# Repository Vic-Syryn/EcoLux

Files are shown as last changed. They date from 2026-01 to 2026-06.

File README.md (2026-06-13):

# EcoLux
Ecolux, een slim product dat energieverlies beperkt 

🛠️ Built by ``Viktor Caluwaert``, ``Yenthe Bode`` & ``Vic Syryn``   
🔥 Supervised by ``prof. dr. Bas Baccarne``, ``Yannick Christiaens`` & ``Wouter Devriese``    
🌱 Grown at ``Ghent University`` 🏛️ ``Industrial Design Engineering`` ([project overview](https://github.com/basbaccarne/human-centered-design))       

13/11/2025  

## Samenvatting
EcoLux is een slim energiefeedbacksysteem dat bewuste gezinnen helpt om verborgen energieverlies in huis sneller op te merken en er eenvoudiger op te reageren. Uit het gebruikersonderzoek blijkt dat het zelfden voorkomt dat iedereen in het gezin betrokken is bij energiebesparing, dat sluipverbruik vaak onbewust blijft aanstaan en dat bestaande slimme oplossingen vaak te technisch, app-gericht of datagedreven aanvoelen. EcoLux wil daarom energieverlies zichtbaar maken op een laagdrempelige, passieve en begrijpelijke manier.

Het project evolueerde van een algemeen concept rond energiezuinig renoveren naar een concreet fysiek product voor energiebewuste gezinnen: een subtiele slimme bloempot die als hoofdstation in het interieur staat. Het systeem combineert een geïntegreerd touchscreen, een visuele plattegrondinterface, lichtfeedback en slimme koppelingen met toestellen in huis. Wanneer een toestel energie verspilt, toont EcoLux duidelijk in welke ruimte het energieverlies zich bevindt en kan de gebruiker snel ingrijpen of het toestel laten uitschakelen. De instellingen van de gebruiker bepalen wanneer de EcoLux een toestel als energieverspiller beschouwt.

Door iteratieve gebruikerstesten werd het ontwerp stap voor stap verfijnd. 

Met EcoLux willen we gezinnen helpen om energieverspilling te verminderen zonder extra complexiteit toe te voegen aan hun dagelijkse routines. Het product maakt onzichtbaar energieverlies zichtbaar, verlaagt de drempel tot actie en ondersteunt bewuster energiegedrag met behoud van comfort en controle. 
<p align="center">
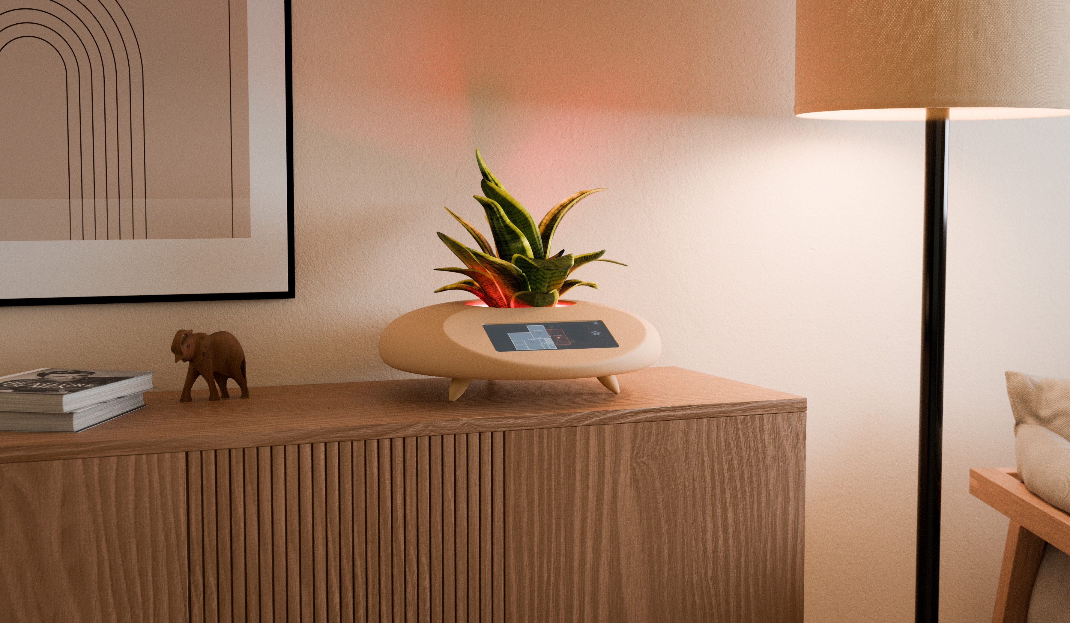
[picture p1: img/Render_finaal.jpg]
  
</p>
<p align="center">
render EcoLux</p>

## Introductie

De woningsector speelt een cruciale rol in de huidige energie- en klimaatproblematiek. In Europa is ongeveer 40% van het totale energieverbruik toe te schrijven aan gebouwen, waarvan een groot aandeel afkomstig is van woningen (European Commission, 2023) [^1]. Ondanks technologische vooruitgang en een toenemend aanbod aan slimme energiesystemen, blijft energiebesparing in het dagelijkse leven moeilijk te realiseren. Veel huishoudens beschikken wel over data, maar missen inzicht of motivatie om hun gedrag effectief aan te passen (Thomas & Ritter, 2022) [^2].

De energiecrisis ten gevolge van de oorlog in Oekraïne maakte deze problematiek extra zichtbaar: stijgende energieprijzen dwongen gezinnen om hun verbruik te verminderen, wat resulteerde in een duidelijke gedragsverandering (IEA, 2023) [^3]. Toch bleek deze besparing vaak tijdelijk en sterk afhankelijk van externe druk, wat wijst op een gebrek aan motivatie om te besparen.

Dit project vertrekt vanuit de vaststelling dat bestaande slimme oplossingen voornamelijk inzetten op schermen, apps en numerieke data, wat leidt tot cognitieve belasting en beperkte langetermijnimpact (Norman, 2013) [^4] (Lockton et al., 2010) [^5]. Er is nood aan alternatieve vormen van feedback die energieverbruik op een intuïtieve, laagdrempelige en emotioneel begrijpbare manier zichtbaar maken in het dagelijkse leven.

Het doel van dit project is het verkennen en definiëren van ontwerpprincipes voor een slim, fysiek product dat energieverspilling detecteert en communiceert via eenvoudige visuele en tastbare feedback, zonder voortdurend afhankelijk te zijn van een app. Boundary conditions binnen dit project zijn onder meer minimale technische achtergrond, minimale gebruikersinspanning en het product dient gebruikt te worden binnen een residentiële omgeving.

## Inhoudstafel

1. [Methodologie](./docs/methodologie.md)
2. [Discovery](./docs/discovery.md)
3. [Definition](./docs/definition.md)
4. [Develop 1](./docs/develop1.md)
5. [Develop 2](./docs/develop2.md)
6. [Develop 3](./docs/develop3.md)
7. [Develop 4](./docs/develop4.md)
8. [Conclusie](./docs/conclusie.md)
9. [Design Requirements](./docs/design_requirements.md)
10. [Bill of materials](./docs/bom.md)

## Kritische reflectie
De discoveryfase gaf een goed beeld van waarom mensen wel willen besparen, maar dit in de praktijk vaak niet lukt. Door bij mensen thuis te observeren en te praten over hun gewoontes, werd duidelijk waar energieverlies ontstaat en waarom dit vaak niet opvalt. Toch waren er maar drie huishoudens onderzocht, waardoor niet alle soorten gebruikers meegenomen zijn (bv. grotere gezinnen, huurders of mensen met andere levensstijlen). Ook kan het zijn dat deelnemers zich anders gedroegen omdat er iemand aanwezig was tijdens het onderzoek, waardoor ze bewuster met energie omgingen dan normaal.

Het benchmarkonderzoek maakte duidelijk dat de meeste bestaande oplossingen vooral werken met cijfers, grafieken en apps. Dit was nuttig om te zien wat al bestaat en wat ontbreekt. Maar het resultaat hangt ook af van welke producten gekozen werden, waardoor sommige alternatieven mogelijk niet in de vergelijking zijn terechtgekomen. Bovendien werd in deze fase vooral gekeken naar communicatie en feedback, en minder naar zaken zoals installatiegemak, onderhoud of langdurig gebruik.
De definition fase werd opgedeeld in 2 waves. Hoewel beide waves waardevolle inzichten opleverden over communicatie, functionaliteit en gebruikersverwachtingen, zijn er enkele beperkingen die de interpretatie van de resultaten beïnvloeden. 
Bij Wave 1 werd gewerkt met quick-and-dirty prototypes, wat geschikt is voor snelle exploratie, maar waardoor bepaalde interacties en reacties mogelijk anders zouden zijn in een realistisch, afgewerkt product. Vooral bij emotie- en vormcommunicatie kan de mate van afwerking de intuïtiviteit sterk beïnvloeden.

In Wave 2 werd vooral gefocust op drie interfaces, maar de vergelijking tussen spraak, tekst en grondplan blijft afhankelijk van hoe goed elke interface uitgewerkt was. Verder was de steekproef beperkt en mogelijk niet representatief voor alle doelgroepen (bv. professioneel vs gezin).
De develop fase werd opgedeeld in 3 fases.
De Develop 1-fase hielp om het concept verder te concretiseren via een aangepaste doelgroep en een conceptkeuze met behulp van een scorematrix. Hoewel dit structuur gaf aan het ontwerpproces, bleven sommige keuzes deels gebaseerd op aannames, zoals de interpretatie van de bloempot als ecologische metafoor. De analyse-tools maakten de interacties binnen het systeem duidelijker, maar toonden ook dat bepaalde aspecten, zoals de communicatie van energieverliezen, nog onvoldoende uitgewerkt waren. De gebruikerstesten brachten belangrijke problemen rond interactie, stabiliteit en ergonomie aan het licht, wat uiteindelijk leidde tot het loslaten van het mechanisch complexe uitschuifbare scherm ten gunste van een eenvoudiger ontwerp.

De Develop 2-fase maakte het mogelijk om het concept verder te verfijnen op vlak van ergonomie, vormgeving en interactie. Door gebruik te maken van ergonomische simulaties in Siemens Jack en fysieke prototypes werd duidelijk welke schermhoek, schermgrootte en vorm het meest comfortabel en gebruiksvriendelijk waren. Toch blijven er ook enkele beperkingen binnen deze fase. Zo werd gewerkt met relatief eenvoudige schuimmodellen en gerenderde visualisaties, waardoor aspecten zoals materiaalgevoel, gewicht en afwerkingskwaliteit nog niet realistisch konden worden ervaren. Hierdoor kunnen bepaalde reacties op esthetiek of gebruiksgemak verschillen van hoe gebruikers een finaal product zouden beoordelen. Daarnaast waren de gebruikerstesten gebaseerd op een beperkte steekproef van vijf respondenten, waardoor voorkeuren rond vorm en interface niet noodzakelijk representatief zijn voor alle gebruikers. Ook de validatie van de ergonomie gebeurde voornamelijk in statische situaties en hield minder rekening met langdurig gebruik of verschillende gebruikscontexten binnen de woning. Verder bleef de interface vooral gericht op begrijpelijkheid en visuele eenvoud, terwijl aspecten zoals toegankelijkheid voor personen met beperkingen minder uitgebreid onderzocht werden. De geschatte besparing van ongeveer €100 per jaar geeft een nuttige indicatie van de mogelijke financiële meerwaarde, maar blijft gebaseerd op aannames rond gebruik, energieprijzen, sluipverbruik en het aantal gekoppelde toestellen. Daarom mag deze waarde niet als gegarandeerde besparing worden voorgesteld. De besparing moet voorzichtig wordt geformuleerd als een realistische schatting die in de praktijk verder gevalideerd moet worden.

De Develop 3-fase bood waardevolle inzichten in de emotionele beleving, servicecontext en CMF-keuzes van EcoLux. Door gebruikers niet alleen te laten reageren op functionaliteit, maar ook op uitstraling, materialen en integratie binnen het interieur, werd duidelijk hoe belangrijk vertrouwen, rust en subtiliteit zijn binnen het concept. Toch kent ook deze fase enkele beperkingen. De evaluatie van kleuren, materialen en afwerkingen gebeurde hoofdzakelijk aan de hand van renders en touch-and-feel borden, waardoor de ervaring van een echt afgewerkt product nog ontbrak. Factoren zoals slijtage, onderhoud, lichtinval of langdurige perceptie konden hierdoor niet getest worden. Daarnaast focuste het service design vooral op hypothetische scenario’s en verwachte gebruikerservaringen, zonder langdurige praktijkvalidatie van het volledige ecosysteem. Ook hier bleef het aantal deelnemers beperkt, waardoor culturele voorkeuren, verschillen in wooncontext of technologische ervaring mogelijk onvoldoende vertegenwoordigd zijn. Tot slot werd vooral gekeken naar de gewenste emotionele uitstraling van het product, terwijl de impact van langdurige notificaties, automatisatie of gedragsverandering op lange termijn nog onvoldoende onderzocht werd.

Develop 4 was een belangrijke fase omdat EcoLux hier technisch werd gevalideerd. Het prototype toont aan dat de kernonderdelen kunnen samenwerken: het aanraakscherm, de software op de Raspberry Pi, de Matter-koppeling met slimme apparaten en de Arduino met LED-feedback. Een sterk punt van deze fase is dat de digitale en fysieke feedback samenkomen in één werkend systeem. Dit ondersteunt het centrale idee van EcoLux: verborgen energieverlies zichtbaar maken op een eenvoudige en laagdrempelige manier. Ook de keuze voor Matter is logisch, omdat dit EcoLux toekomstgerichter en compatibeler maakt met verschillende smart-homeapparaten. Toch blijft deze fase vooral een proof of concept. De werking werd technisch aangetoond, maar nog niet uitgebreid getest in een echte wooncontext of over een langere periode. Vooral betrouwbaarheid, foutafhandeling, langdurig gebruik en de integratie van de hardware in het product is beperkt onderzocht. Deze fase bevestigt dus de technische haalbaarheid van EcoLux, maar toont ook dat verdere verfijning nodig is voordat het systeem als volledig afgewerkt product kan worden beschouwd.

## Noot inzake het gebruik van AI
Voor het herschrijven van delen van dit verslag, het behalen van het juiste aantal woorden en het uitvoeren van taalcorrecties werd gebruikgemaakt van AI.
## Bijlagen
### Discovery
* Interviews (N=3)
  * [Protocol](https://github.com/Vic-Syryn/EcoLux/blob/875a4df8cc1cdf13c941e3fcb967883e65fc3608/reports%20and%20protocols/Contextual_Inquiry_Testing_Protocol.pdf)
  * [Rapport](https://github.com/Vic-Syryn/EcoLux/blob/875a4df8cc1cdf13c941e3fcb967883e65fc3608/reports%20and%20protocols/Contextual_Inquiry_Report.pdf)
* Benchmarkonderzoek (N=10)
  * [Protocol](https://github.com/Vic-Syryn/EcoLux/blob/875a4df8cc1cdf13c941e3fcb967883e65fc3608/reports%20and%20protocols/Benchmarkanalyse_Testing_Protocol.pdf)
  * [Rapport](https://github.com/Vic-Syryn/EcoLux/blob/875a4df8cc1cdf13c941e3fcb967883e65fc3608/reports%20and%20protocols/Benchmarkanalyse_Report.pdf)
    
### Definition
* User testing wave 1 (N=3)
  * [Protocol](https://github.com/Vic-Syryn/EcoLux/blob/94d3a5f92b4216017caaa046f698b3564b813192/reports%20and%20protocols/Ecolux_Protocol_Gebruikerstesten_Wave_1.pdf)
  * [Rapport](https://github.com/Vic-Syryn/EcoLux/blob/94d3a5f92b4216017caaa046f698b3564b813192/reports%20and%20protocols/Ecolux_Report_Gebruikerstesten_Wave_1.pdf)
* User testing wave 2 (N=3)
  * [Protocol](https://github.com/Vic-Syryn/EcoLux/blob/main/reports%20and%20protocols/Ecolux_Protocol_Gebruikerstesten_Wave_2%20(1).pdf)
  * [Rapport](https://github.com/Vic-Syryn/EcoLux/blob/main/reports%20and%20protocols/Ecolux_Report_Gebruikerstesten_Wave_2%20(2).pdf)

### Develop
* User testing fase 1 (N=5)
  * [Protocol](https://github.com/Vic-Syryn/EcoLux/blob/main/reports%20and%20protocols/EcoLux_Protocol_Gebruikerstesten_Develop_1_EcoLux.pdf)
  * [Rapport](https://github.com/Vic-Syryn/EcoLux/blob/main/reports%20and%20protocols/EcoLux_Report_Gebruikerstesten_Develop_1_EcoLux.pdf)
* User testing fase 2 (N=5)
  * [Protocol](https://github.com/Vic-Syryn/EcoLux/blob/main/reports%20and%20protocols/Ecolux_Gebruikerstesten_Develop2_Protocol.pdf)
  * [Rapport](https://github.com/Vic-Syryn/EcoLux/blob/main/reports%20and%20protocols/EcoLux_Gebruikerstesten_Develop2_Report.pdf)
* User testing fase 3 (N=4)
  * [Protocol](https://github.com/Vic-Syryn/EcoLux/blob/main/reports%20and%20protocols/Ecolux_Gebruikerstesten_Develop3_Protocol.pdf)
  * [Rapport](https://github.com/Vic-Syryn/EcoLux/blob/main/reports%20and%20protocols/Ecolux_Gebruikerstesten_Develop3_Report.pdf)

## Licentie

This repository contains both software and design materials created as part of an industrial design energineering project at Ghent University.

- **Software and code:** [MIT License](./LICENSE-MIT)  
- **Design, documentation, CAD, and media:** [CC BY 4.0 License](./LICENSE)
  
You are free to reuse and build upon this work, both commercially and non-commercially, as long as proper attribution is given to the original authors.

## Bronnen
> [^x]: Thomas, T., & Ritter, A. (2022). Wandering & sundowning in dementia. _Practical Neurology, 21_(3), 36–44.

[^1]: European Commission. (2023). Energy efficiency in buildings.
https://energy.ec.europa.eu/topics/energy-efficiency/energy-efficient-buildings_en

[^2]: International Energy Agency. (2023). Energy saving behaviour in response to the energy crisis.
https://www.iea.org/reports/energy-saving-behaviour-in-response-to-the-energy-crisis

[^3]: Lockton, D., Harrison, D., & Stanton, N. A. (2010). The design with intent method: A design tool for influencing user behaviour. Applied Ergonomics, 41(3), 382–392.
https://doi.org/10.1016/j.apergo.2009.09.001

[^4]: Norman, D. A. (2013). The design of everyday things (Revised and expanded ed.). Basic Books.

[^5]: Thomas, V., & Ritter, S. (2022). Behavioural barriers to household energy efficiency: A systematic review. Energy Research & Social Science, 84, 102387.
https://doi.org/10.1016/j.erss.2021.102387

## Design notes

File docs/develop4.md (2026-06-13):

## Develop 4
In deze fase ligt de focus op de software en hardware van de EcoLux.
De bedoeling van deze fase is om de functionaliteit van de EcoLux te valideren. 

## Inleiding
Het systeem bestaat uit vier onderdelen die samenwerken: het aanraakscherm, de achterliggende software, de verbinding met slimme apparaten, en het fysieke waarschuwingslampje.

## Systeemarchitectuur

De vier onderdelen communiceren continu met elkaar:

| Onderdeel | Wat het doet | Hoe het communiceert |
|---|---|---|
| Aanraakscherm | Toont de plattegrond en apparaten | Stuurt verzoeken naar de software |
| Achterliggende software die draait op de Raspberry pi| Verwerkt alle informatie en onthoudt de staat | Stuurt opdrachten naar apparaten en lampje |
| Apparaatverbinding via Raspberry pi | Praat met slimme apparaten (lampen, stekkers...) | Via het Matter-protocol over het thuisnetwerk |
| Arduino + LED + Rotary Encoder + Lichtsensor | Fysieke indicator bij energieproblemen | Verbonden via USB-kabel met de Raspberry Pi |

## Verbinding met slimme apparaten (Matter)

EcoLux gebruikt **Matter**, een open standaard die werkt met slimme apparaten van veel verschillende merken. Een apart programma op de Raspberry Pi beheert alle gekoppelde apparaten en zorgt dat opdrachten (zoals "zet lamp uit") worden doorgegeven.

### Een nieuw apparaat koppelen

Wanneer je een nieuw slim apparaat wil toevoegen, doorloopt het systeem vier stappen:

1. Het apparaat maakt zichzelf bekend op het netwerk
2. Er wordt een beveiligde verbinding opgezet via een code
3. Na verificatie krijgt het apparaat toestemming om deel uit te maken van jouw netwerk
4. Vanaf dan verloopt alle communicatie via een beveiligd certificaat

## Achterliggende software

De achterliggende software is het brein van EcoLux. Het ontvangt vragen van het aanraakscherm, haalt informatie op bij de apparaten, en stuurt opdrachten terug. Het draait onzichtbaar op de achtergrond op de Raspberry Pi.

### Hoe wordt bijgehouden hoe lang iets aanstaat?

Elke keer dat het scherm de apparatenlijst opvraagt, vergelijkt de software of een apparaat net is aangedraaid. Als dat zo is, slaat het de huidige tijd op. Zo weet het scherm later precies hoe lang het apparaat al aanstaat.

### Beschikbare acties

| Actie | Wat er gebeurt |
|---|---|
| Apparatenlijst opvragen | Alle apparaten worden opgehaald, inclusief plaatsing en instellingen |
| Apparaat aan/uit/wisselen | Een opdracht wordt verstuurd naar het slimme apparaat |
| Plaatsing opslaan | Kamer en positie worden bewaard |
| Tijdsdrempel instellen | Instelling voor hoe lang een apparaat aan mag staan wordt opgeslagen |
| Nieuw apparaat koppelen | Apparaat wordt toegevoegd via een koppelcode |

## Aanraakscherm

Het aanraakscherm toont een overzicht van je huis en is speciaal ontworpen voor bediening met de vinger.

### Wat zie je?

1. **Plattegrondoverzicht** — alle kamers van je huis, aanklikbaar
2. **Kamerdetail** — de apparaten in een specifieke kamer, met de mogelijkheid ze te bedienen

### Wanneer wordt een kamer rood?

Het systeem berekent voortdurend hoe lang elk apparaat al aanstaat. Als dat langer is dan de ingestelde tijdsdrempel, kleurt de kamer rood op de plattegrond. De apparatenlijst wordt elke 5 seconden bijgewerkt.

### Een apparaat in een kamer plaatsen

Als je aangeeft waar een apparaat staat in de kamer, werkt dat als volgt:

1. Je kiest een kamer via een mini-plattegrond in het instellingenpaneel
2. De app navigeert automatisch naar die kamer
3. Er verschijnt een plaatsmodus: je cursor wordt een kruisje en bestaande apparaten worden iets vervaagd
4. Je klikt op de gewenste plek in de kamer
5. Na bevestiging wordt de positie opgeslagen

## Fysiek waarschuwingslampje (Arduino)

Naast het scherm is er een los lampje (in de realiteit zou dit een led strip zijn) dat oplicht wanneer er een energieprobleem is. Dit lampje is aangesloten op een kleine microcontroller (Arduino Uno) die via een USB-kabel verbonden is met de Raspberry Pi.

Het lampje past zijn helderheid automatisch aan op basis van het omgevingslicht, door middel van de lichtsensor, zodat het zowel overdag als 's avonds goed zichtbaar is. Met een draaiknop kan je de helderheid ook handmatig bijstellen. Omdat deze sensoren een analoog signaal leveren, was er nood aan een arduino, omdat deze over een ADC chip beschikt.

### Onderdelen

| Onderdeel | Aansluiting | Functie |
|---|---|---|
| Lichtsensor (LDR) | Analoge ingang | Meet hoe licht of donker het is in de ruimte |
| Draaiknop (encoder) | Digitale ingang | Handmatige fijnregeling van de helderheid |
| LED-lampje | PWM-uitgang | Knippert of brandt bij een energieprobleem |
| Weerstanden | Tussen componenten en arduino | Stroom beperken om componenten niet te beschadigen|
| Breadboard | / | Plaats om alle componenten te verbinden |
| Raspberry pi 3b+ | /| Hierop draaien al de programma's, dit is dus de centrale hub |
| Arduino UNO | / | Verbindingspunt Raspberry pi en fysieke componenten (ADC) |

<p align="center">
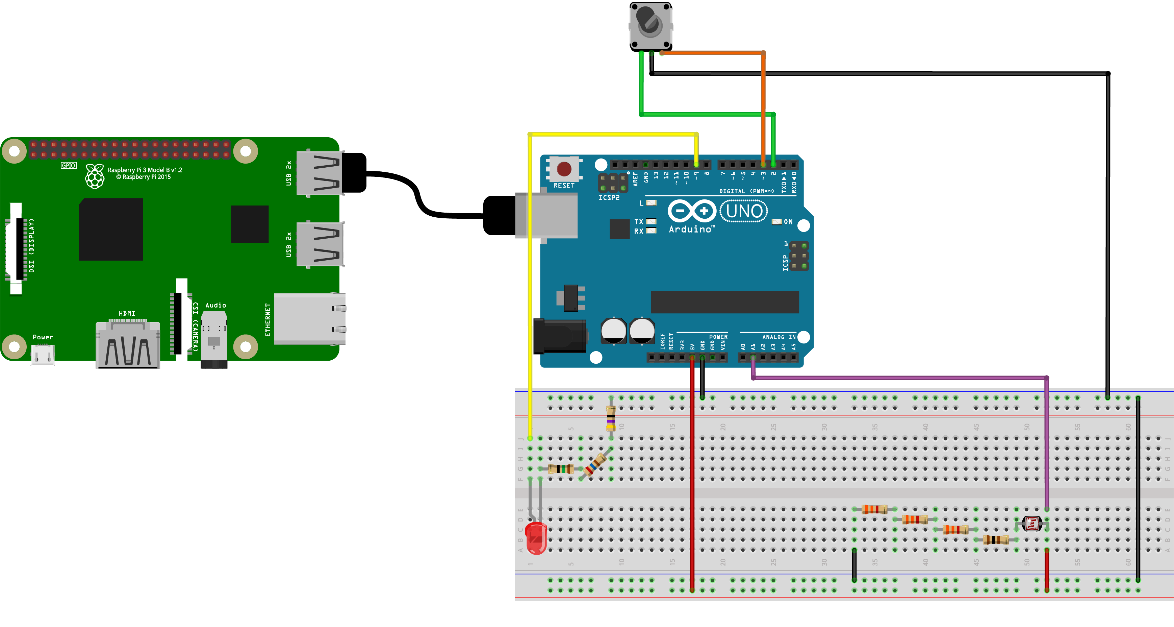
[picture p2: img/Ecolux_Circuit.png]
  
  Opstelling
<p align="center">

### Communicatie tussen Arduino en Raspberry Pi

De Arduino stuurt elke tiende van een seconde een klein berichtje naar de Pi met de huidige sensorwaarden en of het lampje aan of uit is. De Pi kan ook commando's terugsturen.

## Energiebewaking op de achtergrond

Naast de achterliggende software draait er nog een tweede programma op de Pi. Elke 10 seconden (ter illustratie) bekijkt dit programma alle apparaten die aanstaan. Als een apparaat de ingestelde tijdslimiet overschrijdt, stuurt het een waarschuwing naar de Arduino zodat het lampje gaat branden. Zodra het probleem opgelost is, wordt de waarschuwing automatisch uitgeschakeld.

## Wat gebeurt er stap voor stap bij een energieprobleem?

| Stap | Wat er gebeurt |
|---|---|
| 1 | Een apparaat gaat aan → de software onthoudt het tijdstip |
| 2 | Elke 10 seconden wordt gecontroleerd hoe lang apparaten al aanstaan |
| 3 | Een apparaat staat langer aan dan de ingestelde limiet |
| 4 | De software stuurt een waarschuwing naar het Arduino-lampje |
| 5 | Het LED-lampje gaat branden (helderheid afgestemd op de ruimte / rotary encoder) |
| 6 | Op het scherm kleurt de kamer rood |
| 7 | De gebruiker klikt op het apparaat en bevestigt dat het uit mag |
| 8 | Het apparaat wordt uitgeschakeld via het slimme netwerk |
| 9 | De software wist het tijdstip en stuurt een sein dat alles in orde is |
| 10 | Het LED-lampje gaat uit |

## Finale code en BOM
De finale code staat in de [Source](https://github.com/Vic-Syryn/EcoLux/tree/main/src).

De finale benodigdheden staan in de [BOM](./bom.md)

## Behuizing
Rond deze hardware moet er natuurlijk behuizing zijn om de EcoLux te vormen. De vorm is gebaseerd op de gebruikerstesten van develop 2. 
<p align="center">
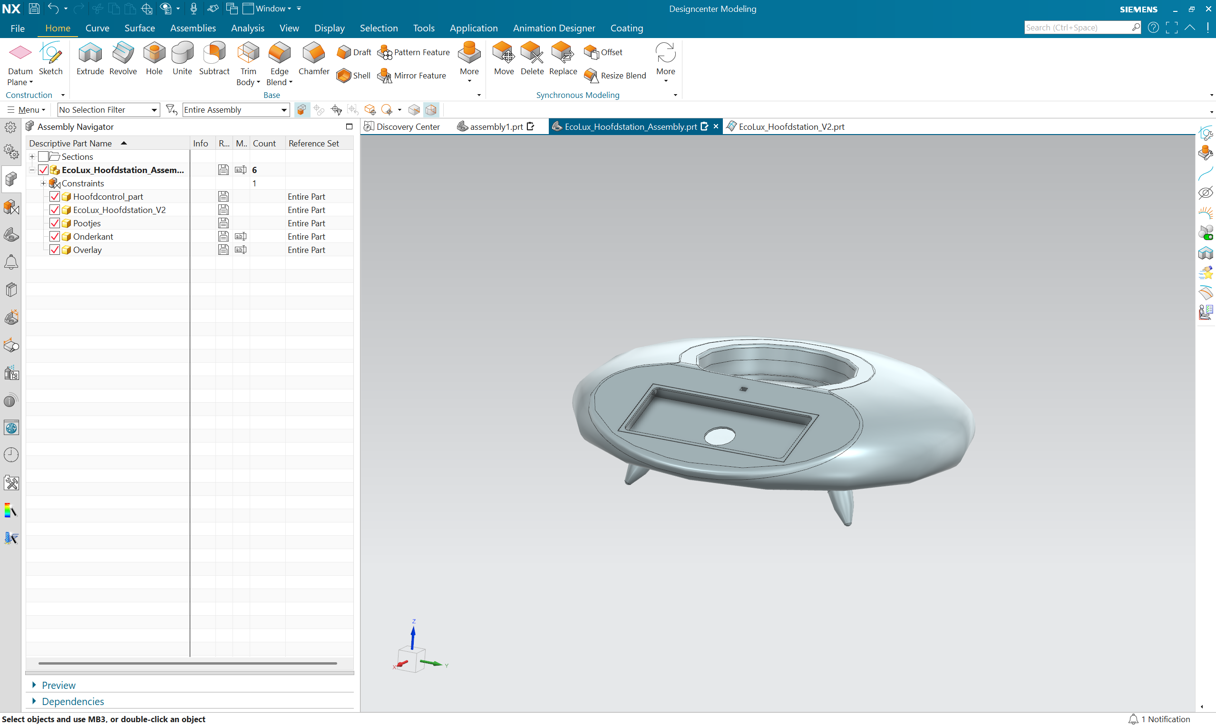
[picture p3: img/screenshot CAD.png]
  
  CAD bestand
<p align="center">

Dit model werd dan 3D geprint. In realiteit was het model te groot voor de 3D printer die we ter beschikking hadden en werd het model opgesplitst, zie de BOM.
<p align="center">
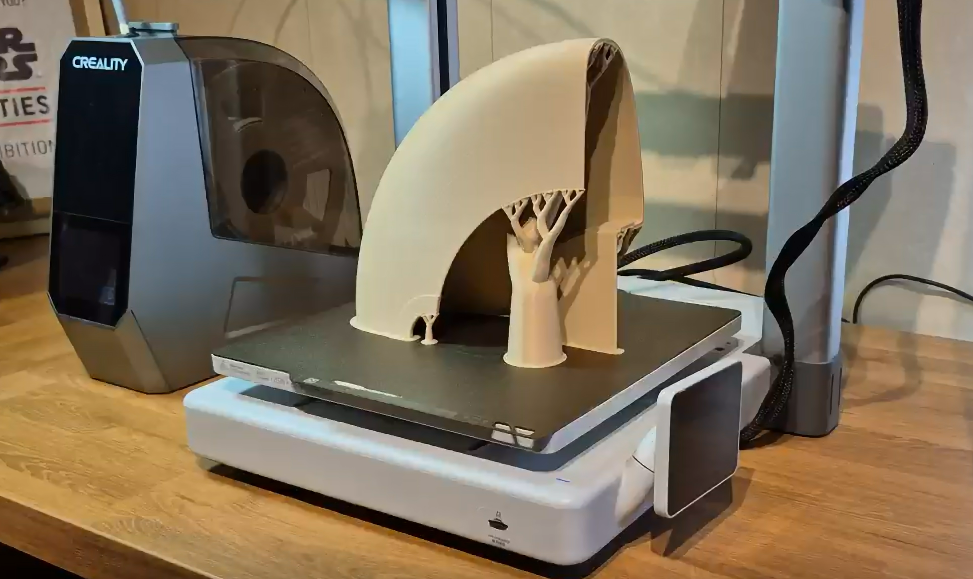
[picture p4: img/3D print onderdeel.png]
  
  3D print onderdeel
<p align="center">

<p align="center">
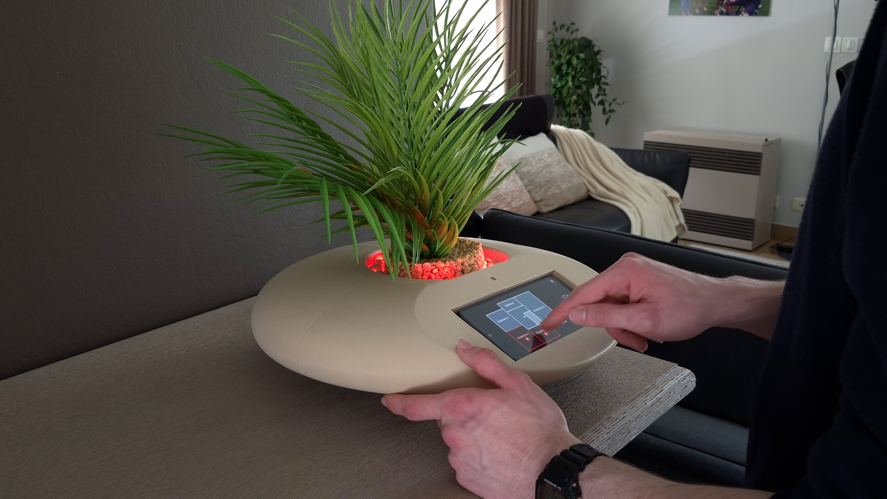
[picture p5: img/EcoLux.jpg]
  
  EcoLux
<p align="center">

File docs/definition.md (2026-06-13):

## Definition

### <ins>**Wave 1: Communicatie vorm exploratie**</ins>  

**Doestellingen**  

In de eerste wave werd onderzocht hoe het probleem initieel gecommuniceerd kan worden. De focus lag op functionaliteit en op de manier waarop energieverlies zichtbaar wordt gemaakt. Dit gebeurde via gebruikerstesten en interviews. Daarbij werden de volgende deelvragen beantwoord:  

   * Hoe communiceren we het best het energieverlies bij de gebruiker(awareness)?   
   * Hoe zou de gebruiker willen dat het product wordt geïnstalleerd?  
   * Wat is voor de gebruiker de belangrijkste feature waarom de gebruiker het zou kopen?  
   * Is een of meerdere substations noodzakelijk?  

**Materiaal & methoden**  

De doelstellingen werden onderzocht via gebruikerstests, gevolgd door een interview. Hiervoor werden de volgende materialen gebruikt:  

   * smartphone voor video opnamens  
   * notitieboekje voor notities  
   * interview protocol en informed consent  
   * 4 quick and dirty prototypes (in volgorde, van links naar rechts: emotie, vorm/shapeshifter, licht, substations)

<p align="center">
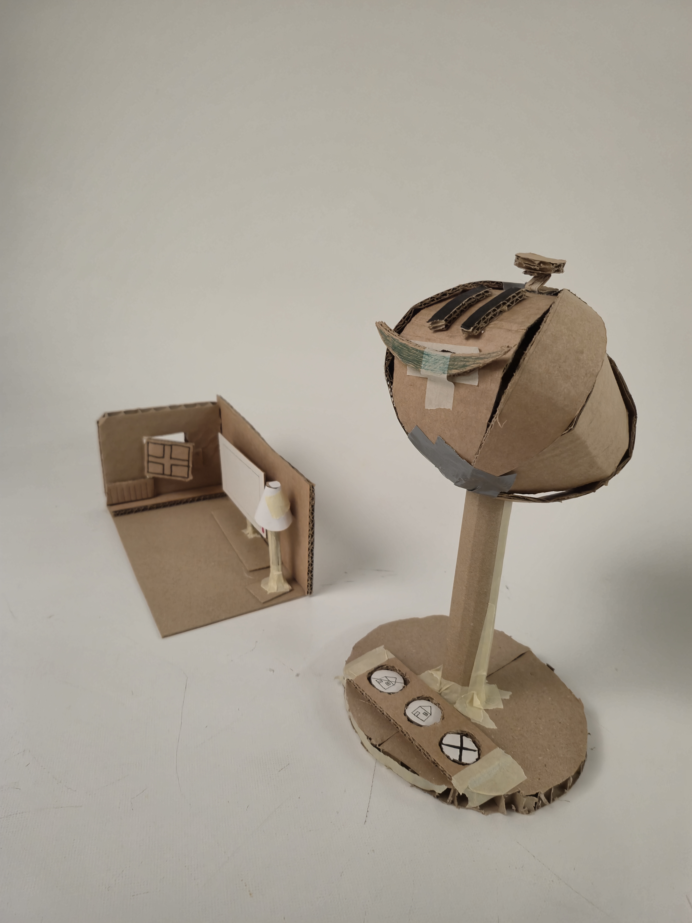
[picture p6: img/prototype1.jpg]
  
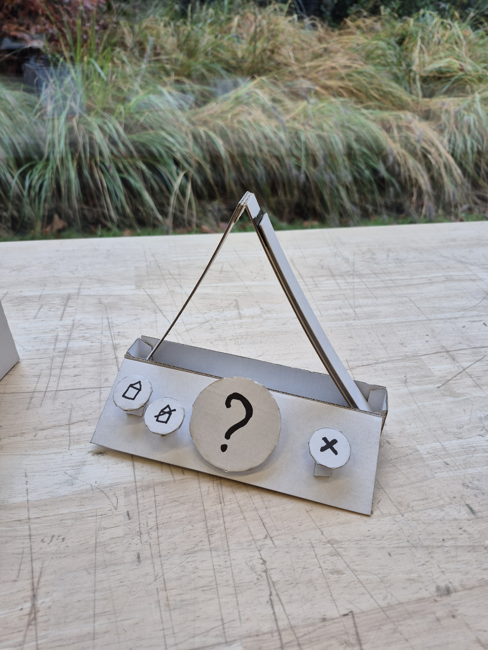
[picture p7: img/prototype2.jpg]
  
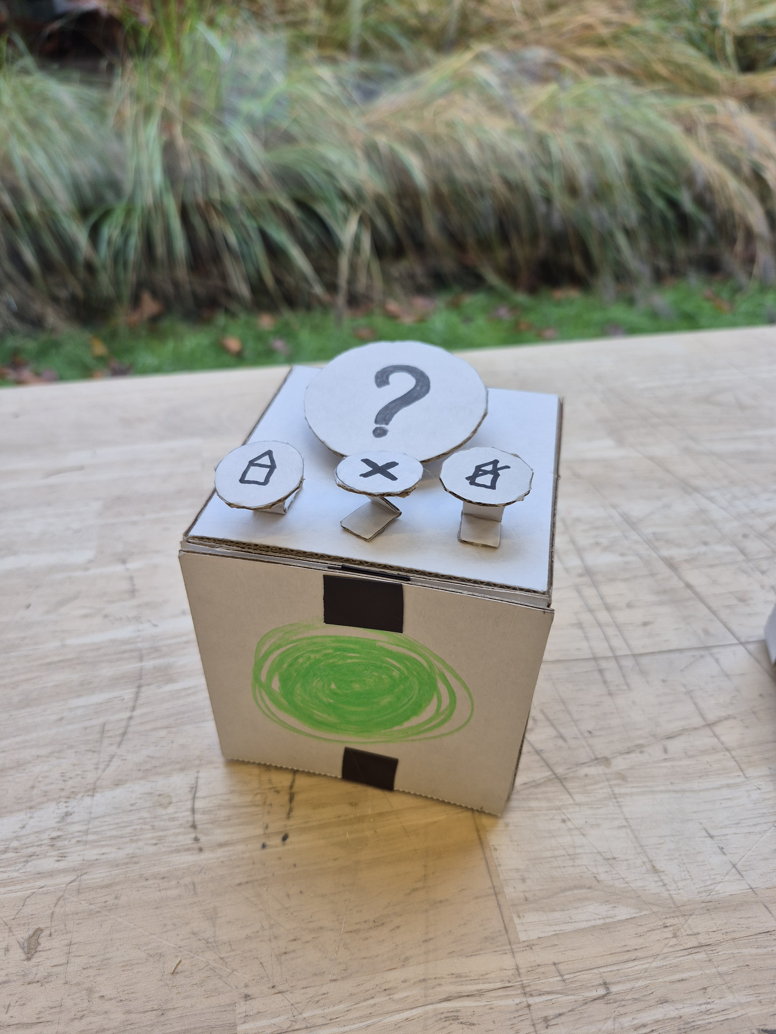
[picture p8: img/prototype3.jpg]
  
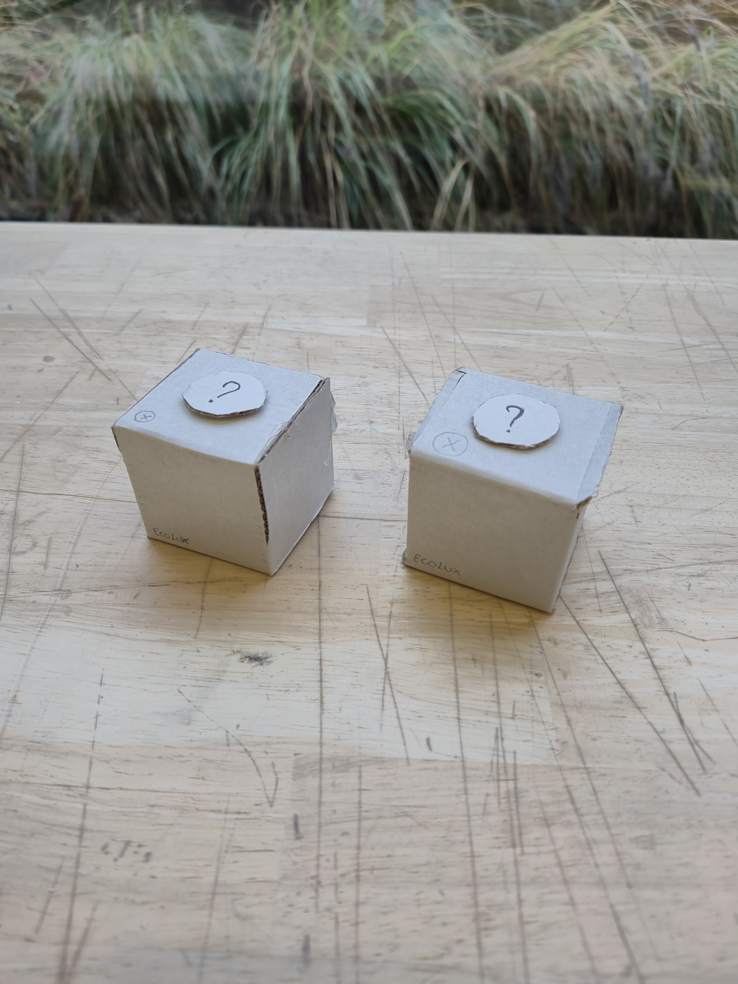
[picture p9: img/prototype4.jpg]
  
</p>
<p align="center">
fysieke prototypes</p>

De vier prototypes gaven gebruikers een fysieke voorstelling van verschillende communicatiemogelijkheden. De eerste drie prototypes meldden een probleem telkens op een andere manier: via emotie, vorm of licht. Het vierde prototype testte het concept van substations.

Tijdens de gebruikerstesten gingen gebruikers in interactie met de prototypes. Elk prototype werd getoond in twee modes: met en zonder energieverlies. Gebruikers konden de opstelling bekijken en passeren zoals in een normale situatie. Na alle prototypes volgde een interview over de volledige test. Er werd gekozen voor drie respondenten om efficiënt kwalitatieve inzichten te verzamelen.

<p align="center">
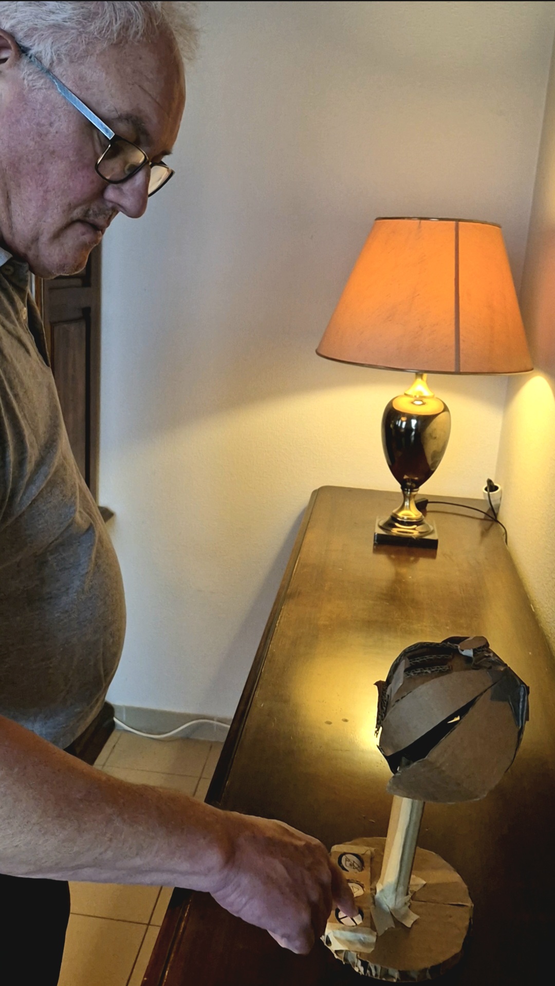
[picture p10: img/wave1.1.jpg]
  
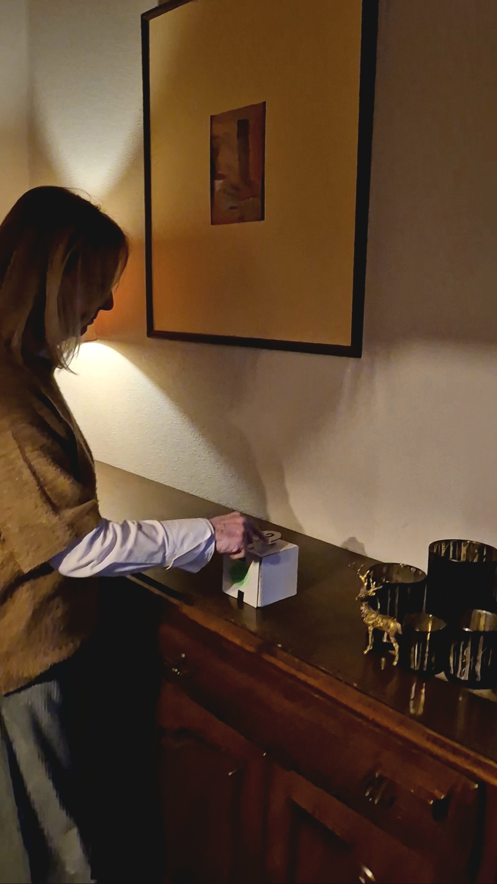
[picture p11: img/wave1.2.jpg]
  
</p>
<p align="center">
prototype gebruikerstest</p>

**Resultaten**  

Uit het onderzoek blijkt dat duidelijke signalen belangrijk zijn voor het gebruiksgemak. Lichtsignalen worden het meest duidelijk en intuïtief ervaren. Emoties worden begrepen, maar passen minder goed in professionele contexten. De shapeshifter wordt als minder intuïtief gezien, tenzij deze extra visueel ondersteund wordt.

Het smiley-prototype en de spraakfunctie zorgen voor een antropomorfe interpretatie. Gebruikers schrijven het systeem menselijke eigenschappen toe, zoals begrijpen, luisteren en reageren. Daardoor wilden sommige respondenten echt in gesprek gaan met de prototypes.

De gebruikscontext bepaalt de voorkeur in vormgeving. Voor gezinnen werkt een speels en visueel systeem, zoals een smiley, goed. In zakelijke omgevingen en volwassen thuissituaties gaat de voorkeur naar een strak en minimalistisch ontwerp, zoals een cube.

Een persoonlijk aanpasbaar design verhoogt de betrokkenheid. Respondenten geven aan dat personaliseerbaarheid het gevoel versterkt dat het product echt van henzelf is.

Functioneel worden negeerknoppen en duidelijke voorinstellingen vaak genoemd. Substations verhogen de bruikbaarheid bij meerdere kamers of ingangen. Handsfree bediening helpt vooral in huishoudens waar veel wordt gemultitaskt. Spraakbediening kan daarbij een meerwaarde hebben, bijvoorbeeld wanneer het systeem pas luistert zodra er effectief iets gebeurt.

Voor installatie geven alle respondenten aan dat plaatsing liefst door een technieker of installateur gebeurt. Eén respondent vindt het wel belangrijk dat zelfinstallatie mogelijk blijft.

### <ins>**Wave 2: Communicatie energieprobleem**</ins>  

**Doestellingen**  

In Wave 1 lag de focus op awareness, installatie en basisfunctionaliteit. In Wave 2 werd verder ingezoomd op communicatie, automatisatie en de negeerfunctie. Concreet moesten drie deelvragen beantwoord worden: 

* Hoe brengen we de informatie van het energieverlies het best over?
* Wat verwacht de gebruiker dat de Ecolux automatisch doet en wat er manueel moet gebeuren, moet dit instelbaar zijn? 
* Hoe zou de negeerfunctie het best gebruikt worden?  

**Materiaal & methoden**

Voor dit onderzoek werd gekozen voor gebruikerstesten volgens het TAP (thinking aloud protocol) en QAP (question asking protocol). Zo konden we gedrag in context observeren en tegelijk motivaties en voorkeuren bevragen. De methode maakte gerichte feedback op de prototypes mogelijk. Ze was praktijkgericht, snel uitvoerbaar en geschikt voor conceptevaluatie.

De test werd uitgevoerd bij de respondenten. Voor deze gebruikerstesten werden drie mogelijke gebruikers gekozen. Dit aantal liet toe om efficiënt kwalitatieve inzichten te verzamelen. De test verliep volgens een vaste structuur: introductie en informed consent, presentatie van het EcoLux-concept, testen van prototypes, observatie met interviewvragen en een afsluitende wrap-up. 

Materialen:

* 1 prototype (Protopie) met drie interfaces (spraak, tekst en grondplan)

* smartphone voor de interface

* smartphone voor opnames

* protocol + informed consent 

<p align="center">
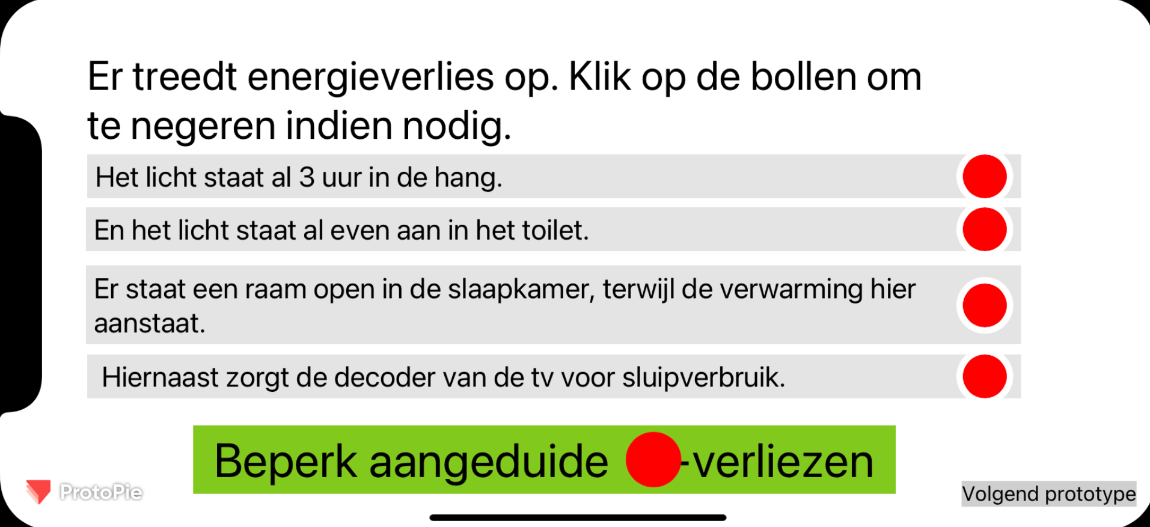
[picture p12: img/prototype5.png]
  
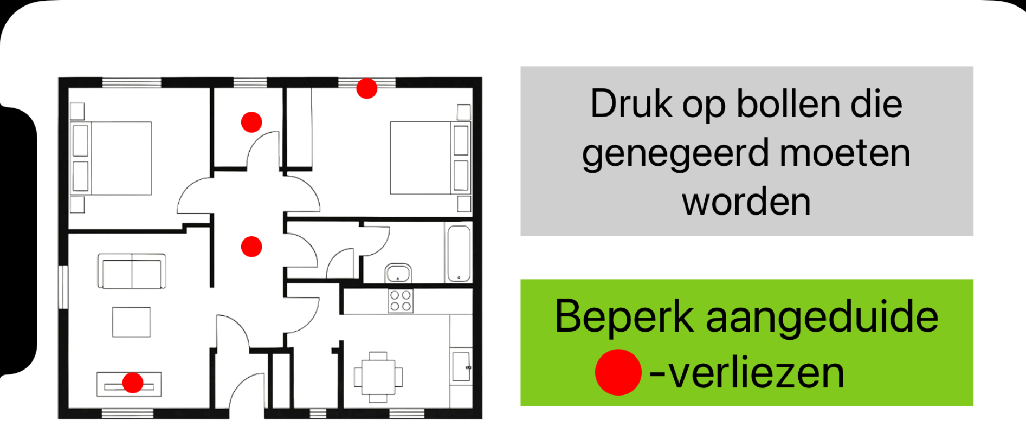
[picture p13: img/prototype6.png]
  
</p>
<p align="center">
app interface</p>

Om informatie met de gebruiker te delen, kan auditieve of visuele communicatie gebruikt worden. Voor visuele communicatie werden twee prototypes gemaakt, omdat deze richting meer mogelijkheden bood. De twee visuele prototypes waren gebaseerd op tekst en op foto.

<p align="center">
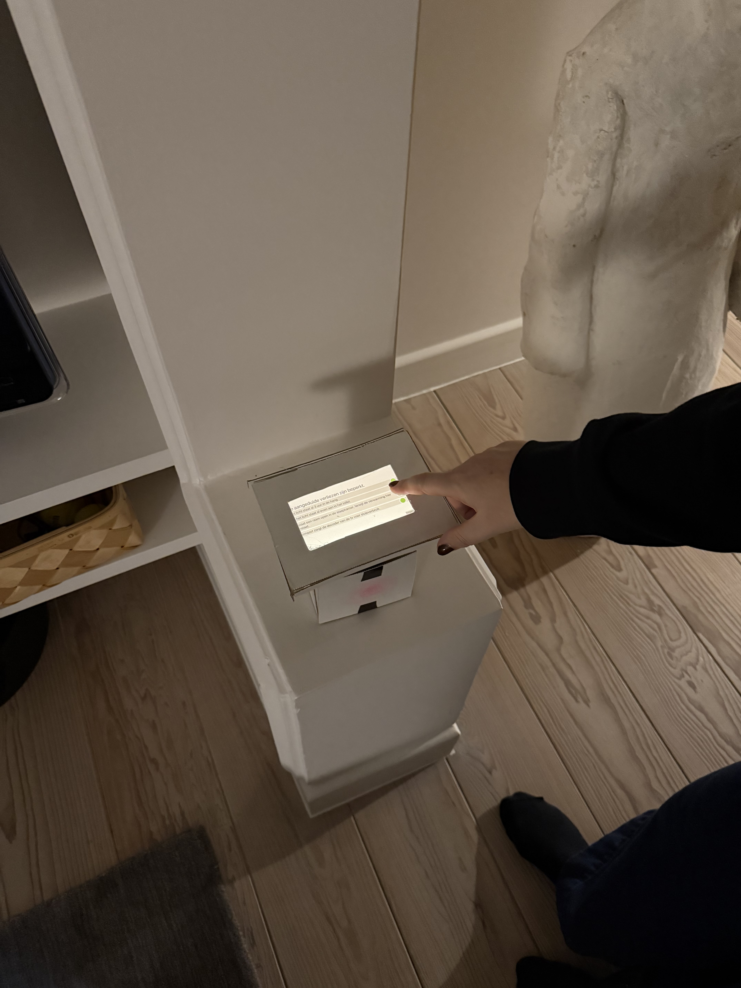
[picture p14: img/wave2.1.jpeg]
  
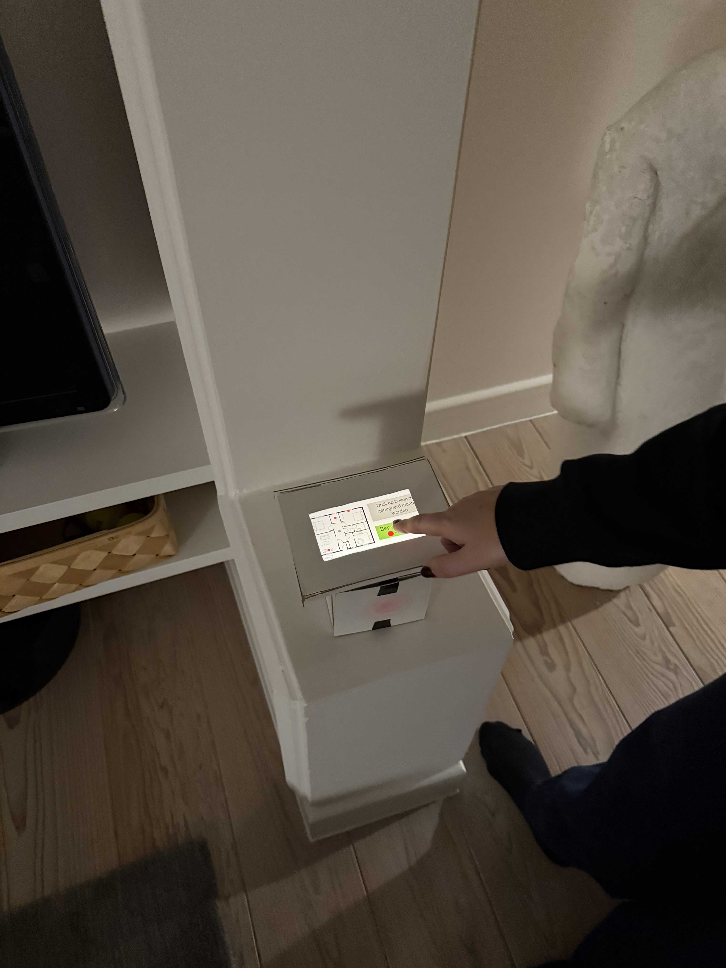
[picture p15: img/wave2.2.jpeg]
  
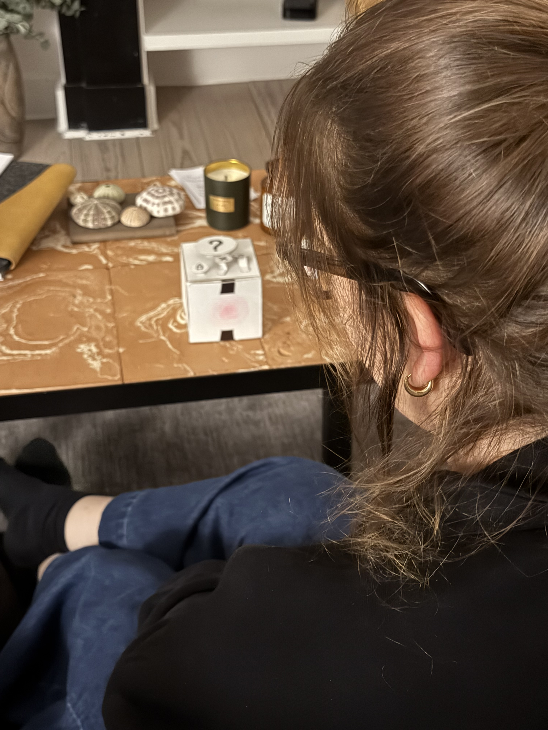
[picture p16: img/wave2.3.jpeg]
  

</p>
<p align="center">
prototypes gebruikerstest</p>

**Resultaten**

De resultaten tonen dat spraak duidelijk kan zijn, maar minder geschikt is bij veel informatie. Respondenten vonden het dan moeilijk om alles te onthouden en correct te herhalen. Sommigen vonden spraak ook te traag, zeker wanneer ze liever meteen actie ondernemen of verwachten dat EcoLux automatisch ingrijpt.

Tekst werd gezien als handig om snel te scannen en direct te handelen. Toch gaf tekst soms te weinig context. Met beperkte tekst was niet altijd duidelijk waar het probleem zich precies bevond. De tekstweergave kon ook druk ogen wanneer er weinig witruimte was.

De grondplanweergave scoorde het best. Respondenten zagen meteen waar het energieverlies zich bevond. Daardoor werd snelle actie mogelijk. Alle testers verkozen deze visuele methode boven tekst en spraak.

Voor automatisatie was de voorkeur duidelijk. Gebruikers wilden dat EcoLux zoveel mogelijk automatisch oplost. Voor hen hoeft dit niet uitgebreid instelbaar te zijn. De belangrijkste inzichten zijn dus dat visuele communicatie het sterkst werkt, snelheid essentieel is en maximale automatisatie aansluit bij gebruikersverwachtingen.

### Conclusies & implicaties

Wave 1 toont dat duidelijke signalen bepalend zijn voor gebruiksgemak. Lichtsignalen worden het meest intuïtief ervaren. Emotie en vorm zijn minder geschikt in professionele contexten. De voorkeur voor vormgeving hangt sterk af van de omgeving: speels voor gezinnen, strak en minimalistisch voor volwassen of zakelijke settings.

Personalisatie verhoogt de betrokkenheid. Functioneel zijn negeerknoppen, duidelijke presets, handsfree bediening en substations belangrijk. Dit geldt vooral in grotere woningen. Installatie gebeurt idealiter door een technieker, met een optie voor zelfinstallatie.

Wave 2 bevestigt dat visuele communicatie het best werkt. De grondplanweergave maakt energieverlies meteen begrijpelijk en actiegericht. Spraak is minder efficiënt bij veel informatie. Tekst moet voldoende context en witruimte bieden. Gebruikers verwachten bovendien maximale automatisatie.

Op basis van deze conclusies werden de volgende designimplicaties geformuleerd:

| Observatie uit onderzoek | Inzicht | Designimplicatie |
| --- | --- | --- |
| Lichtsignalen worden het meest duidelijk en intuïtief ervaren. | Heldere, directe visuele feedback verlaagt cognitieve belasting. | EcoLux gebruikt licht als primaire feedbackmechaniek. |
| Gebruikers vroegen zich af of het wel in hun interieur past.| Het product moet aanpasbaar zijn zodat het in elk interieur past|Ecolux is esthetisch personaliseerbaar om aan te sluiten bij verschillende gebruikers en interieurs.|
|Gebruikers zijn niet altijd in dezelfde kamer.| Er moet een manier zijn waardoor de gebruiker in een andere kamer ook het energieverlies kan detecteren.|EcoLux heeft een modulair ontwerp met één hoofdstation en uitbreidbare substations.|
|Gebruiker ging het best om met de tekst en grondplan.|De gebruiker heeft voorkeur voor visuele weergave.| EcoLux communiceert energieverliezen via een visuele weergave die de locatie in de woning duidelijk maakt.|
 |Gebruiker heeft weinig geduld.| Gebruiker wil direct actie uitvoeren.| EcoLux ondersteunt snelle uitvoering van actie zodra een energieverlies wordt gedetecteerd.|
 |De gebruiker heeft weinig geduld.|Gebruiker wil dat er snel actie wordt uitgevoerd|EcoLux automatiseert het oplossen van energieproblemen maximaal, zodat de gebruiker zo weinig mogelijk handelingen hoeft uit te voeren.|

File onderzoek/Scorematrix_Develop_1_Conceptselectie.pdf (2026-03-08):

# Scorematrix: Conceptselectie

Uit Tabel 1 blijkt dat de slimme bloempot de meest belovende optie is.

Tabel 1: Scorematrix

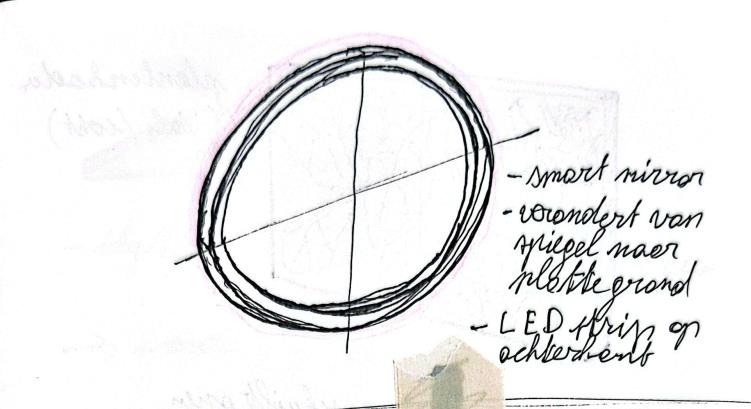
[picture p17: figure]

Figuur 1: Slimme Spiegel

Concepten | Efficiëntie (/10) | gebruiksgemak (/10) | Esthetiek (/10) | Haalbaarheid(/10) | Metaforisch (/5) | Totaal (/45)
Slimme spiegel | 7 | 5 | 8 | 7 | 1 | 28
Slimme bloempot | 8 | 8 | 8 | 8 | 4 | 36
LedBord | 8 | 7 | 5 | 3 | 2 | 25
Plantenprojector | 8 | 7 | 7 | 5 | 4 | 31
Skylight | 4 | 5 | 7 | 3 | 4 | 23
Slimme plantenkader | 8 | 8 | 7 | 8 | 4 | 35
Slimme fotokader | 9 | 8 | 8 | 6 | 1 | 32

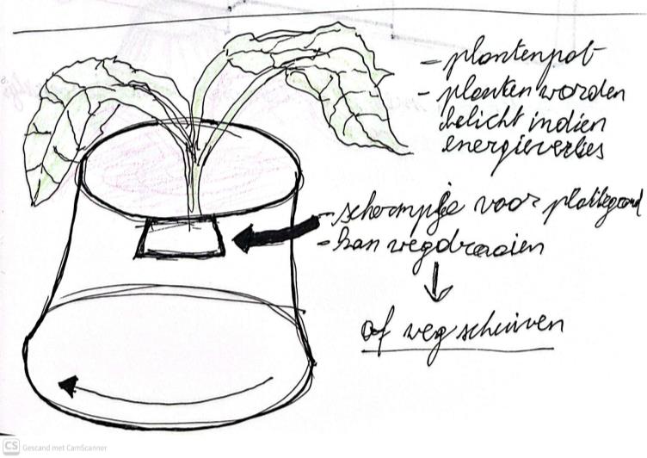
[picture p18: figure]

Figuur 2 : Slimme Bloempot

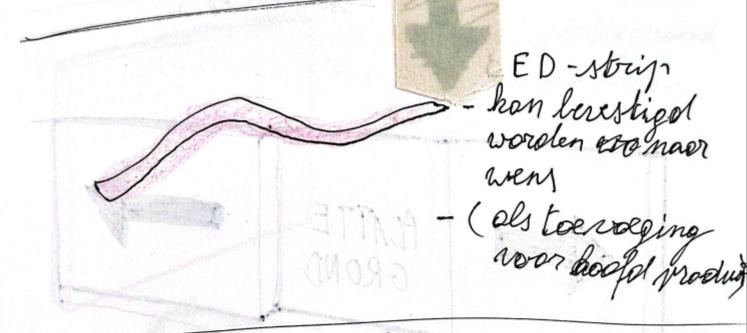
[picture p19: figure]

Figuur 3: Led Strip

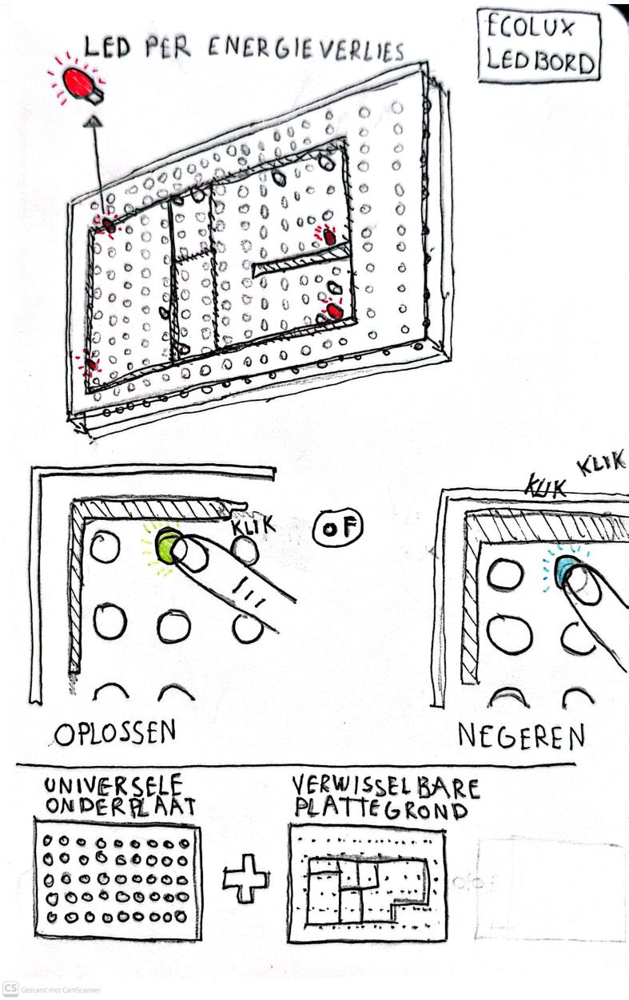
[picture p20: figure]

Figuur 4 : LED-Bord

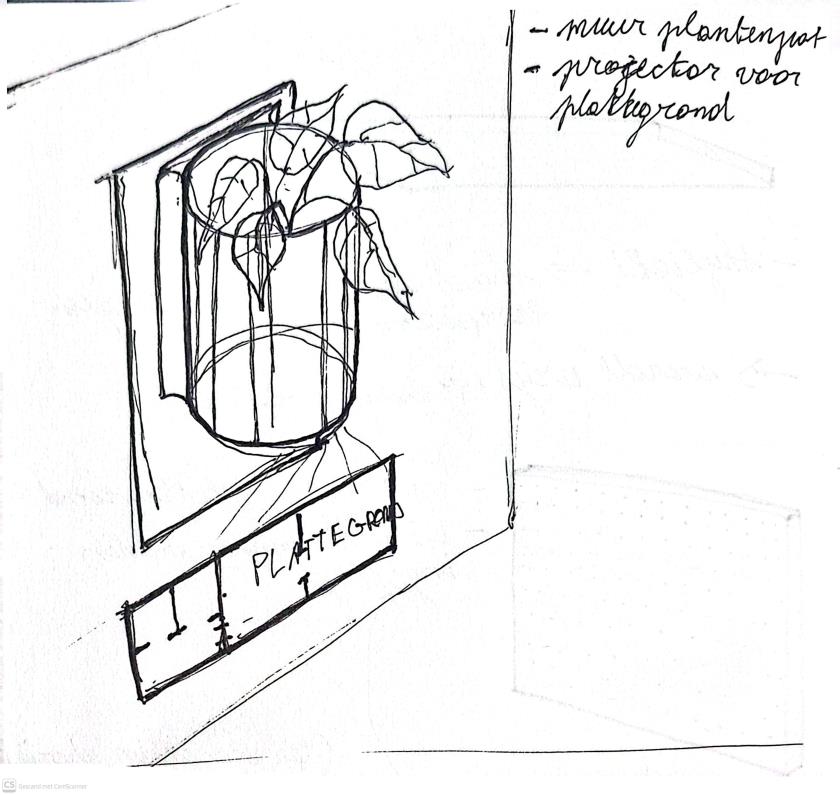
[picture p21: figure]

Figuur 5 : Slimme Plantenprojector

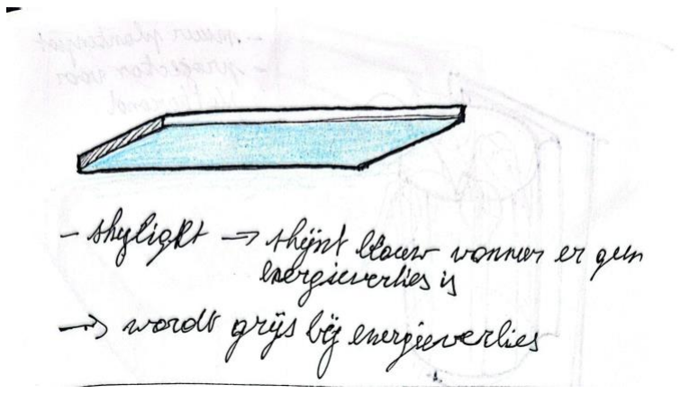
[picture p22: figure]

Figuur 6 : Skylight

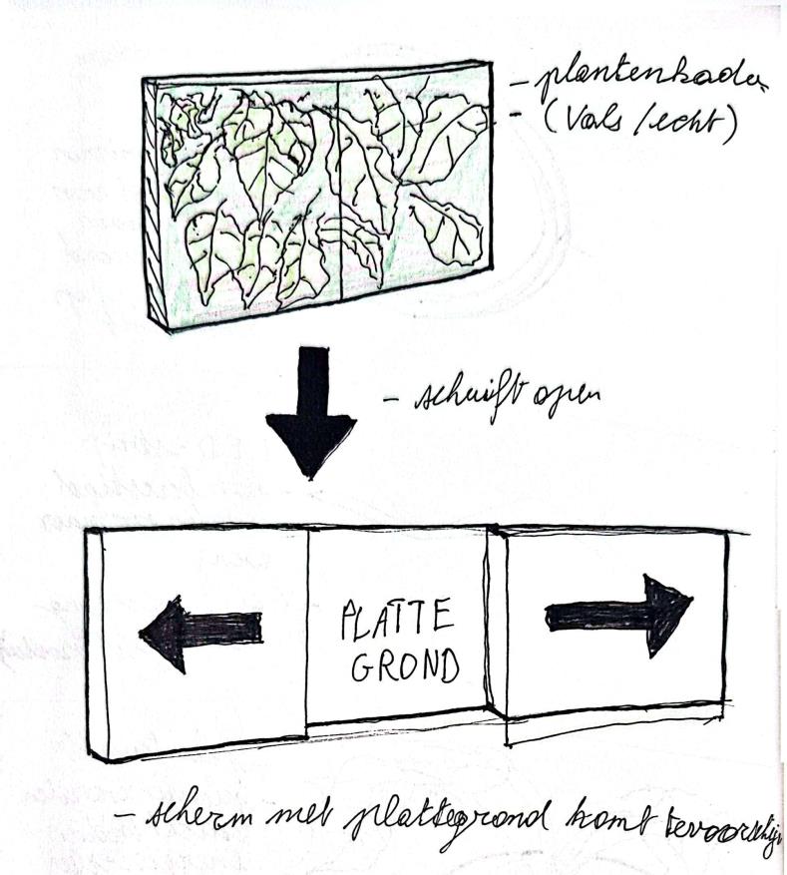
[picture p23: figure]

Figuur 7 : Slimme Plantenkader

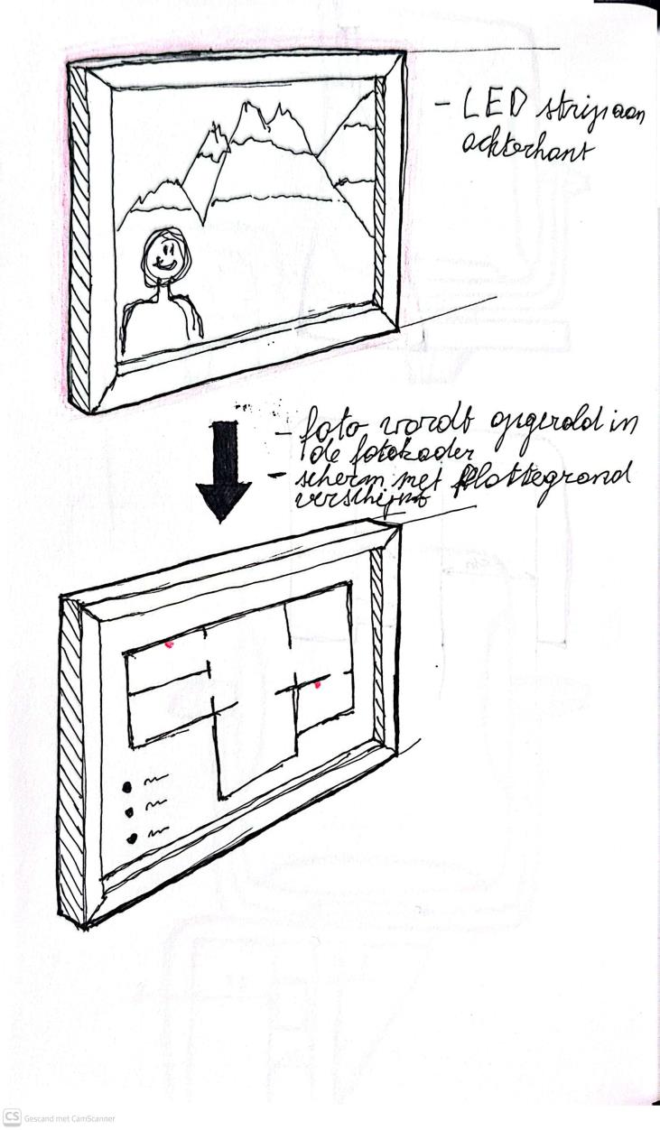
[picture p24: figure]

Figuur 8: Slimme fotokader

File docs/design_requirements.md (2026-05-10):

## Overzicht van Design Requirements

| ID  | Design Requirement | Source |
| :-- | :--- | :--- |
| 1.1 | EcoLux detecteert energieverspilling en laat dit weten aan de gebruiker. | Discovery |
| 1.2 | Ecolux verhoogt het dagelijks wooncomfort terwijl het energieverbruik wordt verminderd. | Discovery |
| 2.1 | EcoLux gebruikt licht als primaire feedbackmechaniek. | Definition (Wave 1) |
| 2.2 | EcoLux heeft een modulair ontwerp met één hoofdstation en uitbreidbare substations. | Definition (Wave 1) |
| 2.3 | Ecolux is esthetisch personaliseerbaar om aan te sluiten bij verschillende gebruikers en interieurs. | Definition (Wave 1) |
| 3.1 | EcoLux communiceert energieverliezen via een visuele weergave die de locatie in de woning duidelijk maakt. | Definition (Wave 2) |
| 3.2 | EcoLux ondersteunt snelle uitvoering van actie zodra een energieverlies wordt gedetecteerd. | Definition (Wave 2) |
| 3.3 | EcoLux automatiseert het oplossen van energieproblemen maximaal, zodat de gebruiker zo weinig mogelijk handelingen hoeft uit te voeren. | Definition (Wave 2) |
| 4.1 | De bedieningsknop bevindt zich in een positie die stabiele interactie met het product ondersteunt. | Develop 1 |
| 4.2 | De onderzijde van het product biedt voldoende grip om verschuiven tijdens gebruik te voorkomen. | Develop 1 |
| 4.3 | Het scherm blijft duidelijk leesbaar vanuit een natuurlijke kijkhoek wanneer het product laag geplaatst is. | Develop 1 |
| 4.4 | De hoek van het scherm kan eenvoudig en betrouwbaar worden aangepast. | Develop 1 |
| 4.5 | Het product bevat een beperkt aantal bewegende onderdelen. | Develop 1 |
| 4.6 | Het product behoudt zijn functionaliteit en structurele integriteit bij frequente dagelijkse interactie. | Develop 1 |
| 5.1 | Het product behoudt structurele stabiliteit tijdens interactie, zonder merkbare beweging bij aanraking. | Develop 2 |
| 5.2 | Het object blijft visueel ondergeschikt aan de omgeving, waarbij het geen dominant element vormt op een kast of tafel. | Develop 2 |
| 5.3 | Het scherm biedt voldoende visuele ruimte om alle interface-elementen duidelijk leesbaar weer te geven op ±1 meter afstand. | Develop 2 |
| 5.4 | Interface-elementen zijn accuraat selecteerbaar zonder frequente misdrukken (>95% correcte interactie). | Develop 2 |
| 5.5 | Het schermformaat ondersteunt een gebalanceerde verhouding tussen leesbaarheid en fysieke compactheid van het product. | Develop 2 |
| 5.6 | Icoontjes zijn consistent, herkenbaar en visueel onderscheidbaar van elkaar. | Develop 2 |
| 5.7 | De interface ondersteunt visuele differentiatie van ruimtes via kleurgebruik. | Develop 2 |
| 5.8 | De visuele stijl draagt bij aan een aangename en hedendaagse gebruikerservaring met consistente vormtaal. | Develop 2 |
| 5.9 | Gebruikers kunnen meerdere apparaten binnen één ruimte in één handeling selecteren. | Develop 2 |
| 5.10| Interacties verlopen nauwkeurig en zonder frustratie, met duidelijk afgebakende touchzones. | Develop 2 |
| 5.11| Het systeem toont relevante informatie per apparaat, waaronder status, energieverbruik en gebruiksduur. | Develop 2 |
| 5.12| Gedetailleerde informatie is toegankelijk via een aanvullende interactie. | Develop 2 |
| 5.13| De informatie ondersteunt bewustwording en gedragsverandering rond energiegebruik. | Develop 2 |
| 5.14| Nieuwe gebruikers begrijpen de basiswerking van het systeem binnen een korte introductieperiode (<5 minuten). | Develop 2 |
| 5.15| De gebruikerservaring verloopt zonder frequente fouten of onzekerheden tijdens gebruik. | Develop 2 |
| 5.16| Het product combineert esthetische integratie in de leefomgeving met functionele meerwaarde. | Develop 2 |
| 6.1 | EcoLux past visueel binnen verschillende interieurs zonder te dominant aanwezig te zijn. | Develop 3 |
| 6.2 | De kleurkeuze is gebaseerd op lichte, natuurlijke en zachte tinten, eventueel gecombineerd met een subtiel kleuraccent. | Develop 3 |
| 6.3 | Het materiaal of de materiaaluitstraling communiceert duurzaamheid en warmte. | Develop 3 |
| 6.4 | Het oppervlak is aangenaam en praktisch in dagelijks gebruik, bij voorkeur glad of mat en eenvoudig schoon te maken. | Develop 3 |
| 6.5 | De tactiele textuur voelt niet storend of ruw aan. | Develop 3 |
| 6.6 | De finale CMF-keuze ondersteunt de waarden van EcoLux: toegankelijkheid, duurzaamheid, eenvoud en financieel voordeel. | Develop 3 |

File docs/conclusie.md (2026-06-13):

## Conclusie: finaal concept

Het finale concept van EcoLux is een slim interieurproduct dat energieverlies in huis automatisch detecteert, zichtbaar maakt en omzet in een eenvoudige actie voor de gebruiker. EcoLux bestaat uit een hoofdstation in de vorm van een subtiele slimme bloempot met geïntegreerd aanraakscherm, aangevuld met visuele lichtfeedback en een koppeling met slimme apparaten in de woning. Via het scherm krijgt de gebruiker een plattegrond van de woning te zien, waarop duidelijk wordt aangeduid in welke ruimte energieverlies plaatsvindt. Wanneer een toestel langer ingeschakeld blijft dan gewenst, wordt dit gecommuniceerd via licht. De gebruiker kan vervolgens ingrijpen of het toestel laten uitschakelen via de interface op de EcoLux.

Dit concept sluit rechtstreeks aan bij de eerder opgestelde [design requirements](./design_requirements.md). EcoLux detecteert energieverspilling en communiceert dit actief naar de gebruiker, zonder dat die voortdurend zelf energiegegevens moet opvolgen. Het systeem gebruikt licht als feedback en combineert dit met een visuele plattegrondweergave, waardoor energieverlies niet abstract blijft maar gekoppeld wordt aan een herkenbare locatie in de woning. Daarnaast ondersteunt EcoLux snelle actie en automatisatie, zodat energiebesparing minder afhankelijk wordt van discipline, technische kennis of dagelijkse aandacht.

EcoLux werd ontworpen als antwoord op het centrale probleem dat uit het onderzoek naar voren kwam: huishoudens willen wel energie besparen, maar energieverlies blijft vaak onzichtbaar en wordt daardoor niet structureel aangepakt. Bestaande oplossingen zijn vaak sterk app- of datagericht en vragen actieve monitoring van de gebruiker en het hele gezin. Daardoor sluiten ze minder goed aan bij dagelijkse routines. EcoLux kiest bewust voor een passieve en visuele benadering. Zo wordt energieverlies zichtbaar op het moment dat actie relevant is. Op basis van een realistisch referentiescenario wordt ruw geschat dat EcoLux €100 per jaar kan besparen, afhankelijk van het aantal gekoppelde toestellen, de instellingen, energieprijzen en het gedrag van het huishouden, zie [kostenberekening](https://github.com/Vic-Syryn/EcoLux/blob/main/onderzoek/kostenberekening%20ecolux.pdf).

De keuze voor een fysiek interieurproduct is daarbij essentieel. Door EcoLux niet als losse app of technische energiemeter te ontwerpen, maar als een object dat vanzelfsprekend al aanwezig is in de leefomgeving, wordt de drempel tot gebruik lager. De slimme bloempot past binnen het interieur, voelt minder technisch aan en blijft subtiel aanwezig wanneer er geen probleem is. Tegelijk zorgt het geïntegreerde scherm ervoor dat de gebruiker controle behoudt wanneer dat nodig is. Deze combinatie van rust in normale toestand en duidelijke feedback bij energieverlies sluit aan bij de behoefte aan comfort, eenvoud en vertrouwen binnen smart-homegebruik.

Daarom geloven we dat EcoLux binnen de scope van dit project de meest geschikte oplossing is voor het eerder geschetste probleem. Het concept combineert gedragsinzichten, gebruiksgemak, esthetische integratie en technische haalbaarheid in één samenhangend product. EcoLux maakt energieverspilling zichtbaar voor het hele gezin zonder extra complexiteit toe te voegen, ondersteunt snelle en automatische actie zonder de gebruiker de controle te ontnemen, en past als rustig interieurproduct binnen de dagelijkse woonomgeving. Hierdoor vormt het een geloofwaardig alternatief voor bestaande energieoplossingen die vaak te technisch, te appgericht of te belastend zijn voor langdurig gebruik.
<p align="center">
  
  Ecolux
<p align="center">

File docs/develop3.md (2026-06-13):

## Develop 3
In deze Develop 3-fase ligt de focus op de verdere verfijning van gebruikerservaring, emotionele beleving en esthetische uitwerking. Het concept werd eerder functioneel gevalideerd. Daarom wordt nu onderzocht hoe het product aanvoelt, welke emoties het oproept en hoe het past binnen een bredere servicecontext.

In dit verslag wordt aandacht besteed aan UX, Service Design en CMF. Kleuren, materialen en afwerkingen worden geanalyseerd.

### <ins>**Service Design**</ins>

### EcoLux — Customer Journey

<table>
<tr>
<td width="11%" valign="top">

## 1. Awareness

### Goal
Grip krijgen op energieverbruik en energieverlies verminderen.

### Actions
- Hoort over EcoLux via advertenties, sociale media of mond-tot-mondreclame.
- Realiseert hoeveel energie verloren gaat in huis.

### Touchpoints
- Website
- Social media
- Advertenties
- Energie-artikels
- Demo’s

### Emoties
Frustratie  
Hoop

### Pain Points
- Geen inzicht in energieverlies.
- Smart-home systemen lijken technisch of duur.

### Opportuniteiten
- Duidelijke communicatie rond besparing.
- Focus op eenvoud en toegankelijkheid.

### Backstage / Stakeholders
- Marketingteam
- Energie-data
- Online platform
- Energiepartners

</td>

<td width="11%" valign="top">

## 2. Consideration

### Goal
Begrijpen of EcoLux relevant is voor de woning.

### Actions
- Vergelijkt EcoLux met andere oplossingen.
- Bekijkt demo’s en scenario’s.
- Probeert automatisatie te begrijpen.

### Touchpoints
- Website
- Reviews
- Demo video’s
- Prototype presentatie

### Emoties
Nieuwsgierigheid  
Onzekerheid

### Pain Points
- Moeilijk inschatten welke componenten nodig zijn.
- Angst voor complexe installatie.

### Opportuniteiten
- Scenario’s visueel tonen.
- Concrete situaties demonstreren.

### Backstage / Stakeholders
- Product positioning
- Pricing
- Klantendienst
- Retailpartners

</td>

<td width="11%" valign="top">

## 3. Onboarding

### Goal
EcoLux correct installeren en verbinden.

### Actions
- Plaatst sensoren en actuatoren.
- Verbindt hoofdstation met app.
- Test eerste functies.

### Touchpoints
- Hoofdstation
- Substations
- App
- Packaging
- Handleiding

### Emoties
Onzekerheid  
Opluchting  
Wow-moment

### Pain Points
- Onduidelijke plaatsing.
- Connectiviteitsproblemen.

### Opportuniteiten
- Guided setup.
- Duidelijke feedback via LEDs.

### Backstage / Stakeholders
- Connectivity systems
- Cloud services
- Installatie support

</td>

<td width="11%" valign="top">

## 4. Use

### Goal
Inzicht krijgen in energieverlies.

### Actions
- Ontvangt meldingen.
- Ziet energieverlies in realtime.
- Reageert op feedback.

### Touchpoints
- LEDs
- Display
- Sensor feedback

### Emoties
Verrassing  
Inzicht

### Pain Points
- Te veel meldingen.
- Onduidelijke oorzaak van verlies.

### Opportuniteiten
- Contextuele meldingen.
- Prioriteren van notificaties.

### Backstage / Stakeholders
- Sensor data processing
- Realtime monitoring
- Energie-algoritmes

</td>
</tr>
</table>

<table>
<tr>
<td width="11%" valign="top">

## 5. Decision

### Goal
Beslissen hoe te reageren.

### Actions
- Negeert melding.
- Gebruiker kiest ervoor om het probleem op te laten lossen.
- Laat EcoLux automatisch handelen.

### Touchpoints
- Display
- Interface
- Actuatoren

### Emoties
Controle  
Opluchting

### Pain Points
- Te veel keuzes.

### Opportuniteiten
- Snelle acties.
- Eenvoudige interacties.

### Backstage / Stakeholders
- AI aanbevelingen
- Beslissingslogica
- Sensor-actuator communicatie

</td>

<td width="11%" valign="top">

## 6. Automation

### Goal
Automatisch energiebeheer.

### Actions
- EcoLux schakelt verlichting of toestellen uit.

### Touchpoints
- Actuatoren
- Statusfeedback

### Emoties
Vertrouwen  
Mogelijke irritatie

### Pain Points
- Angst voor verlies van controle.
- Onverwachte acties.

### Opportuniteiten
- Transparantie bieden.
- Override mogelijkheid.

### Backstage / Stakeholders
- AI learning
- Automatiseringsregels
- Software updates

</td>

<td width="11%" valign="top">

## 7. Integration

### Goal
EcoLux integreren in dagelijkse routines.

### Actions
- Gebruikt slaapmodus.
- Activeert “huis verlaten”-modus.

### Touchpoints
- Fysieke schakelaar
- Interface

### Emoties
Rust  
Veiligheid

### Pain Points
- Vergeten functies te gebruiken.

### Opportuniteiten
- Gedragsgebaseerde automatisatie.

### Backstage / Stakeholders
- Scenario management
- Smart-home integraties
- Gedragsanalyse

</td>

<td width="11%" valign="top">

## 8. Feedback

### Goal
Resultaten begrijpen en opvolgen.

### Actions
- Bekijkt rapporten.
- Analyseert besparing.
- Evalueert gebruiksgemak.

### Touchpoints
- Dashboard
- Rapporten
- Statistieken

### Emoties
Trots  
Motivatie

### Pain Points
- Data te technisch.

### Opportuniteiten
- Simpele visualisaties.
- Heldere rapportering.

### Backstage / Stakeholders
- Data-analyse
- Rapportgeneratie
- Cloud opslag

</td>

<td width="11%" valign="top">

## 9. Loyalty

### Goal
Langdurig gebruik en uitbreiding.

### Actions
- Beveelt EcoLux aan.
- Breidt systeem uit.
- Verwacht updates en support.

### Touchpoints
- Community
- Support
- Add-ons
- Updates

### Emoties
Loyaliteit  
Vertrouwen

### Pain Points
- Minder engagement op lange termijn.

### Opportuniteiten
- Uitbreidbaar ecosysteem.
- Communitygevoel versterken.

### Backstage / Stakeholders
- Customer support
- Software updates
- Hardware partners

</td>
</tr>
</table>

### <ins>**CMF analyse**</ins>

In de CMF analyse worden CMF opties gekozen en onderbouwd om later bij gebruikerstesten de definitieve CMF te valideren. De werkwijze is gebaseerd op de workshop CMF van de les. 

**doelgroep in kernwoorden**
<p align="center">
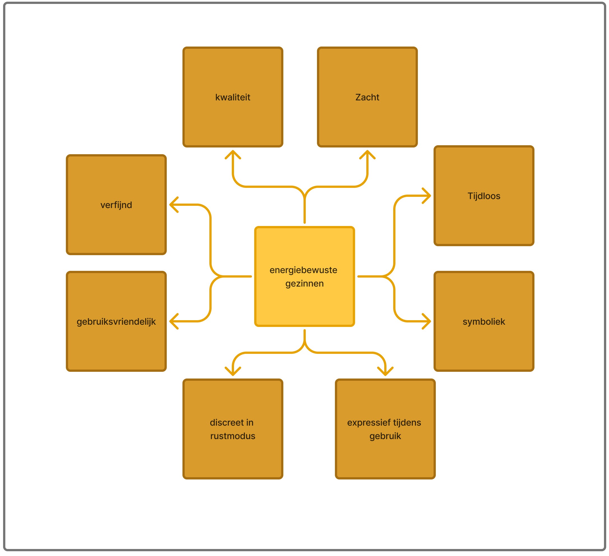
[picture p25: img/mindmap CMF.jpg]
  
<p align="center">
mindmap CMF</p>

**product in omgeving**
<p align="center">
  
<p align="center">
meubels omgeving</p>

### **CMF analyse omgeving**

 Overlappende CMF analyse producten: warm minimal natural 

Over alle drie de producten is een duidelijke samenhang zichtbaar in kleur, materiaal, afwerking en vormgeving. 

**Kleur**:
De kleuren zijn neutraal, licht en warm. Wit, beige en zand domineren, telkens met een warme ondertoon. Er zijn geen uitgesproken kleuren of sterke contrasten. Dit zorgt voor een rustige, toegankelijke en tijdloze uitstraling. 

**Materialen**:
Er is een combinatie van natuurlijke en industriële materialen. Hout en rotan worden gecombineerd met MDF en polyester stoffen. De natuurlijke materialen zijn zichtbaar en tactiel aanwezig, maar blijven betaalbaar. Dit voelt als betaalbare natuur, eerder dan puur premium of volledig synthetisch. 

**Afwerking**:
De afwerking is mat, zacht en tactiel. Reflecterende oppervlakken en hoogglans worden vermeden. Daardoor ontstaat een lage visuele prikkel en een hoger gevoel van comfort.  

### **Overeenkomst CMF en doelgroep**

De drie CMF’s sluiten sterk aan bij energiebewuste gezinnen. Zachte kleuren en natuurlijke materialen ondersteunen comfort, rust en zachtheid. De eenvoudige vormgeving en neutrale tinten geven een gevoel van duurzaamheid en lange levensduur. De producten zijn ook visueel discreet, wat past bij “discreet in rustmodus”. 

### **Standaard in de markt**

Binnen deze markt is een duidelijke standaardtaal zichtbaar: lichte houttinten met wit of beige, matte afwerkingen en warme neutrale kleuren. Materialen ogen natuurlijk, maar zijn vaak industrieel geproduceerd. De vormgeving is eenvoudig en functioneel. Dit zorgt voor brede toepasbaarheid, maar ook voor uniformiteit. 

### **Opportinuteit voor differentiatie**

Er ligt een kans om het neutrale palet subtiel uit te breiden. Gedempte accentkleuren zoals saliegroen, terracotta of vergrijsd blauw blijven rustig, maar geven het product meer identiteit. 
<p align="center">
  
<p align="center">
kleurenpalet</p>

Ook materiaalgebruik kan authentieker. In plaats van industriële materialen met een natuurlijke uitstraling kan sterker worden ingezet op echte materialen. Massief hout, grover geweven stoffen, keramiek of natuursteen zorgen voor meer visuele kwaliteit en tactiele beleving. 

Bij afwerking kan differentiatie ontstaan door subtiele contrasten en details, zoals mat met licht satijn, textuurvariaties of afgewerkte randen. Deze ingrepen blijven discreet, maar maken het product interessanter.

**morfologische matrix**
<p align="center">
  
<p align="center">
CMF morfologische matrix</p>

**CMF varianten**

Op basis van de morfologische matrix werden de volgende varianten gemaakt die we later konden voorstellen aan de gebruikers.
<p align="center">
  
<p align="center">
CMF varianten</p>

### <ins>**Build & test**</ins>
**Doelstellingen**

Het doel van deze test was om verschillende prototypevarianten te vergelijken en finale ontwerpkeuzes te onderbouwen. Er werd onderzocht welke variant het best aansluit bij de doelgroep op vlak van uitstraling, kleur, materiaal, afwerking en emotionele impact.

**Materialen**

* Touch and feel bord 
* Smartphone voor opnames/foto’s 
* Informed consent
* Renders 
<p align="center">
  
</p>
<p align="center">
touch and feel bord</p>

**Methoden**

De testen werden afgenomen bij vier respondenten met verschillende leeftijden en niveaus van technologische ervaring. De interviews vonden plaats in de thuisomgeving, zodat het product realistisch beoordeeld kon worden.

Tijdens de test kregen deelnemers renders en een touch-and-feel bord te zien. Hiermee werden voorkeuren rond kleur, textuur, materiaal en afwerking onderzocht. Respondenten vergeleken matte en glanzende afwerkingen, gladde en getextureerde oppervlakken, en hout tegenover kunststof. Ook werd gevraagd waar ze het product zouden plaatsen en welke emoties EcoLux moest oproepen.

De data werd verzameld via een semigestructureerd interview met ruimte voor gerichte vragen en spontane feedback. Nadien werden terugkerende patronen in voorkeuren, attitudes en motivaties geanalyseerd. Deze inzichten vormden de basis voor verdere CMF-keuzes en design requirements.

**Resultaten**
<p align="center">
  
</p>
<p align="center">
interactie gebruikerstest</p>

Uit de interviews kwamen inzichten naar voren over uitstraling, materiaal, kleur en gebruikscontext. Respondenten willen dat het product subtiel aanwezig is in het interieur. Het mag aantrekkelijk zijn, maar niet te sterk opvallen of technisch aanvoelen. Een rustige vormgeving die past binnen verschillende woonstijlen is daarom belangrijk.

Gebruikers hechten veel belang aan kwaliteit, degelijkheid en betrouwbaarheid. Het product moet vertrouwen opwekken en mag niet goedkoop ogen. Natuurlijke materialen of materialen met een natuurlijke uitstraling werden positief beoordeeld. Hout of een houtachtige afwerking past goed bij het duurzame karakter van EcoLux.

Op vlak van kleur verkiezen respondenten zachte, lichte en natuurlijke tinten. Deze zijn toegankelijker en minder storend in een woning. Het product moet rustig ogen, maar wel eigenheid hebben.

Qua textuur waarderen gebruikers vooral subtiele visuele textuur. Een natuurlijke nerf of fijne afwerking maakt het product warmer en kwalitatiever. Sterk voelbare of ruwe textuur werd minder positief ervaren. Een gladde of matte afwerking sluit beter aan bij dagelijks gebruik.

Algemeen beoordelen respondenten het product niet alleen op functionaliteit, maar ook op emotionele en esthetische beleving. De vormgeving moet vertrouwen en rust uitstralen.

### <ins>Conclusies en implicaties</ins>
De Develop 3-fase toont dat EcoLux verder moet evolueren van functioneel concept naar een product dat ook sterk scoort op gebruikservaring, uitstraling en emotionele beleving.

Uit de customer journey blijkt dat gebruikers nood hebben aan eenvoud, duidelijke feedback en vertrouwen. Smart-homeproducten kunnen snel technisch of complex aanvoelen. EcoLux moet zich daarom onderscheiden als toegankelijke oplossing. Tijdens installatie, dagelijks gebruik en automatisatie moet de gebruiker begrijpen wat het systeem doet en controle behouden.

De CMF-analyse en gebruikerstesten wijzen in dezelfde richting. Respondenten verkiezen een product dat subtiel aanwezig is en betrouwbaar oogt. Zachte, lichte en natuurlijke tinten, matte afwerkingen en hout of een houtachtige uitstraling sluiten het best aan bij rust, duurzaamheid en huiselijkheid.

De belangrijkste implicatie is dat EcoLux moet worden uitgewerkt als warm, discreet en gebruiksvriendelijk interieurproduct. De vormgeving moet eenvoudig blijven, maar mag subtiele details of accentkleuren bevatten. Feedback, meldingen en automatisatie moeten helder en controleerbaar blijven, zodat het product vertrouwen opwekt en deel wordt van dagelijkse routines.
Op basis hiervan werden de design requirements aangevuld.

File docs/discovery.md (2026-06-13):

## Discovery

De discoveryfase had als doel inzicht te verwerven in waarom huishoudens, ondanks een duidelijke bereidheid om te besparen, in de praktijk moeite hebben om hun energieverbruik effectief te verminderen. De focus lag hierbij niet op technische optimalisatie, maar op gedrag, routines en perceptie: waar ontstaat energieverspilling en waarom blijft deze vaak onopgemerkt? De inzichten uit deze fase vormden de basis voor het definiëren van onderbouwde designbeslissingen en productvereisten.

### Doelstellingen

De hoofddoelstelling was het doorgronden van de kloof tussen de intentie om te besparen en het daadwerkelijke dagelijkse gedrag.

Welke deelvragen moesten hiervoor beantwoord worden?
De volgende deelvragen stonden centraal:

* Hoe ervaren gebruikers hun dagelijks energieverbruik? 

* Welke momenten in de dagelijkse routine leiden tot energieverspilling? 

* Welke motivaties en barrières spelen een rol bij besparen? 

* Hoe worden bestaande slimme oplossingen ervaren? 

* Welke vorm van feedback ondersteunt gedragsverandering zonder extra cognitieve belasting? 

### Materiaal & methoden

Om zowel de probleemruimte als de oplossingsruimte te verkennen, werden twee complementaire onderzoeksmethoden toegepast: contextual inquiries en een benchmarkonderzoek.

**Contextual inquiries (gebruikersonderzoek)**
Er werden drie contextual inquiries uitgevoerd bij uiteenlopende huishoudens: een technologie-enthousiasteling, een gemiddelde gebruiker en een oudere alleenstaande. Deze methode werd gekozen omdat ze toelaat om gebruiksgedrag en context in de natuurlijke thuissituatie te observeren. Naast semigestructureerde interviews werden dagelijkse routines, toestellen en omgevingsfactoren in kaart gebracht. De dataverzameling bestond uit observatienotities, audio-opnames en foto’s. De verzamelde data werd thematisch geanalyseerd op terugkerende patronen in gedrag, motivatie, barrières en attitudes ten opzichte van slimme technologie. (Het volledige protocol en rapport zijn beschikbaar via de repository).

<p align="center">
  
</p>
<p align="center">
gebruikersonderzoek</p>

**Benchmarkonderzoek (markt & technologie)**
Aanvullend werd een benchmarkonderzoek uitgevoerd naar bestaande slimme oplossingen voor energiebeheer. Het doel was om te analyseren hoe deze oplossingen feedback geven, welke interactievormen worden gebruikt en in welke mate ze gedrag ondersteunen. De analyse gebeurde aan de hand van een vergelijkende tabel en een thematische synthese.

### Resultaten

**Resultaten uit contextual inquiries**
Uit de interviews en observaties kwamen de volgende consistente patronen naar voren:

* Energieverbruik wordt zelden actief en continu opgevolgd; gebruikers vertrouwen vooral op intuïtie of sporadische checks.

* De motivatie om te besparen is voornamelijk financieel, terwijl ecologische voordelen als secundair worden ervaren.

* Sluipverbruik en ventilatie vormen belangrijke, maar moeilijk controleerbare bronnen van energieverlies.

* Slimme technologie is beschikbaar, maar wordt vaak als complex en tijdsintensief ervaren.

* Gebruiksgemak en comfort blijken doorslaggevend voor langdurig gebruik.

Deze bevindingen wijzen op een duidelijke kloof tussen beschikbare technologie en het dagelijkse gedrag van gebruikers.

### Afbakening van de doelgroep

Op basis van de interviews, contextual inquiries en het benchmarkonderzoek werd de doelgroep aangescherpt naar huishoudens die een woning renoveren. Deze gebruikers bevinden zich in een fase waarin bestaande routines worden herbekeken en beslissingen rond energie, comfort en technologie actief worden genomen. Zowel uit de interviews als uit externe bronnen blijkt dat energiebesparing tijdens renovaties voornamelijk wordt gemotiveerd door financiële redenen [^6], aangevuld met regelgeving en duurzaamheidsdoelstellingen [^7].

Daarnaast is een renovatie een geschikt instapmoment voor nieuwe producten, aangezien installatiedrempels lager liggen en gebruikers meer openstaan voor verandering. Gedragsinterventies blijken effectiever wanneer ze worden geïntroduceerd op zulke overgangsmomenten [^8]. Hierdoor werd deze doelgroep als meest relevant beschouwd voor het verdere ontwerpproces.

**Resultaten uit benchmarkonderzoek**
De vergelijking toont aan dat de markt sterk data-gedreven is, met een focus op cijfers, grafieken en apps. Intuïtieve of emotionele feedbackvormen zijn zeldzaam. De analyse maakt duidelijk dat ambient, niet-digitale feedback nauwelijks wordt toegepast, terwijl net deze vorm van feedback potentieel heeft om gedrag laagdrempelig te beïnvloeden.

| Nr. | Oplossing / merk | Type | Kernfunctie | Sterkte | Beperking |
| --- | --- | --- | --- | --- | --- |
| 1 | **Google Nest Hub**[^1] | Slim display | Centrale bediening via scherm & stem | Veel integraties, gebruiksvriendelijk | Scherm- en appgericht, weinig gedragssturing |
| 2 | **tado° Smart Thermostat**[^2] | Slimme thermostaat | Efficiënt verwarmen | Meetbare energiebesparing | Enkel verwarming, beperkte feedback |
| 3 | **NIKO Home Control**[^3] | Domoticasysteem | Volledige woningautomatisering | Zeer krachtig en betrouwbaar | Duur, hoge installatiedrempel |
| 4 | **IKEA Dirigera**[^4] | Budgetdomotica | Basisautomatisering | Toegankelijk, lage kost | Beperkte intelligentie, app-afhankelijk |
| 5 | **Eve Energy**[^5] | Slimme stekker | Meten & schakelen van verbruik | Inzicht per toestel | Geen centraal overzicht |
| 6 | **Netatmo Air Monitor**[^6] | Klimaatsensor | Inzicht in luchtkwaliteit | Heldere feedback | Niet gericht op energiebesparing |
| 7 | **Sense Energy Monitor**[^7] | Energiemonitor | Gedetailleerde verbruiksanalyse | Zeer datagedreven | Complex, technisch |
| 8 | **AquaSave Shower Timer**[^8] | Waterbesparing | Nudging via tijd | Simpel en goedkoop | Geen integratie of context |
| 9 | **ecobee Thermostat**[^9] | Slimme thermostaat | Comfort + energiebesparing | Slimme AI-aansturing | Enkel temperatuur |
| 10  | **Energy Blossom (concept)**[^10] | Ambient feedback | Emotionele nudging | Intuïtief, visueel | Conceptueel, niet commercieel |

### Conclusies & implicaties

Op basis van de synthese van beide onderzoeksmethoden werden de volgende kerninzichten en bijbehorende designimplicaties geformuleerd:

| Observatie uit onderzoek | Inzicht | Designimplicatie |
| --- | --- | --- |
| Gebruikers volgen hun energieverbruik zelden actief op | Energieverbruik is onzichtbaar en abstract | Feedback moet continu en passief aanwezig zijn |
| Apps en dashboards worden als complex ervaren | Cognitieve belasting is te hoog | Geen scherm of app als primaire interface |
| Sluipverbruik en ventilatie blijven vaak onopgemerkt | Verspilling gebeurt onbewust | Automatische detectie is noodzakelijk |
| Comfort primeert bij alle gebruikers | Besparen mag geen extra moeite kosten | Oplossing moet comfort behouden of verhogen |

Deze inzichten leidden tot de conclusie dat een effectief energiebesparend product energieverspilling automatisch dient te detecteren en dit op een eenvoudige, visuele en niet-invasieve manier moet communiceren. Daarbij moet het dagelijkse wooncomfort behouden of zelfs verhoogd worden. Op basis van deze inzichten werd een eerste mockup gemaakt.

<p align="center">
  
</p>
<p align="center">
1ste iteratie prototype</p>

## Bronnen

[^1]:Google. (2025). Google Nest Hub (2nd Gen). Geraadpleegd op 9 oktober 2025, van https://store.google.com

[^2]: Tado°. (2025). Smart Thermostat – Intelligent heating control. Geraadpleegd op 9 oktober 2025, van https://www.tado.com

[^3]: NIKO. (2025). NIKO Home Control – Domotica voor woningen. Geraadpleegd op 9 oktober 2025, van https://www.niko.eu

[^4]: IKEA. (2025). Dirigera hub + Home Smart system. Geraadpleegd op 9 oktober 2025, van https://www.ikea.com

[^5]: Eve Systems. (2025). Eve Energy – Smart Plug & Power Meter. Geraadpleegd op 9 oktober 2025, van https://www.evehome.com

[^6]: Netatmo. (2025). Smart Indoor Air Quality Monitor. Geraadpleegd op 9 oktober 2025, van https://www.netatmo.com

[^7]: Sense Labs Inc. (2025). Sense Home Energy Monitor. Geraadpleegd op 9 oktober 2025, van https://sense.com

[^8]: AquaSave. (2025). AquaSave smart shower timer. Geraadpleegd op 9 oktober 2025, van https://www.aquasave.com

[^9]: Ecobee Inc. (2025). Ecobee Smart Thermostat Premium. Geraadpleegd op 9 oktober 2025, van https://www.ecobee.com

[^10]: DesignBoom. (2022, 14 mei). Energy Blossom: an ambient feedback concept for sustainable behavior. Geraadpleegd van https://www.designboom.com

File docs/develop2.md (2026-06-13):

## Develop 2

Door de conclusies uit Develop 1 was er voldoende informatie om het design van het hoofdstation verder te bepalen en te valideren. Uit Develop 1 bleek onder andere dat het scherm niet instelbaar moest zijn. Voor develop 2 werd er aan het design gewerkt, de 11 beste schetsen werden opgenomen in een [Scorematrix (Develop 2)](https://github.com/Vic-Syryn/EcoLux/blob/main/onderzoek/Scorematrix_Develop_2.pdf). Hieruit werden de 4 meest belovende vormen geselecteerd op vlak van esthetiek, schermintegratie, haalbaarheid en potentieel gebruiksgemak. Op deze vormen werden de usability goals verder bepaald.

### <ins>**Usability goals**</ins>

Ergonomie: de gemiddelde man/vrouw moet het product kunnen gebruiken met minimale ergonomische belasting. (Siemens Jack)

Cognitieve & sensoriële ergonomie: Gebruikers (18–65 jaar) kunnen kerntaken in de app (bv. navigeren, informatie lezen en acties uitvoeren) binnen 30 seconden voltooien, met maximaal 1 fout per taak en een subjectieve leesbaarheidsscore van ≥ 4/5.

### <ins>Theoretische antropometrie</ins>

Om de ideale kijkhoek voor het scherm te bepalen vóór de fysieke prototypefase, werd een ergonomische simulatie uitgevoerd in Siemens Jack [(analyse)](https://github.com/Vic-Syryn/EcoLux/blob/main/onderzoek/Ergonomie%20scherm%20Siemens%20Jack.pdf). Hierbij werd een digitaal mensmodel gebruikt op basis van antropometrische data. De 'design for the mean'-methode werd toegepast met het 50e percentiel.

Als referentiehoogte werd eerst de eettafelhoogte onderzocht. De gemiddelde eettafelhoogte is 74 cm. Uit de simulatie bleek dat deze hoogte onvoldoende is voor comfortabel gebruik, ongeacht de kijkhoek. Daarom werd overgestapt naar dressoirhoogte, ongeveer 90 cm. Dit biedt een ergonomisch betere uitgangspositie.

<p align="center">
  
  
</p>
<p align="center">
simulatie gebruik gem man en vrouw </p>

<p align="center">
  
</p>
<p align="center">
Simulatie belasting</p>

<p align="center">
  
</p>
<p align="center">
POV gebruiker</p>

Uit de analyse bleek een schermhoek van 23° optimaal. Bij deze hoek is de belasting op nek en rug minimaal, terwijl het scherm goed leesbaar blijft.

### <ins>**Cognitieve & sensoriële ergonomie**</ins>

Om met EcoLux te interageren, moest er een digitale interface gemaakt worden. Op basis van de interface uit de tweede wave van de definitionfase werd een verbeterde interface gemaakt met Figma make. Om te voldoen aan de tweede usability goal werd de interface ontworpen met de Gestaltwetten in het achterhoofd. De interface werd zo simpel mogelijk gehouden om cognitieve belasting te minimaliseren. Extra optimalisaties waren liftknoppen als metafoor om de juiste verdieping te kiezen en icoontjes als signifiers voor energieverliezende apparaten.

<p align="center">
  
</p>
<p align="center">
app interface</p>

### <ins>**Build & test**</ins>

**Doelstellingen**

De gebruikerstesten onderzochten welke vorm als het meest esthetisch en praktisch werd ervaren. Daarnaast werden meerdere schermgroottes getest die modulair op de vormen pasten. Op het scherm stond een demoversie van de interface. Ook werd nagegaan of de hoek uit 'Ergonomie scherm – Siemens Jack' in de realiteit aangenaam was.

**Prototypes**

Met de 4 hoofdvormen, de ideale schermhoek en een interactieve interface werden prototypes gemaakt. Omdat schetsen geen duidelijk beeld geven van omvang en interactie, werden de 4 schetsen in Blender nagemaakt via subdivision-modeling. Op basis van deze 3D-modellen werden telkens 3 aanzichten gegenereerd en op ware grootte afgedrukt. Deze werden op polystyreen schuimblokken aangebracht, waaruit de vormen gesneden werden. Zo konden respondenten de omvang inschatten en de vormen vastnemen.

Ook de schermgrootte was belangrijk. Daarom werden 4 schermgroottes afgedrukt met een screenshot van de interface. Deze konden modulair per vorm gewisseld worden, waardoor er 16 mogelijke combinaties waren.

<p align="center">
  
</p>
<p align="center">
fysieke prototypes</p>

Een bijkomend voordeel van de 3D-modellen was dat ze op 7 manieren gerenderd konden worden. Zo kregen respondenten een beeld van hoe het product er later kon uitzien.

<p align="center">
  
</p>
<p align="center">
render prototypes
</p>

**Materialen**

Voor de gebruikerstesten werden verschillende materialen gebruikt:

* Hoofdstationprototypes 

* Render

* Schermgrootte prototypes

* Smartphone voor interface demo 

* Valse plant 

* Smartphone voor opnames/foto's 

* Informed consent 

**Methoden**

De gebruikerstesten werden uitgevoerd bij de respondenten thuis om het product in een realistische context te evalueren. In totaal namen vijf deelnemers deel met verschillende profielen en niveaus van technologische ervaring.

Tijdens de testen gingen deelnemers in interactie met de prototypes. Vorm, schermgrootte en interface werden beoordeeld. De prototypes werden in de leefomgeving geplaatst, zodat het gebruik natuurlijk kon worden geobserveerd.

Via het Think Aloud Protocol (TAP) en Question Asking Protocol (QAP) werden handelingen, voorkeuren en problemen in kaart gebracht. Deze inzichten vormden de basis voor verdere ontwerpbeslissingen.

<p align="center">
  
</p>
<p align="center">
interactie gebruikerstest</p>

**Resultaten**

Uit de testen kwamen inzichten naar voren over vormgeving, schermgrootte en interface. Vormgeving bleek belangrijk voor hoe het product in het interieur wordt ervaren. Gebruikers gaven de voorkeur aan een compacte en elegante vorm. Vooral vorm 2 werd als aantrekkelijk, zacht en passend ervaren. Grotere vormen voelden lomp of dominant aan.

De schermgrootte had veel invloed op gebruiksgemak. Te kleine schermen maakten icoontjes moeilijk zichtbaar en zorgden voor fouten. Te grote schermen werden overdreven en storend gevonden. Gebruikers verkozen daarom een gebalanceerde schermgrootte die leesbaar is, zonder het compacte karakter te verliezen.

De interface werd algemeen als duidelijk en overzichtelijk ervaren. De plattegrond en apparatenlijst werden nuttig gevonden. Toch waren icoontjes niet altijd meteen duidelijk. Extra labels of een legende kunnen helpen. Ook mag de interface visueel aantrekkelijker worden, bijvoorbeeld met kleurcodering per ruimte en een zachtere vormgeving.

Efficiëntie en gebruiksgemak staan centraal. Gebruikers verwachten snelle en logische handelingen, zoals alle apparaten in een ruimte tegelijk selecteren. Ze verkiezen een systeem waarbij ze kiezen wat uitgeschakeld moet worden, in plaats van wat genegeerd moet worden. Extra informatie, zoals energieverbruik en periodieke overzichten, kan betrokkenheid verhogen.

### <ins>Kostenberekeing</ins>
Er werd een kostenberekening gedaan om de effectiviteit van de energiebesparing te bepalen.
Op basis van een realistisch referentiescenario wordt ruw geschat dat EcoLux €100 per jaar kan besparen, afhankelijk van het aantal gekoppelde toestellen, de instellingen, energieprijzen en het gedrag van het huishouden, zie [kostenberekening](https://github.com/Vic-Syryn/EcoLux/blob/main/onderzoek/kostenberekening%20ecolux.pdf).

### <ins>Conclusies en implicaties</ins>

De gebruikerstesten beantwoorden de centrale onderzoeksvragen. Voor het hoofdstation kwam vorm 2 het sterkst naar voren. Gebruikers willen een compacte en elegante vorm die in het interieur past. Het product mag aanwezig zijn, maar mag de ruimte niet domineren.

Voor schermgrootte en ergonomie verkiezen gebruikers een middelgroot scherm. Dit moet goed leesbaar zijn zonder te groot te worden. Kleine schermen zorgen voor fouten en frustratie, terwijl grote schermen overdreven aanvoelen. De schermhoek van 23° uit de Siemens Jack-simulatie werd tijdens de gebruikerstesten als aangenaam ervaren.

Voor de interface bleek dat de basis duidelijk is, maar verdere verfijning nodig blijft. Icoontjes moeten duidelijker zijn en extra uitleg kan helpen via labels of een legende. Ook kan de interface aantrekkelijker worden met kleurgebruik en een zachtere vormgeving. Gebruikers verwachten snelle interacties.
De kostenberekening moet niet beschouwd worden als een gegarandeerde besparing omdat dit afhangt van het aantal gekoppelde apparaten, gekozen instellingen, energieprijzen, gedrag van gezinsleden en de mate waarin de Ecolux wordt opgevolgd. Toch toont de berekening aan dat de EcoLux een financieële meerwaarde kan bieden.

Op basis van deze inzichten wordt EcoLux verder ontwikkeld als een product dat eenvoudig in gebruik is, goed past in het interieur en logisch werkt.

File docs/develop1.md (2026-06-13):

## Develop 1

Voor Develop 1 werden na de tussentijdse evaluatie enkele pivots gemaakt. Eerst werd de doelgroep aangepast. De focus verschoof van mensen die renoveren naar bewuste gezinnen die hun energieverbruik en energiekosten willen verlagen. Deze gezinnen zoeken een laagdrempelige manier om alle gezinsleden actief te betrekken. Uit verder onderzoek bleek dat deze doelgroep representatiever is en een grotere nood heeft.

Ook op vlak van ontwerp werd een duidelijke richting gekozen op basis van deze [scorematrix](https://github.com/Vic-Syryn/EcoLux/blob/main/onderzoek/Scorematrix_Develop_1_Conceptselectie.pdf). Hieruit bleek dat de slimme bloempot het meeste potentieel had. Dit ontwerp scoorde goed op esthetiek en gebruiksgemak. De pot vormt ook een passende metafoor voor EcoLux: hij ondersteunt een ecologischer levenswijze (Eco) en communiceert via licht (Lux).

### <ins>**Analyse en prioritering**</ins>

Bij de start van Develop 1 waren er nog enkele onzekerheden. Deze werden vertaald naar drie onderzoeksvragen:
1. Hoe moet het hoofdstation en substations eruitzien?
2. Hoe wordt het scherm geïnterageerd in het product?
3. Welke concepten hebben de meeste potentie om tot een sterk product te kunnen vertaald worden?

Het doel van deze fase was om op deze vragen een antwoord te krijgen. Alle drie waren even belangrijk voor de verdere ontwikkeling van EcoLux.

### <ins>**Deconstructie**</ins>

**Customer journey**

In de Customer Journey werd vooral ingezoomd op twee fasen: installatie en gebruik. Het doel was om de interacties van de gebruiker in kaart te brengen en waar mogelijk te optimaliseren.

<ins>Awareness</ins>

De gebruiker ervaart een hoge energiefactuur en wil besparen. Daarvoor moeten energieconsumptie en energieverliezen beperkt worden. Gebruikers willen dit met zo weinig mogelijk moeite doen, maar willen wel voldoende controle behouden. Er is dus nood aan een product dat energieverliezen minimaliseert en dit duidelijk communiceert.

<ins>Install</ins>
<p align="center">
  
</p>
<p align="center">
customer journey install</p>
<ins>Use</ins>
<p align="center">
  
</p>
<p align="center">
customer journey use</p>
<ins>Result</ins>

De energieconsumptie van de gebruiker daalt. Hierdoor bespaart hij of zij geld, wordt de ecologische voetafdruk kleiner en ontstaat er meer comfort rond energieverbruik thuis. Ook wordt het verlaten van het huis of gaan slapen makkelijker, omdat alle energieverbruikers uit gezet kunnen worden met 1 knop.

**Storyboards**

Op basis van de Use-fase in de Customer Journey werd een storyboard gemaakt. Hierin worden de verschillende interacties met het product visueel weergegeven.

<p align="center">
  
</p>
<p align="center">
  storyboard
</p>

**Productarchitectuur**

Op basis van het storyboard en Customer Journey werden de belangrijkste componenten en functies opgesteld.

<p align="center">
  
</p>
<p align="center">
productarchitectuur</p>

**Userflow en informatiearchitectuur**

De userflow visualiseert het volledige interactieproces tussen gebruiker en systeem. Ze toont hoe de gebruiker van het opmerken van energieverlies naar het aanpassen en oplossen ervan gaat. Zo wordt duidelijk waar interactie plaatsvindt.

<p align="center">
  
</p>
<p align="center">
userflow
</p>

De HTA toont de taken die nodig zijn om energieverliezen te beperken. De hoofddoelstelling wordt opgesplitst in drie taken: de gebruiker informeren, keuzes maken op het hoofdstation en het systeem terugbrengen naar de basisinstellingen. Elke taak wordt verder opgedeeld in subtaken.

<p align="center">
  
</p>
<p align="center">
HTA</p>

Uit de userflow en HTA bleek dat de communicatie van het type energieverlies nog verder bepaald moest worden.

**MVP-definitie**

Deze MVP’s tonen de minimale kernfunctionaliteiten van het systeem.

<p align="center">
  
</p>
<p align="center">
MVP</p>

### <ins>**Divergentie & ontwerpkeuzes**</ins>

**Morfologische matrix**

Op basis van de deconstructie werd een morfologische matrix gemaakt. Deze geeft een visueel overzicht van mogelijke deeloplossingen.

<p align="center">
  
</p>
<p align="center">
morfologische matrix</p>

### <ins>**Build & test**</ins>

**Doelstellingen** 

De gebruikerstesten hadden als doel om inzicht te krijgen in de meest efficiënte en aangename interactie met het scherm van EcoLux. Tijdens de userflow bleek er onzekerheid over hoe het scherm best tevoorschijn komt en opnieuw verdwijnt in de pot. Door prototypes te testen bij gebruikers thuis, werd onderzocht welke interacties het meest intuïtief, comfortabel en gebruiksvriendelijk zijn.

**Materiaal & methoden**

Voor de gebruikerstesten werden verschillende materialen gebruikt:

* Prototype van het EcoLux-hoofdstation

* Smartphone voor foto’s en video-opnames

* Informed consent-document voor toestemming van de deelnemers
<p align="center">
  
  
</p>
<p align="center">
fysiek prototype</p>

De testen werden uitgevoerd bij de respondenten thuis om het product in een realistische context te observeren. In totaal namen vijf deelnemers deel, met verschillende profielen en niveaus van technologische ervaring. Ze kregen taken zoals het scherm uit het prototype halen, dit herhalen op verschillende hoogtes, de kijkhoek aanpassen en het scherm terugplaatsen. Observaties werden genoteerd en aangevuld met vragen volgens TAP en QAP.

**Resultaten**

Uit de gebruikerstesten kwamen verschillende inzichten naar voren over de interactie met het scherm.

<p align="center">
  
</p>
<p align="center">
prototype bij gebruikerstest</p>

Een volledig handmatig uittrekbaar scherm bleek niet intuïtief. Deelnemers wisten niet altijd hoe ze het scherm moesten activeren. Een volledig automatisch systeem was ook niet ideaal, omdat het scherm op ongewenste momenten kon verschijnen. Gebruikers gaven daarom de voorkeur aan een duidelijke en gecontroleerde interactie, bijvoorbeeld via een knop.

Daarnaast beïnvloedde de plaatsing van de knop de stabiliteit. Wanneer de knop vooraan stond, schoof de pot naar achteren wanneer gebruikers erop drukten. Dit toont dat de stabiliteit en richting van de interactiekracht belangrijk zijn.

Ook de ergonomie van het scherm bleek belangrijk. Wanneer het product lager stond, bevond het scherm zich onder een ongunstige kijkhoek. Gebruikers gaven daarom aan dat de kijkhoek best aanpasbaar is.

Tot slot verwachtten gebruikers dat het scherm op dezelfde manier verdwijnt als het verschijnt. De meeste deelnemers drukten opnieuw op dezelfde knop. Dit wijst op een voorkeur voor consistente interacties.

### <ins>**Conclusies & implicaties**</ins>

De gebruikerstesten helpen de drie onderzoeksvragen te beantwoorden. Voor de interactie met het scherm werd duidelijk dat gebruikers een gecontroleerde en eenvoudige activatie verwachten. Zowel een volledig handmatig als volledig automatisch systeem was minder wenselijk. Consistentie is belangrijk: dezelfde handeling moet het scherm kunnen tonen en verbergen.

Voor het hoofdstation bleek stabiliteit essentieel. Het object mag niet verschuiven wanneer de gebruiker erop drukt. Ook de plaatsing van interactie-elementen moet zorgvuldig gekozen worden. Daarnaast moet het scherm ergonomisch leesbaar blijven op verschillende hoogtes.

De testfase gaf ook inzicht in het concept met het meeste potentieel. Het oorspronkelijke idee met een uitschuifbaar en kantelbaar scherm zorgde voor problemen rond gebruiksvriendelijkheid, stabiliteit en mechanische complexiteit. Het mechanisme maakte het ontwerp minder robuust en beperkte de ontwerpvrijheid van de bloempot.

Daarom werd beslist om het verborgen schermconcept te verlaten. Het scherm wordt geïntegreerd als zichtbaar en vast onderdeel van het productdesign. Zo verschuift EcoLux naar een eenvoudiger, robuuster en ergonomischer product, met gebruiksgemak, stabiliteit en betrouwbaarheid als basis.

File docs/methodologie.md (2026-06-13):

## Methodologie  
<p align="center">
  
</p>
<p align="center">
  triple diamond ontwerpmodel
</p>

Voor het ontwerpproces werd gebruikgemaakt van het triple diamond ontwerpmodel. Dit model bestaat uit vier fasen: discover, define, develop en deliver. In het eerste semester werden de discover- en definefase doorlopen. In het tweede semester lag de focus op de developfase waarin het concept iteratief werd uitgewerkt, getest en verfijnd.

<ins>**Discover fase**</ins>  
De discoveryfase richtte zich op het begrijpen waarom huishoudens, ondanks hun bereidheid om energie te besparen, dit gedrag moeilijk structureel volhouden. De focus lag op dagelijkse routines, perceptie en gebruikservaring, eerder dan op technische optimalisatie. Het doel was om de kloof tussen intentie en gedrag bloot te leggen en deze inzichten te vertalen naar onderbouwde ontwerpbeslissingen.

Via contextual inquiries bij drie verschillende huishoudtypes (N=3) werd energiegebruik in de natuurlijke wooncontext geobserveerd en besproken. Dit werd aangevuld met een benchmarkonderzoek naar bestaande slimme energieoplossingen. Hieruit bleek dat gebruikers hun energieverbruik zelden actief monitoren en vooral financieel gemotiveerd zijn om te besparen. Energieverspilling gebeurt vaak onbewust, onder meer door sluipverbruik, onnodig ingeschakelde toestellen en ventilatieverlies. Bestaande slimme oplossingen worden bovendien vaak als complex, technisch of belastend ervaren.

Het benchmarkonderzoek toonde aan dat de markt sterk data- en appgericht is, met weinig aandacht voor intuïtieve of ambient feedback. Daarom werd geconcludeerd dat een effectieve oplossing energieverlies automatisch moet detecteren en dit passief, visueel en begrijpelijk moet communiceren, zonder extra cognitieve belasting of verlies aan comfort.

<ins>**Define fase**</ins>  
De definefase werd opgesplitst in twee waves.

**Wave 1** onderzocht hoe het energieprobleem het best gecommuniceerd kan worden en welke installatie- en functionaliteitsopties aansluiten bij gebruikersverwachtingen. Hiervoor werden vier prototypes getest rond emotie, vorm, licht en substations via gebruikerstesten en interviews (N=3). Lichtsignalen bleken het duidelijkst en meest intuïtief. Emotionele communicatie, zoals smileys en spraak, werd begrepen maar was sterk contextafhankelijk: speels voor gezinnen, maar minder geschikt voor volwassen of zakelijke omgevingen. Personaliseerbaarheid, negeerknoppen, handsfree bediening en substations verhoogden het gebruiksgemak.

**Wave 2** richtte zich op de communicatie van energieverlies, automatisatie en de negeerfunctie. Via het Think Aloud Protocol en Question Asking Protocol werden drie interfaces getest (N=3): spraak, tekst en een grondplan. Spraak was duidelijk, maar traag bij veel informatie. Tekst was snel scanbaar, maar miste soms context. De grondplanweergave gaf onmiddellijk inzicht in de locatie van het energieverlies en maakte snelle actie mogelijk. Visuele communicatie, snelheid en automatisatie werden daarom belangrijke ontwerpprincipes.

<ins>**Develop fase**</ins>

Voor de developfase werd een pivot uitgevoerd. Uit interviews bleek dat binnen een gezin meestal één persoon actief bezig is met energiebewust gedrag. Daarom werd de doelgroep aangepast naar energiebewuste gezinnen die energieverspilling in hun huishouden willen vermijden en alle gezinsleden op een laagdrempelige manier willen betrekken.

De developfase werd opgesplitst in vier waves.

**Wave 1** richtte zich op het verder ontwikkelen van het concept en het testen van de basisinteractie. Via een scorematrix werd gekozen voor het concept van de slimme bloempot, omdat dit sterk scoorde op esthetiek, gebruiksgemak en aansluiting bij de ecologische positionering van EcoLux.

De interactie werd verder onderzocht via een customer journey, storyboards, productarchitectuur, userflows en een HTA. Hieruit bleek dat vooral de communicatie van energieverlies verder bepaald moest worden. Op basis daarvan werden de MVP-functionaliteiten gedefinieerd. Tijdens gebruikerstesten met een prototype van het hoofdstation (N=5) bleek dat een handmatig of automatisch uitschuifbaar scherm niet intuïtief genoeg was. Gebruikers gaven de voorkeur aan een stabiel object, duidelijke interactie en comfortabele kijkhoek. Daarom werd gekozen voor een vast geïntegreerd scherm.

**Wave 2** bouwde verder op deze eerste iteratie en focuste op vormgeving, schermgrootte en interface. Hiervoor werden meerdere fysieke prototypes ontwikkeld, waaronder verschillende vormvarianten en schermgroottes die modulair gecombineerd konden worden. De evaluatie gebeurde via gebruikerstesten in de thuiscontext van de deelnemers (N=5), zodat het gebruik in een realistische situatie kon worden geobserveerd.

Tijdens de testen gingen gebruikers in interactie met zowel de fysieke vorm als een digitale demoversie van de interface. Via TAP en QAP werden observaties gecombineerd met directe feedback. Er werd onderzocht hoe gebruikers de vormen ervaarden in hun interieur, hoe ze omgingen met verschillende schermgroottes en hoe intuïtief de interface werd begrepen. De kwalitatieve data werd geanalyseerd op terugkerende patronen en voorkeuren.

**Wave 3** richtte zich op gebruikerservaring, emotionele beleving en integratie in de woonomgeving. Eerst werd een customer journey opgesteld waarin het volledige gebruikstraject van EcoLux werd onderzocht, van bewustwording en installatie tot dagelijks gebruik en langdurige betrokkenheid. Hieruit bleek dat eenvoud, vertrouwen, transparantie en controle belangrijk blijven binnen smart-home automatisatie.

Daarnaast werd een CMF-analyse uitgevoerd. Op basis van referentieproducten, doelgroepanalyse en een morfologische matrix werden verschillende materiaal-, kleur- en afwerkingscombinaties ontwikkeld. Deze varianten werden getest via semigestructureerde interviews met vijf respondenten in hun thuisomgeving. Gebruikers kregen renders en een touch-and-feelbord te zien. De resultaten toonden een voorkeur voor zachte, natuurlijke kleuren, matte afwerkingen en warme materialen zoals hout of houtachtige texturen. Daarom werd gekozen voor een rustige, minimalistische vormtaal die subtiel aansluit bij het interieur.

**Wave 4** focuste op de technische uitwerking en validatie van EcoLux. In deze fase werd onderzocht of de kernfunctionaliteiten technisch haalbaar zijn. Het systeem werd opgebouwd rond vier onderdelen: het aanraakscherm, de software op een Raspberry Pi, de verbinding met slimme apparaten via Matter en een fysiek waarschuwingssysteem met Arduino en LED.

De Raspberry Pi fungeert als centrale hub en verwerkt informatie van de interface, slimme toestellen en het waarschuwingslampje. De software houdt bij welke apparaten gekoppeld zijn, waar ze zich bevinden en hoelang ze al ingeschakeld zijn. Wanneer een toestel langer aanstaat dan de ingestelde tijdsdrempel, kleurt de betrokken kamer rood op het scherm. Tegelijk stuurt de Raspberry Pi een signaal naar de Arduino, waardoor de LED oplicht als fysieke waarschuwing. De lichtsensor past de helderheid aan het omgevingslicht aan, terwijl de rotary encoder handmatige bijsturing mogelijk maakt.

Deze fase toonde aan dat de belangrijkste onderdelen van EcoLux technisch kunnen samenwerken. Het prototype kan apparaten opvolgen, waarschuwingen tonen en fysieke lichtfeedback activeren. Develop 4 vormde zo de stap van concept naar functioneel prototype.

De finale code van het prototype is terug te vinden in de [Source](https://github.com/Vic-Syryn/EcoLux/tree/main/src). De finale lijst met onderdelen is opgenomen in de [BOM](./bom.md).

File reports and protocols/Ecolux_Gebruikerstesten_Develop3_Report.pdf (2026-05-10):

# EcoLux Develop 3 - Report

### Projectinformatie

Projectnaam: EcoLux
Dit project onderzoekt hoe slimme, toegankelijke producten mensen kunnen helpen om thuis energie te besparen. De focus ligt op oplossingen die zowel financieel voordeel opleveren voor de gebruiker als milieuwinst genereren. Hierbij ligt de focus om het voor de gebruiker zo makkelijk mogelijk te maken.

Interviewer: Viktor Caluwaert (viktor.caluwaert@ugent.be), student Industrieel Ontwerpen aan de Universiteit Gent

### Doelstelling en kadering

Deze finale gebruikerstest kadert binnen de derde develop-fase, waarin de focus verschuift van functionele validatie naar UX, Service Design en CMF Excellence. Het concept en de usability zijn reeds voldoende gevalideerd; daarom ligt de nadruk nu op de emotionele beleving, esthetische verfijning en bredere gebruikscontext van het product.

Het doel van deze test is om verschillende prototypevarianten met elkaar te vergelijken en zo de finale ontwerpkeuzes te onderbouwen. Daarbij wordt onderzocht welke variant het best aansluit bij de noden en verwachtingen van de doelgroep op vlak van gebruikservaring, uitstraling, kleur, materiaal, afwerking en emotionele impact. De resultaten vormen de basis voor de laatste aanpassingen richting een overtuigend en professioneel eindontwerp.

### Onderzoeksvragen

- Welke kleurentint spreekt de gebruiker het meest aan?
- Welke textuur voelt het best voor de gebruiker?
- Welke voorkeur is er voor het (soort) materiaal?

### Methode

Voor dit onderzoek werd een kwalitatieve gebruikerstest uitgevoerd met vijf respondenten uit verschillende leeftijdsgroepen en met uiteenlopende technologische kennis. Tijdens interviews werden verschillende EcoLux-prototypevarianten beoordeeld op kleur, materiaal, textuur, afwerking en emotionele beleving. De deelnemers bekeken renders en gebruikten een touch-and-feelbord om materialen en afwerkingen tactiel en visueel te vergelijken. De gesprekken werden opgenomen na informed consent en afgesloten met een korte samenvatting van de belangrijkste inzichten. De resultaten werden nadien geanalyseerd via een root-causeanalyse om terugkerende patronen te vertalen naar ontwerpimplicaties en design requirements.

### Materialen

- Touch and feel bord
- Smartphone voor opnames/foto’s
- Informed consent
- Renders


### Respondenten

Steekproefomschrijving (N = 4)

pseudonym | Respndent type | interview date | Gebruikerstesten location
Marieke | Student (gezinslid) | 9/05/2026 | Haar huis
Jan | Huiseigenaar | 8/05/2026 | Zijn huis
Katrien | Grafisch ontwerper | 10/05/2026 | Haar ontwerpbureau
Basiel | Student (gezinslid) | 10/05/2026 | Zijn huis

### Raw data


### Data-analyse


Uit de interviews blijkt dat de respondenten de EcoLux vooral zien als een product dat zich op een rustige en natuurlijke manier moet integreren in het interieur. Het product mag aanwezig zijn, maar mag niet te sterk opvallen of als een technisch object aanvoelen. Respondenten geven aan dat de EcoLux visueel aantrekkelijk moet zijn zonder te overheersen. Een te opvallende of uitgesproken vormgeving zou ervoor kunnen zorgen dat het product minder snel een vaste plaats krijgt in de woning. Tegelijk mag het ontwerp ook niet te basic of generiek ogen, omdat dit afbreuk zou doen aan de kwaliteit en betrouwbaarheid die het product moet uitstralen.

Een belangrijk terugkerend inzicht is dat de EcoLux degelijkheid, betrouwbaarheid en duurzaamheid moet communiceren. Omdat het product gekoppeld is aan energiebesparing en bewust wonen, verwachten gebruikers een vormgeving die aansluit bij deze waarden. Materiaalkeuze speelt hierbij een grote rol. Hout kwam duidelijk naar voren als voorkeursmateriaal of als gewenste visuele uitstraling. De respondenten linken hout aan warmte, natuurlijkheid en duurzaamheid. Hierdoor sluit het materiaal goed aan bij de identiteit van EcoLux en bij het idee van een toegankelijk, milieubewust product voor thuisgebruik.

Op vlak van kleur hadden de respondenten vooral een voorkeur voor lichtere, zachtere en natuurlijke tinten, zoals de eerste render. Deze kleuren worden als minder storend ervaren in een interieur en passen beter bij verschillende woonstijlen. Te donkere of te felle kleurcombinaties kunnen het product zwaarder of opvallender maken, terwijl een te neutrale kleur het product juist te eenvoudig of goedkoop kan doen lijken. De ideale kleurcombinatie bevindt zich dus tussen subtiel en karaktervol: rustig genoeg om in een woning te passen, maar met voldoende detail of contrast om het product een kwalitatieve uitstraling te geven. Op Figuur 1 valt de meest gekozen render te zien.


Figuur 1: meest gekozen render

Bij de beoordeling van textuur kwam een verschil naar voren tussen visuele textuur en tactiele textuur. De meeste respondenten wilden liever geen uitgesproken voelbare textuur, omdat dit mogelijk minder aangenaam aanvoelt of sneller vuil kan verzamelen. Wel werd een natuurlijke nerfstructuur visueel positief beoordeeld, vooral wanneer die subtiel aanwezig is in het materiaal of de afwerking. Dit wijst erop dat gebruikers de natuurlijke uitstraling van hout waarderen, maar dat het oppervlak in gebruik best glad, aangenaam en eenvoudig te onderhouden blijft.

### Key Insights & Ontwerpimplicaties

Key insight | Ontwerpimplicatie
Respondenten willen dat de EcoLux niet te hard opvalt in het interieur. | Kies voor een rustige vormgeving en zachte, natuurlijke kleuren die passen binnen verschillende woonstijlen.
Het product mag niet te basic of goedkoop ogen. | Voorzie voldoende detail in materiaal, afwerking of kleurcontrast zodat het product kwalitatief aanvoelt.
Hout of een houtachtige uitstraling wordt sterk geassocieerd met duurzaamheid en warmte. | Gebruik hout, fineer of een materiaalafwerking met natuurlijke houtlook als belangrijk visueel element.
Gebruikers verkiezen lichte tinten, maar niet zonder karakter. | Werk met lichte basistinten in combinatie met subtiele accenten of natuurlijke nerven.
Voelbare textuur wordt minder gewenst, maar visuele nerven worden positief beoordeeld. | Kies voor een glad of mat oppervlak met een subtiele zichtbare houtstructuur.
De EcoLux moet betrouwbaar en degelijk aanvoelen. | Vermijd glanzende, plasticachtige of te speelse afwerkingen; focus op een rustige en professionele uitstraling.

### Design Requirements

Op basis van deze data werden er nieuwe design requirements gemaakt:

6.1 De EcoLux moet visueel passen binnen verschillende interieurs zonder te dominant aanwezig te zijn.
6.2 De kleurkeuze moet gebaseerd zijn op lichte, natuurlijke en zachte tinten, eventueel gecombineerd met een subtiel kleuraccent.
6.3 Het materiaal of de materiaaluitstraling moet duurzaamheid en warmte communiceren. 6.4 Het oppervlak moet aangenaam en praktisch zijn in dagelijks gebruik, bij voorkeur glad of mat en eenvoudig schoon te maken.
6.5 De tactiele textuur mag niet storend of ruw aanvoelen.
6.6 De finale CMF-keuze moet de waarden van EcoLux ondersteunen: toegankelijkheid, duurzaamheid, eenvoud en financieel voordeel.

### Overtuigingskracht van interpretatie

De interpretatie van de resultaten is overtuigend omdat meerdere respondenten gelijkaardige voorkeuren aangaven rond kleur, materiaal en textuur. Vooral de voorkeur voor een natuurlijke, rustige en betrouwbare uitstraling kwam duidelijk naar voren. Door zowel renders als een touch-and-feelbord te gebruiken, konden de respondenten de prototypes niet alleen visueel beoordelen, maar ook tactiel ervaren. Dit maakt de resultaten sterker dan wanneer enkel beelden zouden zijn getoond.
Wel blijft de steekproef beperkt, waardoor de resultaten niet volledig representatief zijn voor de volledige doelgroep. De conclusies moeten daarom gezien worden als richtinggevend. Toch vormen de terugkerende voorkeuren voor hout, lichte natuurlijke kleuren en een subtiele afwerking een duidelijke basis voor de finale ontwerpkeuzes. Deze keuzes sluiten bovendien goed aan bij de waarden van EcoLux: duurzaamheid, toegankelijkheid en betrouwbaarheid.

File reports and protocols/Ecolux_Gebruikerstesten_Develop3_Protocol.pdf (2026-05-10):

# EcoLux Develop 3 - Protocol

### Projectinformatie

Projectnaam: EcoLux
Dit project onderzoekt hoe slimme, toegankelijke producten mensen kunnen helpen om thuis energie te besparen. De focus ligt op oplossingen die zowel financieel voordeel opleveren voor de gebruiker als milieuwinst genereren. Het doel is om het voor de gebruiker zo gemakkelijk mogelijk te maken.

Interviewer: Viktor Caluwaert (viktor.caluwaert@ugent.be) , student Industrieel Ontwerpen aan de Universiteit Gent.

### Doelstelling en kadering

Deze finale gebruikerstest kadert binnen de derde develop-fase, waarin de focus verschuift van functionele validatie naar UX, Service Design en CMF Excellence. Het concept en de usability zijn reeds voldoende gevalideerd; daarom ligt de nadruk nu op de emotionele beleving, esthetische verfijning en bredere gebruikscontext van het product.

Het doel van deze test is om verschillende prototypevarianten met elkaar te vergelijken en zo de finale ontwerpkeuzes te onderbouwen. Daarbij wordt onderzocht welke variant het best aansluit bij de noden en verwachtingen van de doelgroep op vlak van gebruikservaring, uitstraling, kleur, materiaal, afwerking en emotionele impact. De resultaten vormen de basis voor de laatste aanpassingen richting een overtuigend en professioneel eindontwerp.

### Prototypes

Het touch and feel bord werd gemaakt om verschillende materialen te gelijkertijd kunnen voelen en bekijken op een overzichtelijke manier.

### Respondenten

Een selectie van jongere en oudere mensen met een verschillende kennis van technologie in hun thuisomgeving. Deze werden gekozen omdat ze een representatie geven van onze brede doelgroep.

De interviews duren 30 min en worden afgenomen van 7-9 mei 2026.

Steekproefomschrijving (N = 5)

pseudonym | Respndent type | interview date | Gebruikerstesten location
Marieke | Student (gezinslid) | 9/05/2026 | Haar huis
Jan | Huiseigenaar | 8/05/2026 | Zijn huis
Katrien | Grafisch ontwerper | 10/05/2026 | Haar ontwerpbureau
Basiel | Student (gezinslid) | 10/05/2026 | Zijn huis

### Materialen

- Touch and feel bord
- Smartphone voor opnames/foto’s
- Informed consent
- Renders

### Onderzoeksvragen

- Welke kleurentint spreekt de gebruiker het meest aan?
- Welke textuur voelt het best voor de gebruiker?
- Welke voorkeur is er voor het (soort) materiaal?

### Overzicht van de discussiegids en tijdsinschatting

### Discussiegids

### Introductie (5’)

Bedankt voor je deelname aan dit onderzoek.

Ik zal starten met het project en ons voor te stellen.

Wij zijn Vic Syryn, Viktor Caluwaert en Yenthe Bode en wij studeren aan de Universiteit Gent campus Kortrijk met afstudeerrichting industrieel ingenieur industrieel ontwerpen.

Deze gebruikerstest maakt deel uit van ons project Ecolux. De Ecolux is een thuisassistent die helpt de gebruiker energie te besparen. Door overal in je huis slimme technologie te plaatsen, is de EcoLux altijd op de hoogte van waar je energie verbruikt en dus ook waar je er verliest. Bijvoorbeeld: iemand vergeet het licht uit te doen in de badkamer waardoor er energie verloren gaat, de EcoLux laat dit weten aan de gebruiker en lost dit indien gewenst zelf op. Een ander voorbeeld: stel dat je de verwarming aan laat en je raam staat nog open in je slaapkamer, laat de EcoLux dit opnieuw weten en kan je dan zelf kiezen om je raam toe te doen. Finaal heb je nog de huis-verlaat-schakelaar/ schakelaar bij het slapen gaan. Wanneer je het huis wil verlaten, zal de EcoLux eerst nagaan of er energie verloren gaat terwijl je weg bent. Hij laat dit dan weten en regelt zelf lichten en sluit sluipverbruikers af... waar nodig.

Deze gebruikerstesten focussen op welke kleur, materiaal en finish jij als gebruiker het beste ervaart.

We willen zeker nog onderstrepen dat alles wat straks in het gesprek aan bod komt in absolute confidentialiteit behandeld wordt. We zijn als studenten aan de Ugent namelijk gebonden aan de Europese privacyrichtlijnen. Voor de synthese met de inzichten en aanbevelingen worden individuele meningen sowieso ook geanonimiseerd. Je naam zal met andere woorden niet gekoppeld worden aan specifieke uitspraken. Een meer gedetailleerde beschrijving van onze intenties, verwerking van gegevens, en algemeen beleid kan je nalezen in de ‘Informed Consent’. Voor we van start kunnen met de gebruikertesten, heb ik jouw expliciet akkoord nodig met dit document.

Ten slotte, vroegen we ons af of we straks dit gesprek mogen opnemen/filmen, om ons gesprek en je handelingen achteraf te kunnen bekijken en analyseren. Uiteraard wordt deze opname niet gedeeld met derden, en verwijderd na afloop van het project. Als u hiermee akkoord gaat, stel ik voordat we het interview beginnen.

[invullen informed consent & start recording]

### Framing questions

Voorstelling Interviewee (5’)

Alvorens we in de materie duiken, wil ik graag eerst even kennismaken.

- Kan je kort iets over jezelf vertellen en met wie je samenwoont?
- Hoe ziet je huishouden eruit (alleen, met partner, gezin, huisgenoten…)?
- Kan je wat vertellen over je woning?
- Woon je in een huis of appartement?

### Testen prototype en interview

Waar zou je dit product in je woning plaatsen en waarom?
Moet dit product opvallen of net opgaan in je interieur?
Welke emoties zou een product zoals EcoLux volgens jou idealiter moeten oproepen?

Welke variant sluit daar het best bij aan? Waarom?

### Renders

Welke render spreekt je het meest aan en waarom? Welke render spreekt je het minst aan en waarom?
Als je alleen naar kleur kijkt, welke krijgt dan de voorkeur? Als je alleen naar textuur kijkt, welke krijgt de voorkeur?

### Touch and feel bord

Bij het touch and feel bord worden verschillende aspecten met elkaar vergeleken:
- Mat vs glanzend, en waarom?
- Glad hout vs nerven hout, en waarom?
- Glad kunststof vs textuur kunststof, en waarom?
- Glad hut vs textuur hout, en waarom
Heb je een over het algemeen voorkeur voor hout of kunststof op basis van tactiliteit, en waarom?

### Wrap-up

Wenst u zelf nog zaken toe te voegen?

De belangrijkste zaken die ik heb geleerd uit deze gebruikerstesten zijn, … Heb ik het juist begrepen als …?
Wat zijn de belangrijkste elementen waarvan u denkt dat ik die het meest zou moeten onthouden?

Hartelijk bedankt voor uw deelname, dit was erg waardevol voor het verdere onderzoek. Wilt u op de hoogte blijven van verdere resultaten of andere gebruikerstesten?

### Data-analyse

De resultaten van dit onderzoek worden opgenomen in een afzonderlijk rapport: EcoLux_Report_Gebruikerstesten_Develop_3. Op basis van deze resultaten werd een root-cause analysis uitgevoerd om terugkerende patronen in gedrag, attitudes en motivaties van de gebruikers te identificeren. De belangrijkste inzichten uit deze analyse werden vervolgens vertaald naar ontwerpimplicaties en design requirements.

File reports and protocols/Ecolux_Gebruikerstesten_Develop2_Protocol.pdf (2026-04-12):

# EcoLux Develop 2 - Protocol

### Projectinformatie

Projectnaam: EcoLux
Dit project onderzoekt hoe slimme, toegankelijke producten mensen kunnen helpen om thuis energie te besparen. De focus ligt op oplossingen die zowel financieel voordeel opleveren voor de gebruiker als milieuwinst genereren. Het doel is om het voor de gebruiker zo gemakkelijk mogelijk te maken.

Interviewer: Yenthe Bode (Yenthe.Bode@ugent.be), student Industrieel Ontwerpen aan de Universiteit Gent.

### Doelstelling en kadering

Met dit onderzoek worden er 3 zaken onderzocht omtrent vorm en het scherm van het hoofdstation. Er wordt allereerst gepeild naar welke vorm er wordt ervaren als het meest esthetisch en praktisch. Naast de vormen worden er meerdere schermgroottes getest die modulair op de verschillende vormen passen. Op het scherm zal een demoversie van de interface te zien zijn. Ook wordt er gekeken of de hoek die bepaald werd in het document ‘Ergonomie scherm – Siemens Jack’ in de realiteit als aangenaam wordt ervaren.

### Prototypes

De volgende prototypes worden gemaakt:

- 4 vormprototypes uit schuim op basis van de resultaten van de scorematrix. Daarnaast worden er renders meegegeven om te tonen hoe het product er zou kunnen uit zien.
- 3 schermen met verschillende groottes, die magnetisch kunnen verwisseld worden. Waarop een beeld wordt gekleefd van ons app/interface
- Een demo van onze interface op een smartphone

### Respondenten

Een selectie van jongere en oudere mensen met een verschillende kennis van technologie in hun thuisomgeving. Deze werden gekozen omdat ze een representatie geven van onze brede doelgroep.

De interviews duren 1 uur en worden afgenomen van 9 tot 12 april 2026.

Steekproefomschrijving (N = 5)

pseudonym | respondent type | interview date | interview location
Evelyne | Interieurarchitect | 09/04/26 | Appartement resdpondent
Sabine | Zelfstandige die energie wil besparen | 10/04/26 | Huis respondent
Alain | Renovatie expert | 11/04/26 | Huis respondent
Nathan | Verpleger en jonge vader | 12/04/26 | Huis respondent
Sofie | Verzekeringsagent en jonge moeder | 12/04/26 | Huis respondent

### Materialen

- Hoofdstationprototypes
- Schermgrootte prototypes
- Smartphone voor interface demo
- Valse plant
- Smartphone voor opnames/foto’s
- Informed consent

### Onderzoeksvragen

1. Welke vorm is het meest esthetisch en praktisch?
2. Wat is de minimale schermgrootte zodat alles goed leesbaar is?
3. Welke hoek van het scherm is het meest ergonomisch?
4. Hoe wordt de eerste versie van de interface onthaald?

### Overzicht van de discussiegids en tijdsinschatting

### Discussiegids

### Introductie (5’)

Bedankt voor je deelname aan dit onderzoek.

Ik zal starten met het project en ons voor te stellen.

Wij zijn Vic Syryn, Viktor Caluwaert en Yenthe Bode en wij studeren aan de Universiteit Gent campus Kortrijk met afstudeerrichting industrieel ingenieur industrieel ontwerpen.

Deze gebruikerstest maakt deel uit van ons project Ecolux. De Ecolux is een thuisassistent die helpt de gebruiker energie te besparen. Door overal in je huis slimme technologie te plaatsen, is de EcoLux altijd op de hoogte van waar je energie verbruikt en dus ook waar je er verliest. Bijvoorbeeld: iemand vergeet het licht uit te doen in de badkamer waardoor er energie verloren gaat, de EcoLux laat dit weten aan de gebruiker en lost dit indien gewenst zelf op. Een ander voorbeeld: stel dat je de verwarming aan laat en je raam staat nog open in je slaapkamer, laat de EcoLux dit opnieuw weten en kan je dan zelf kiezen om je raam toe te doen. Finaal heb je nog de huis-verlaat-schakelaar/ schakelaar bij het slapen gaan. Wanneer je het huis wil verlaten, zal de EcoLux eerst nagaan of er energie verloren gaat terwijl je weg bent. Hij laat dit dan weten en regelt zelf lichten en sluit sluipverbruikers af... waar nodig.

Deze gebruikerstesten focussen op welke vorm, schermgrootte en hoek jij als gebruiker het beste ervaart. Ook wordt er gekeken hoe jij omgaat met de interafce in zijn huidige staat.

We willen zeker nog onderstrepen dat alles wat straks in het gesprek aan bod komt in absolute confidentialiteit behandeld wordt. We zijn als studenten aan de Ugent namelijk gebonden aan de Europese privacyrichtlijnen. Voor de synthese met de inzichten en aanbevelingen worden individuele meningen sowieso ook geanonimiseerd. Je naam zal met andere woorden niet gekoppeld worden aan specifieke uitspraken. Een meer gedetailleerde beschrijving van onze intenties, verwerking van gegevens, en algemeen beleid kan je nalezen in de ‘Informed Consent’. Voor we van start kunnen met de gebruikertesten, heb ik jouw expliciet akkoord nodig met dit document.

Ten slotte, vroegen we ons af of we straks dit gesprek mogen opnemen/filmen, om ons gesprek en je handelingen achteraf te kunnen bekijken en analyseren. Uiteraard wordt deze opname niet gedeeld met derden, en verwijderd na afloop van het project. Als u hiermee akkoord gaat, stel ik voordat we het interview beginnen.

[invullen informed consent & start recording]

### Framing questions

Voorstelling Interviewee (5’)

Alvorens we in de materie duiken, wil ik graag eerst even kennismaken.

- Kan je kort iets over jezelf vertellen en met wie je samenwoont?

- Hoe ziet je huishouden eruit (alleen, met partner, gezin, huisgenoten…)?
- Kan je wat vertellen over je woning?
- Woon je in een huis of appartement?

### Testen prototype en interview

### Vorm

- Welke vorm spreekt u het meest aan en waarom?
- Welke vorm lijkt u het meest praktisch in gebruik?
- Zijn er vormen die u minder aantrekkelijk vindt? Waarom?

### Schermgrootte

- Welke schermgrootte vindt u het meest aangenaam om af te lezen?
- Bij welke grootte vindt u de informatie het duidelijkst?
- Is er een scherm dat u te groot of te klein vindt? Waarom?
- Zou u liever een compact of groter scherm hebben in uw woning?

### Schermhoek

- Hoe ervaart u de kijkhoek van het scherm?
- Moet u zich aanpassen (buigen/verplaatsen) om het scherm goed te zien?
- Voelt deze hoek natuurlijk aan in gebruik?
- In welke positie (staand/zittend) zou u dit toestel meestal gebruiken?

### Interface

- Wat is uw eerste indruk van de interface?
- Begrijpt u onmiddellijk wat u op het scherm ziet?
- Welke informatie vindt u het meest nuttig?
- Mist u bepaalde informatie of functies?

### Wrap-up

Wenst u zelf nog zaken toe te voegen?

De belangrijkste zaken die ik heb geleerd uit deze gebruikerstesten zijn, … Heb ik het juist begrepen als …?
Wat zijn de belangrijkste elementen waarvan u denkt dat ik die het meest zou moeten onthouden?

Hartelijk bedankt voor uw deelname, dit was erg waardevol voor het verdere onderzoek. Wilt u op de hoogte blijven van verdere resultaten of andere gebruikerstesten?

### Data-analyse

De resultaten van dit onderzoek worden opgenomen in een afzonderlijk rapport: EcoLux_Report_Gebruikerstesten_Develop_2. Op basis van deze resultaten werd een root-cause analysis uitgevoerd om terugkerende patronen in gedrag, attitudes en motivaties van de gebruikers te identificeren. De belangrijkste inzichten uit deze analyse werden vervolgens vertaald naar ontwerpimplicaties en design requirements.

# INFORMATIE- EN

# TOESTEMMINGSFORMULIER

Doelpubliek: Bewuste gezinnen die hun energieverbruik en energiekosten willen verlagen en op zoek zijn naar een laagdrempelige manier om alle gezinsleden actief te betrekken.

Anonieme dataverzameling: Er wordt een anonieme opname gemaakt en geen persoonsgegevens verzameld.

Taal: Nederlands

## LUIK 1 – INFORMATIEBRIEF VOOR DEELNEMERS AAN DE

## GEBRUIKERTESTEN

Titel van het project: EcoLux

Deze gebruikerstest wordt uitgevoerd door een student die een opleiding volgt aan de Universiteit Gent, Industrieel ingenieur industrieel ontwerpen. Dit gebeurt binnen het vak Project Gebruiksgericht Ontwerpen (E620900A). De verantwoordelijke lesgever is:

Bas Baccarne
Socio-technologist and professor of design methodology
Design.Nexus
Universiteit Gent
E-mail: Bastiaan.Baccarne@UGent.be
A. Informatie over de gebruikerstest

Beste,

U wordt uitgenodigd om deel te nemen aan een gebruikerstest dat kadert binnen de opleiding Industrieel Ingenieur Industrieel Ontwerpen, vak Project Gebruiksgericht Ontwerpen aan de Universiteit Gent campus Kortrijk. Neem voldoende tijd om deze informatiebrief aandachtig te lezen voor u beslist deel te nemen aan deze gebruikertest. Aarzel niet om vragen te stellen aan de student-onderzoeker indien er onduidelijkheden zijn of indien u bijkomende informatie wenst. Zorg ervoor dat je alles begrijpt. Eens u beslist heeft om deel te nemen aan deze gebruikertesten zal men u vragen om het toestemmingsformulier achteraan deze bundel te ondertekenen.

Wat is het doel van de gebruikerstesten?

Met dit onderzoek worden er 3 zaken onderzocht omtrent vorm en het scherm van het hoofdstation. Er wordt allereerst gepeild naar welke vorm er wordt ervaard als het meest esthetisch en praktisch. Naast de vormen worden er meerdere schermgroottes getest die modulair op de verschillende vormen passen. Op het scherm zal een demoversie van het interface te zien zijn. Ook wordt er gekeken of de hoek die bepaald werd in het document ‘Ergonomie scherm – Siemens Jack’ in de realiteit als aangenaam wordt ervaren.

Informatie over Privacy en Persoonsgegevens

In deze studie worden geen persoonsgegevens verzameld. Alle gegevens die worden verzameld zijn van bij aanvang anoniem. Dit betekent dat wij noch andere personen je identiteit kunnen afleiden uit de verzamelde gegevens of deze gegevens kunnen koppelen aan uw identiteit. De data die gebruikt worden zijn geluidsopnames en video’s.

B. Informatie over deelname aan de gebruikerstest

Wat houdt deelnemen aan deze gebruikerstest in?

De deelname aan deze gebruikerstest is volledig vrijwillig en er kan op geen enkele manier sprake zijn van dwang. U kunt weigeren om deel te nemen aan deze gebruikerstest en u kunt zich op elk ogenblik terugtrekken uit de gebruikerstest zonder dat u hiervoor een reden moet opgeven.

Indien u dit wenst, kan u een samenvatting van de onderzoeksbevindingen krijgen nadat het ontwerpproces is afgerond en de resultaten bekend zijn. Om een samenvatting te krijgen kan u dit aanvragen bij de onderzoeker waarmee u contact hebt.


## LUIK 2 – TOESTEMMINGSFORMULIER

A. Toestemming m.b.t. deelname aan de gebruikerstest
Gelieve het juiste vakje aan te kruisen | ja | nee
Ik neem vrijwillig deel aan deze gebruikerstest en geef toestemming aan de student-onderzoeker om mijn gegevens anoniem te verwerken, ze te bewaren, te analyseren en er over te rapporteren. | o | o
Ik weet dat ik me op elk ogenblik uit de gebruikerstest mag terugtrekken zonder een reden voor deze beslissing op te geven. | o | o
Ik heb het informatieformulier gelezen en heb voldoende uitleg gekregen over de aard, het doel en de duur van de gebruikerstest. Ik kreeg de gelegenheid om vragen te stellen en ik heb op al mijn vragen een bevredigend antwoord gekregen. | o | o
Naam deelnemer | Naam onderzoeker
Datum: | Datum:
Handtekening | Handtekening

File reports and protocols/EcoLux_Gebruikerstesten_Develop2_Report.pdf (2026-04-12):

# EcoLux Develop 2 - Report

### Projectinformatie

Projectnaam: EcoLux
Dit project onderzoekt hoe slimme, toegankelijke producten mensen kunnen helpen om thuis energie te besparen. De focus ligt op oplossingen die zowel financieel voordeel opleveren voor de gebruiker als milieuwinst genereren. Hierbij ligt de focus om het voor de gebruiker zo makkelijk mogelijk te maken.

Interviewer: Yenthe Bode (Yenthe.Bode@ugent.be), student Industrieel Ontwerpen aan de Universiteit Gent

### Doelstelling en kadering

Met dit onderzoek worden er 3 zaken onderzocht omtrent de vorm en het scherm van het hoofdstation. Er wordt allereerst gepeild naar welke vorm er wordt ervaren als het meest esthetisch en praktisch. Naast de vormen worden er meerdere schermgroottes getest die modulair op de verschillende vormen passen. Op het scherm zal een demoversie van de interface te zien zijn. Ook wordt er gekeken of de hoek die bepaald werd in het document ‘Ergonomie scherm – Siemens Jack’ in de realiteit als aangenaam wordt ervaren.

### Onderzoeksvragen

1. Welke vorm is het meest esthetisch en praktisch?
2. Wat is de minimale schermgrootte zodat alles goed leesbaar is?
3. Welke hoek van het scherm is het meest ergonomisch?
4. Hoe wordt de eerste versie van de interface onthaald?

### Methode

Gekozen methode: gebruikerstesten bij de mensen thuis. Voor elk prototype wordt het volgende getest a.d.h.v het TAP en QAP:

### Motivatie volgens checklist

- We wilden gedrag in context zien → daarom gebruikerstest
- We wilden ook motivaties en voorkeuren achterhalen → vandaar a.d.h.v het TAP en QAP
- De methode laat ons feedback op prototypes verzamelen om tot een goede interactie te komen met de interface: scherm
- Deze methode is praktijkgericht, snel uitvoerbaar en geschikt voor conceptevaluatie

### Korte versie van het protocol

(Volledig protocol in Ecolux_Protocol_Gebruikerstesten_Develop_2.docx)

- Introductie & informed consent
- Presentatie concept EcoLux
- Testen worden uitgevoerd
- De verschillende vormen worden een voor een opgesteld in de gebruikscontext.
- De gebruiker gaat in interactie met de verschillende prototypes.
- De gebruiker gaat in interactie met de interface.

Materialen:

- Hoofdstationprototypes: Figuur 1
- Render: Figuur 2
- Schermgrootte prototypes: Figuur 3
- Smartphone voor interface demo
- Valse plant
- Smartphone voor opnames/foto’s
- Informed consent


Figuur 1: Vormprototypes


Figuur 3: Schermgrootte prototypes

Figuur 2: renders

### Respondenten

Steekproefomschrijving (N = 5)

pseudonym | Respndent type | interview date | Gebruikerstesten location
| | | respondent
| energie wil besparen | 10/04/26 | Huis respondent
Evelyne | Interieurarchitect | 09/04/26 | Appartement
Sabine | Zelfstandige die
Alain | Renovatie expert | 11/04/26 | Huis respondent
Nathan | Verpleger en jonge
vader | 12/04/26 | Huis respondent
jonge moeder | 12/04/26 | Huis respondent
Sofie | Verzekeringsagent en

### Raw data

Er werd tijdens de gebruikerstesten notities genomen van wat de gebruikers allemaal te zeggen hadden. Verder kan men op Figuur 3 de contexten zien van de respondenten 2 en
3. Op basis van deze data werden er analyses uitgevoerd en conclusies getrokken.



Figuur 4: Gebruikscontext
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

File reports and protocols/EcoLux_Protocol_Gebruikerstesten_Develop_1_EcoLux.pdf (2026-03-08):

# EcoLux Develop 1 - Protocol

### Projectinformatie

Projectnaam: EcoLux
Dit project onderzoekt hoe slimme, toegankelijke producten mensen kunnen helpen om thuis energie te besparen. De focus ligt op oplossingen die zowel financieel voordeel opleveren voor de gebruiker als milieuwinst genereren. Het doel is om het voor de gebruiker zo gemakkelijk mogelijk te maken.

Interviewer: Syryn Vic (vic.syryn@ugent.be), student Industrieel Ontwerpen aan de Universiteit Gent.

### Doelstelling en kadering

Bij het opstellen van de user flow werd er opgemerkt dat er een onzekerheid is in verband met de interactie om het scherm tevoorschijn te laten komen.

Met dit onderzoek willen we beter begrijpen wat de meest efficiente en aangename interactie is om het scherm te onthullen. Hierdoor is het dus belangrijk om feedback te krijgen van verschillende respondenten om hieruit de nodige inzichten te verkrijgen en conclusies te trekken. Deze gebruikerstesten worden gemaakt om van concept naar een onderbouwde functionele architectuur te gaan.
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

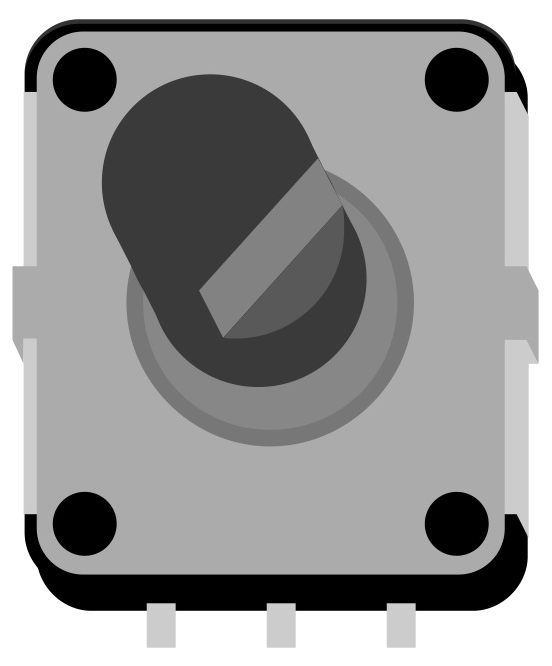
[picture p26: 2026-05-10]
img/Ecolux_Circuit-10.png

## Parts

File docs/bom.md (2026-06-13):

# Bill of materials
Begin define fase:
* karton
* magneettape
* ductape
* lijm
* papiertape

Eind define fase:
* ledstrip
* touch screen scherm
* hout
* PLA
* Rasberry Pi
* Arduino Uno
* LDR lichtsensor
* smartplug
* smartswitch

# Assembly

## <ins/> Deel 1: Elektronica
## Stap  1: Circuit bouwen
<ins/>Benodigdheden:

- Raspberry Pi (3B+) met Raspberry PI OS
- Arduino Uno
- LDR (lichtsensor)
- WS2812 LED strip (27 LED's, 5V)
- 10kΩ weerstand (voor LDR voltage divider)
- 470Ω weerstand (op data-lijn LED strip)
- USB-A naar USB-B kabel (Pi naar Arduino)
- 5V voeding (minimaal 2A voor Pi + Arduino, strip apart of via Pi bij 27 LED's)
- Jumper wires

Bouw het circuit volgens het onderstaande schema.

<p align="center">
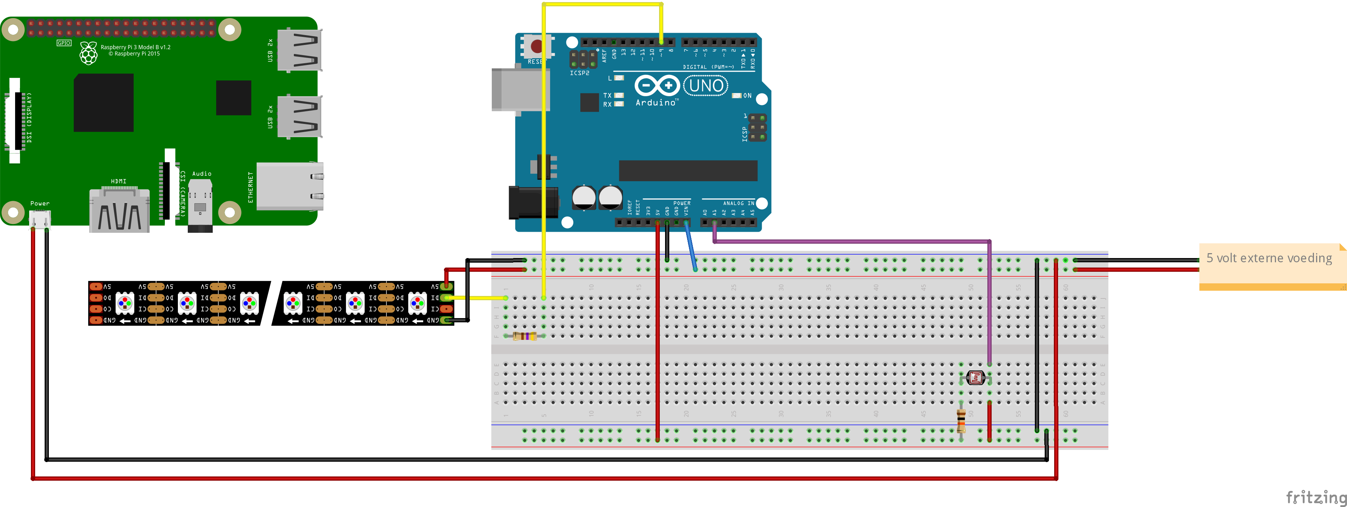
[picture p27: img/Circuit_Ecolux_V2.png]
  
  Circuit hoofdstation
<p align="center">

<p align="center">
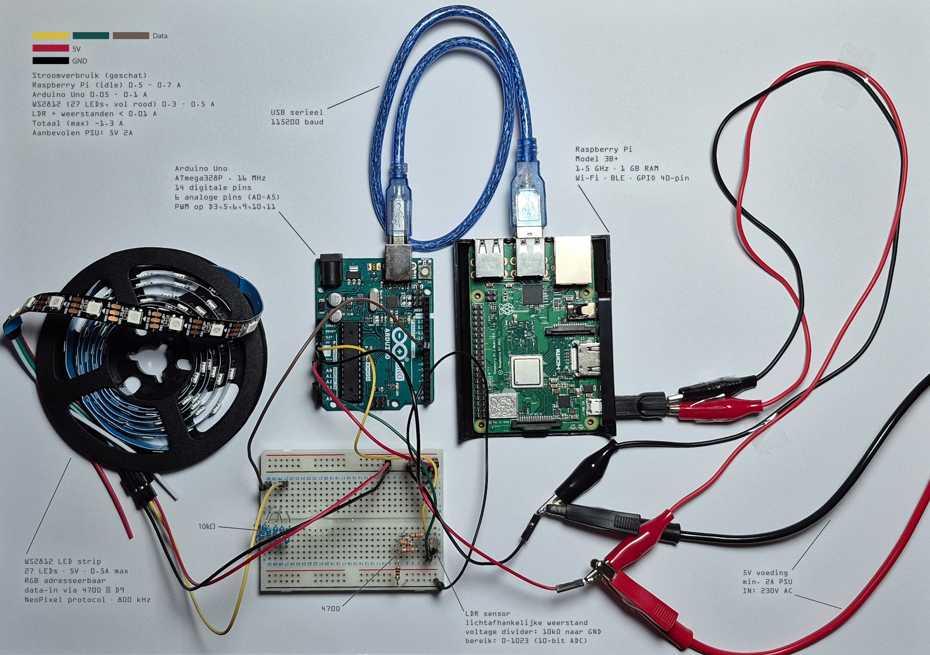
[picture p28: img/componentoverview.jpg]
  
  Component overview
<p align="center">

## Stap  2: Arduino sketch flashen
1. Open de Arduino IDE op je computer
2. Installeer de **Adafruit NeoPixel** library:
   - Sketch → Include Library → Manage Libraries
   - Zoek "Adafruit NeoPixel" → Install
3. Open `arduino_sketch.ino` Deze file is te vinden in [Hardware](https://github.com/Vic-Syryn/EcoLux/tree/main/src/Hardware)
4. Pas indien nodig de kalibratie aan:
```cpp
   const int LDR_DARK   = 822;  // ADC waarde bij volledig afgedekte LDR
   const int LDR_BRIGHT = 972;  // ADC waarde bij directe lamp op LDR
```
5. Selecteer het juiste board: **Tools → Board → Arduino Uno**
6. Selecteer de juiste poort: **Tools → Port**
7. Klik **Upload**

## Stap 3: Raspberry pi
### 1:
SSH naar de Pi of open een terminal:
 
```bash
# Update het systeem
sudo apt update && sudo apt upgrade -y
 
# Installeer Python dependencies
pip3 install pyserial requests --break-system-packages
```
 
---
### 2:
#### Node.js installeren op de Pi
 
```bash
curl -fsSL https://deb.nodesource.com/setup_18.x | sudo -E bash -
sudo apt install -y nodejs
```
 
#### App bouwen op je computer
 
1. Kopieer de frontend broncode naar je Windows/Mac computer. Deze is te vinden in [Matter-App-Full](https://github.com/Vic-Syryn/EcoLux/tree/main/src/ui/matter-app-full)
2. Open een terminal in de frontend map en voer uit:
```bash
npm install
npm run build
```
3. Kopieer de gegenereerde `dist` map via WinSCP naar de Pi:
```
Doel: /home/ecolux/frontend/dist
```

#### App serveren met Nginx
 
```bash
# Installeer Nginx
sudo apt install nginx -y
 
# Maak een configuratiebestand aan
sudo nano /etc/nginx/sites-available/ecolux
```
 
Plak dit erin:
```nginx
server {
    listen 80;
    root /home/ecolux/frontend/dist;
    index index.html;
    location / { try_files $uri $uri/ /index.html; }
    location /api/ { proxy_pass http://localhost:8000/; }
}
```
 
```bash
# Activeer de configuratie
sudo ln -s /etc/nginx/sites-available/ecolux /etc/nginx/sites-enabled/
sudo rm /etc/nginx/sites-enabled/default
sudo nginx -t
sudo systemctl restart nginx
sudo systemctl enable nginx
```
 
Open de app in de browser: `http://<pi-ip>/`
 
---
### 3:
 
Kopieer via WinSCP of `scp` de volgende bestanden (te vinden in  naar [Hardware](https://github.com/Vic-Syryn/EcoLux/tree/main/src/Hardware)) `/home/ecolux/`:
 
| Bestand | Doel |
|---|---|
| `gpio_controller.py` | `/home/ecolux/gpio_controller.py` |
| `test_components.py` | `/home/ecolux/test_components.py` |
 
En naar `/home/ecolux/matter-api/`:
 
| Bestand | Doel |
|---|---|
| `main.py` | `/home/ecolux/matter-api/main.py` |
 
---
 
### 4: 
 
```bash
# Ga naar de matter-api map
cd /home/ecolux/matter-api
 
# Installeer dependencies in de virtual environment
/home/ecolux/matter-env/bin/pip install fastapi uvicorn websockets pydantic
 
# Test of de API werkt
/home/ecolux/matter-env/bin/uvicorn main:app --host 0.0.0.0 --port 8000
```
 
Open in browser: `http://<pi-ip>:8000/health` — moet `{"status":"ok"}` tonen.
 
Stop de test server met `Ctrl+C`.
 
---
 
### 5:
 
#### Matter API service
 
```bash
sudo nano /etc/systemd/system/matter-api.service
```
 
Plak dit erin:
 
```ini
[Unit]
Description=EcoLux Matter API
After=network.target
 
[Service]
Type=simple
User=ecolux
WorkingDirectory=/home/ecolux/matter-api
ExecStart=/home/ecolux/matter-env/bin/uvicorn main:app --host 0.0.0.0 --port 8000
Restart=on-failure
RestartSec=5
StandardOutput=journal
StandardError=journal
 
[Install]
WantedBy=multi-user.target
```
 
#### GPIO Controller service
 
```bash
sudo nano /etc/systemd/system/ecolux-gpio.service
```
 
Plak dit erin:
 
```ini
[Unit]
Description=EcoLux GPIO / Arduino Controller
After=network.target
 
[Service]
Type=simple
User=ecolux
WorkingDirectory=/home/ecolux
ExecStart=/usr/bin/python3 /home/ecolux/gpio_controller.py
Restart=on-failure
RestartSec=5
StandardOutput=journal
StandardError=journal
 
[Install]
WantedBy=multi-user.target
```
 
#### Beide services activeren
 
```bash
sudo systemctl daemon-reload
sudo systemctl enable matter-api
sudo systemctl enable ecolux-gpio
sudo systemctl start matter-api
sudo systemctl start ecolux-gpio
```
 
---
## <ins/> Deel 2: behuizing
## Stap  1: Onderdelen printen
Print de onderdelen van de plantenpot. De step files en 3mf met onderstaande print opstelling zijn te vinden in [CAD](https://github.com/Vic-Syryn/EcoLux/tree/main/cad). Wegens de omvang en vorm van het hoofdframe, wordt het aangeraden om dit op te splitsen in 4 delen. Naast het hoofdframe moeten er ook 3 pootjes en 1 onderkant geprint worden. Het wordt aanbevolen om deze met 15% infill, tree supports en een brim te printen.

<p align="center">
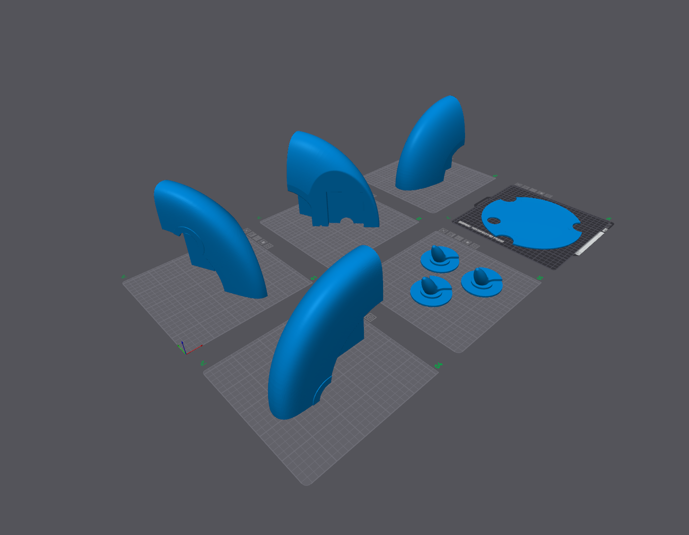
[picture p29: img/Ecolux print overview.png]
  
  Print overview
<p align="center">

## Stap 2: Delen hoofdframe aan elkaar lijmen
Lijm de 4 delen van het frame aan elkaar. Secondenlijm wordt hiervoor aangeraden.
<p align="center">
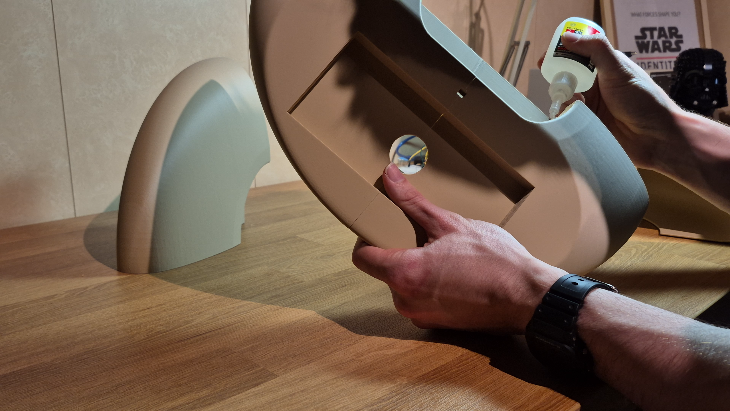
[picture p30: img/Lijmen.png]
  
  Lijmen
<p align="center">

## Stap 3: Led strip en LDR bevestigen
Bevestig de led strip in de voorziene groef en steek de LDR in in het voorziene gat.
<p align="center">
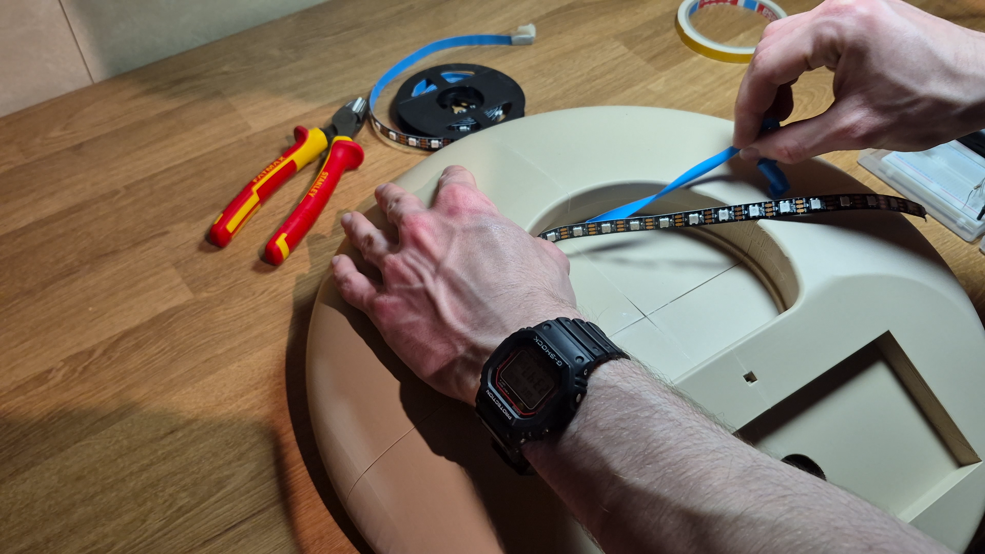
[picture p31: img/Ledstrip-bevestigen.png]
  
  Bevestigen ledstrip
<p align="center">

### Stap 4: Pootjes en elektronica
Bevestig de pootjes op het hoofdframe, leg de elektronica op de onderkant, met de stroomkabels door het gat. Zorg er vervolgens voor dat de onderkant op de goede plaats zit en verdraai de pootjes zodat de onderkant vastzit aan het hoofdframe.
<p align="center">
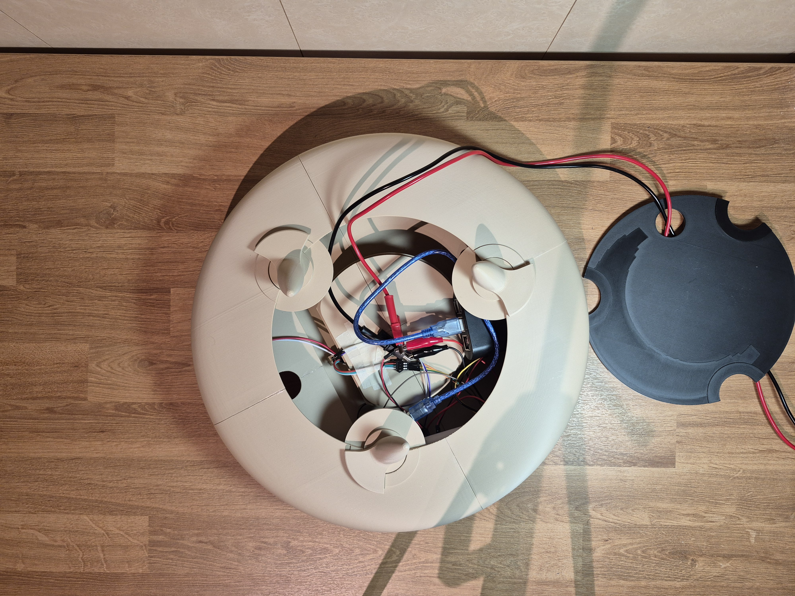
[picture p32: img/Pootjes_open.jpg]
  
  Bevestiging pootjes
<p align="center">

<p align="center">
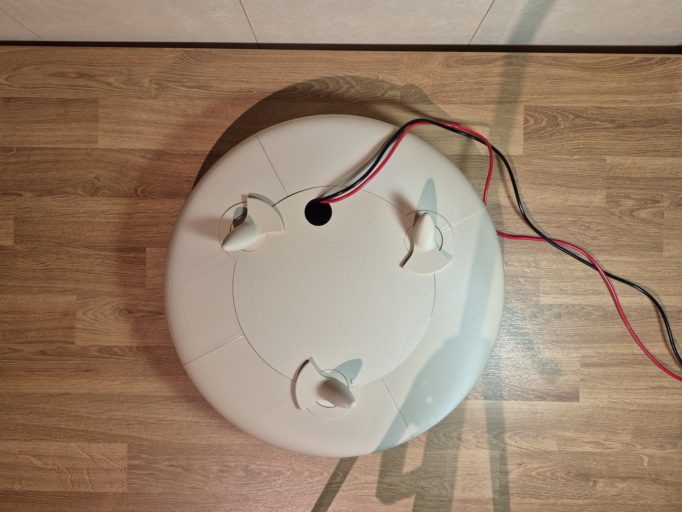
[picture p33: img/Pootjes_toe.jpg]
  
  Onderkant afgesloten
<p align="center">

### Eindresultaat
<p align="center">
  
  Ecolux
<p align="center">

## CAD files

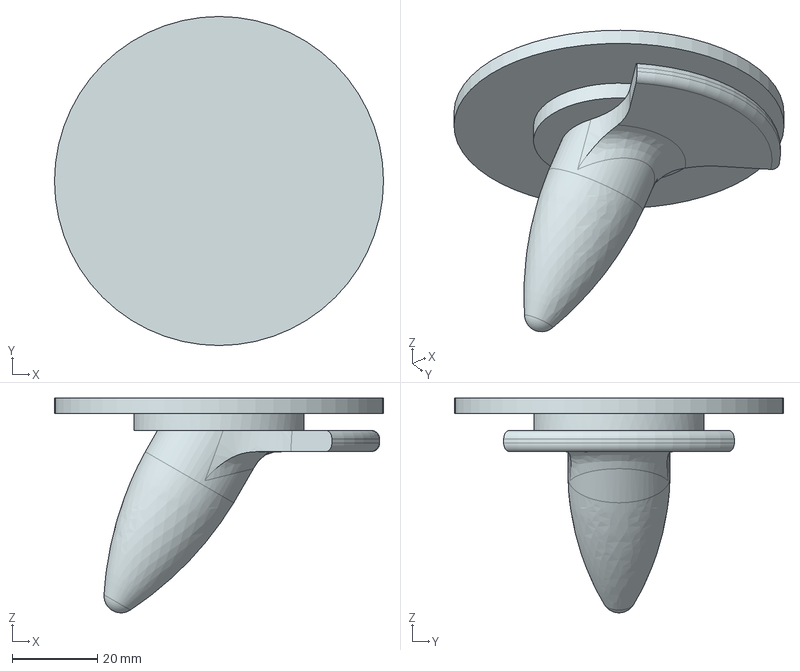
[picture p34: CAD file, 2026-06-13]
cad/Pootjes_1.stp
77.2 x 77.2 x 50.4 mm

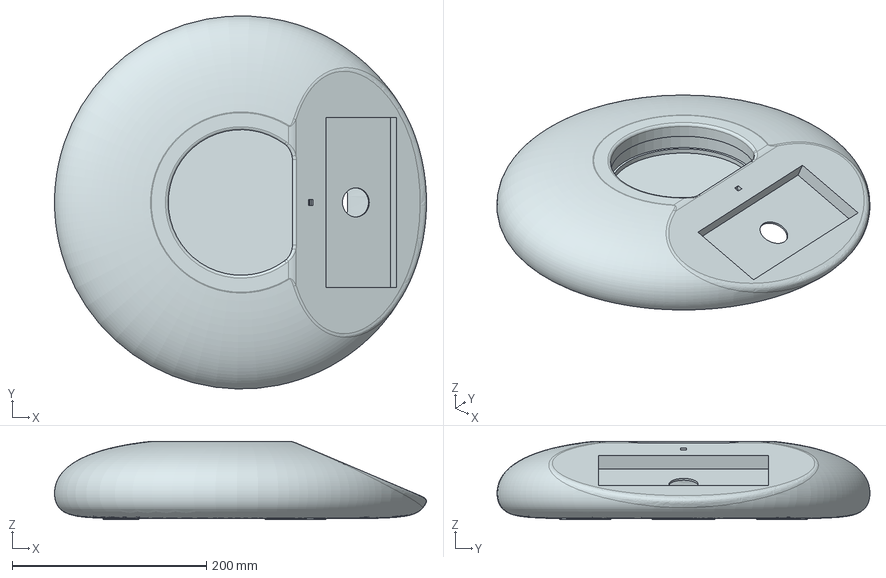
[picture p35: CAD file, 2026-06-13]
cad/Ecolux_Hoofstation_V2.stp
383.4 x 384.3 x 80.7 mm

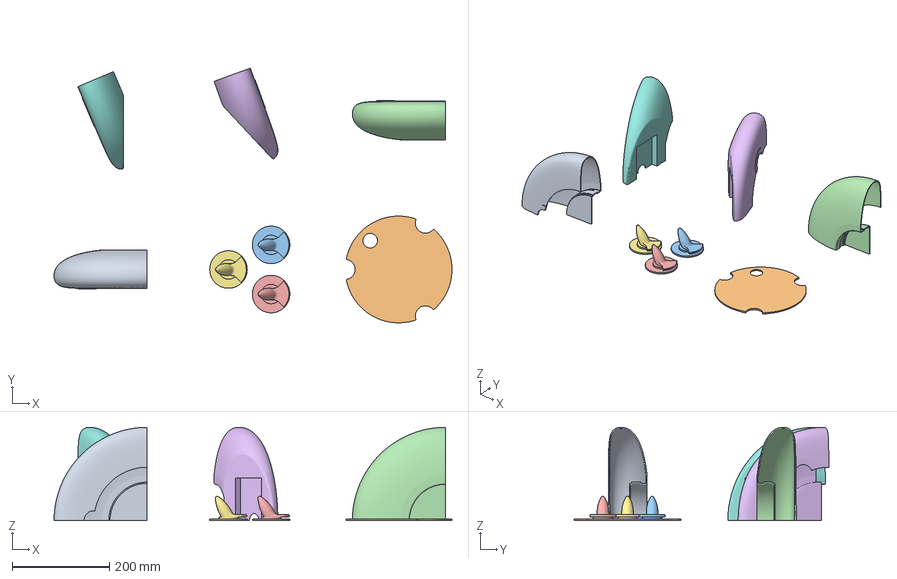
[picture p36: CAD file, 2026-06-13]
cad/Ecolux.3mf
818.9 x 524.0 x 192.3 mm
Ecolux_Hoofstation_V2.stp_B_A
Onderkant.stp
Pootjes_1.stp x 3
Ecolux_Hoofstation_V2.stp_A_A
Ecolux_Hoofstation_V2.stp_A_B
Ecolux_Hoofstation_V2.stp_B_B

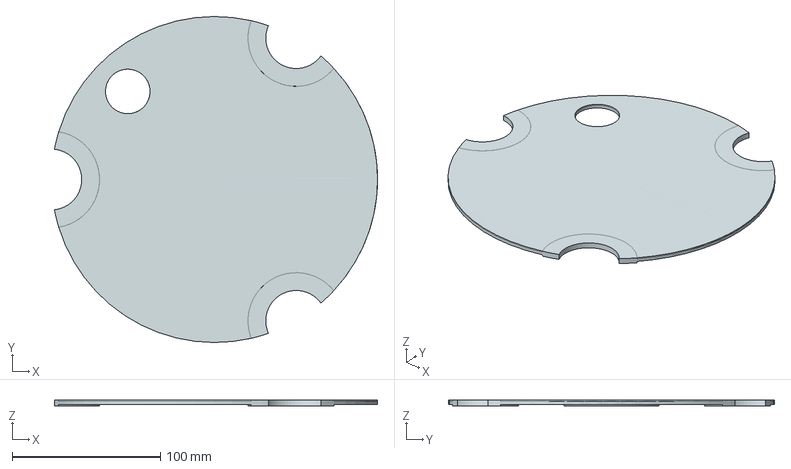
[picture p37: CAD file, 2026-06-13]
cad/Onderkant.stp
217.7 x 219.6 x 3.83 mm

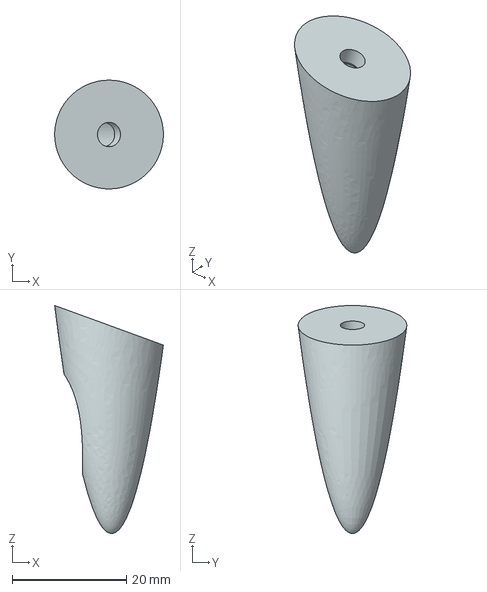
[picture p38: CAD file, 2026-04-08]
cad/Pootjes_Prototype_1.stp
19.1 x 19.1 x 40.0 mm

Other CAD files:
cad/Pootjes_Prototype.stp
cad/Pootjes_Prototype.prt

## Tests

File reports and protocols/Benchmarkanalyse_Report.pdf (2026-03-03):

# Benchmarkanalyse – Report

Projectinformatie
Projectnaam: Slim besparen @ Home
Onderzoekstype: Benchmarkstudie – oplossingsruimte (markt & technologie) Onderzoeker: Vic Syryn – Student Industrieel Ingenieur Industrieel Ontwerpen, UGent Campus Kortrijk
Uitgevoerd: 25-26 oktober 2025

Samenvatting van protocol
Dit benchmarkonderzoek maakt deel uit van de verkenningsfase binnen het project Slim besparen @ Home. Het heeft tot doel de huidige markt en technologieën te analyseren die (huishoudens) ondersteunen bij energie- en waterbesparing. Door bestaande slimme producten en systemen te vergelijken, wordt inzicht verkregen in wat al goed werkt, waar beperkingen liggen, en waar ontwerpopportuniteiten ontstaan voor een nieuw, gebruiksvriendelijker besparingsproduct.

Motivatie voor methodekeuze
Benchmarkonderzoek werd gekozen omdat het een mogelijk maakt om een vergelijking te maken van bestaande slimme systemen, sensoren en producten. Het helpt te begrijpen welke technologieën er al zijn, hoe gebruikers ermee interageren, en welke noden nog niet ingevuld worden.

Beschrijving van de sample (bronnen)
Er werden in totaal 10 producten en systemen onderzocht, geselecteerd op basis van hun relevantie binnen energie- en waterbesparing, dit werd opgenomen in Tabel 1. De lijst bestaan uit zowel commerciële als innovatieve concepten.
Tabel 1:
Nr. | Naam / Merk | Functie | Technologie / Sensoren | Doel | Prijs | Sterktes | Zwaktes
1 Google Nest | Hub | Slim display voor huisautomati sering | Voice control (Google Assistant), koppeling met sensoren (Nest Thermostat, Hue) | Energiebeheer, comfort, bediening | ± €100 | Intuïtieve spraakbediening, veel integraties | Vereist Google-ecosysteem, niet specifiek op besparen gericht
2 Tado° Smart | Thermostat | Slimme thermostaat | Temperatuursensor, geolocatie, AI-aansturing | Efficiënt verwarmen | ± €180 | Eenvoudig in gebruik, slim, energiebesparend | Enkel verwarming, beperkte feedback
3 NIKO Home | Control | Professioneel domoticasyst eem | Modulaire sensoren, centrale hub, bekabeld netwerk | Energiebeheer en automatisering | Vanaf ± €1500 | Betrouwbaar, uitbreidbaar, professioneel | Duur, installatiedrempel, niet toegankelijk voor iedereen
4 IKEA Dirigera | + Home Smart | Betaalbare domotica-oplossing | Bewegingssensoren, slimme stekkers, app | Automatisering & basisfeedback | ± €90 | Toegankelijk, eenvoudige installatie | Via een app, beperkte functies, geen diepgaande analyse

5 Eve Energy | (Matter) | Slimme stekker met meetfunctie | Energiemeting per toestel | Sluipverbruik meten & schakelen | ± €45 | Compact, inzicht per toestel | App vereist, geen centraal display
6 Netatmo | Smart Air Quality Monitor | Binnenklimaa tcontrole | CO₂-, vocht-, temperatuur-en geluidssensor | Gezond binnenklimaat bewaken | ± €120 | Geeft duidelijke feedback, goed design | Richt zich op luchtkwaliteit, niet specifiek op besparen
7 Sense Home | Energy Monitor | Energie-analyse via zekeringkast | AI-herkenning van apparaten, stroomklemmen | Real-time energieanalyse | ± €300 | Nauwkeurig, automatische herkenning | Technisch complex, installatie vereist
8 Aquasave | Smart Shower Timer | Waterbespare nde douchemeter | Flowmeter + timer | Doucheduur verkorten, water besparen | ± €25 | Eenvoudig, goedkoop, werkt direct | Geen koppeling met data, enkel lokale feedback
9 Ecobee | Smart Thermostat | Slimme thermostaat met sensoren | Temperatuur- en aanwezigheidsdetectie | Verwarming & airco optimaliseren | ± €200 | Comfort + besparing, AI-aansturing | Vooral op Amerikaanse markt gericht, enkel temperatuur
10 “Energy | Blossom” (concept) | Ambient feedbackobje ct | Licht- en kleurfeedback | Nudging via esthetische feedback | Conc ept | Emotionele, intuïtieve communicatie | Niet commercieel beschikbaar, conceptueel

Ruwe data (beschrijvingen & observaties)
Tijdens de analyse werden de volgende patronen opgemerkt:
- De meeste systemen gebruiken digitale displays of apps om feedback te geven (Nest, Tado°, Eve, Dirigera…).
- Slechts enkele concepten hanteren visuele, niet-digitale feedback (zoals de “Energy Blossom”).
- Domoticaoplossingen zoals NIKO Home Control zijn krachtig, maar weinig toegankelijk door hoge kost en installatiedrempel.
- IKEA en Eve mikken op een laagdrempelige instap, maar hun systemen stimuleren gedrag nauwelijks, ze tonen vooral data.
- Systemen zoals Sense en Netatmo werken sterk datagedreven, maar vereisen technische kennis.

Analyse
De data werden thematisch geanalyseerd volgens vier dimensies:
a. Gebruikersinteractie
De meeste slimme systemen vragen actieve betrokkenheid via apps of displays. Er is een hoge cognitieve belasting: gebruikers moeten instellingen beheren of data interpreteren. Intuïtieve, “ambient” feedback (zoals kleur, vorm of beweging) wordt amper toegepast.
b. Type feedback
Feedback is vaak numeriek of grafisch (grafieken, cijfers), wat weinig emotionele betrokkenheid oproept. Producten zoals de “Energy Blossom” tonen potentieel voor emotionele feedback, een zachtere, visuele nudgingvorm.
c. Innovatiegraad
Innovatie richt zich momenteel vooral op connectiviteit en AI, minder op ervaring en gedrag. Er is dus ruimte voor gedragsontwerp dat energie-efficiëntie combineert met emotionele motivatie.
d. Markttoegankelijkheid
De markt is sterk gepolariseerd:
- Professionele systemen (NIKO, KNX, Loxone) → duur, maar krachtig.

- Budgetoplossingen (IKEA, Eve) → toegankelijk, maar beperkt in functionaliteit. Hier ligt een gat voor betaalbare, maar betekenisvolle producten die gedrag ondersteunen zonder installatiecomplexiteit.
e. Effectiviteit van fysieke en emotionele feedback
Wetenschappelijke literatuur ondersteunt dat fysieke, emotionele en visuele feedbacksystemen effectiever zijn dan schermgebaseerde displays bij het stimuleren van duurzaam gedrag:
- Minder cognitieve belasting: Gebruikers reageren sneller op licht- en kleurveranderingen dan op numerieke data, omdat dit onbewust wordt verwerkt¹
- Sterkere emotionele connectie: Producten die gezichtsuitdrukkingen, kleur of beweging tonen, wekken empathie op en stimuleren positieve motivatie²
- Constante aanwezigheid: Een fysiek object in de leefruimte fungeert als subtiele, maar voortdurende herinnering, iets wat apps niet bieden³
- Bewezen impact: Studies tonen dat visuele feedbacksystemen energieverbruik tot 20–25% kunnen reduceren⁴
Deze bevindingen tonen aan dat emotionele, tastbare feedbackobjecten niet alleen gebruiksvriendelijker zijn, maar ook gedragsverandering beter ondersteunen en dan abstracte schermen met grafieken of cijfers.

1 Maan, S., Merkus, B., Ham, J., & Midden, C. (2011). Making it not too obvious: the effect of ambient light feedback on space heating energy consumption. Energy Efficiency, 4, 175-183. https://doi.org/10.1007/s12053-010-9102-6 (link.springer.com) (https://link.springer.com/article/10.1007/s12053-010-9102-6?utm_source=chatgpt.com)
2 Rodgers, J., & Bartram, L. (2011). Exploring ambient and artistic visualization for residential energy use feedback. IEEE Transactions on Visualization and Computer Graphics, 17(12), 2489–2497. https://doi.org/10.1109/TVCG.2011.196
3 Chalal, M. L. (2022). Visualisation in energy eco-feedback systems: A systematic review of good practice. Renewable and Sustainable Energy Reviews, 161, 112447. https://doi.org/10.1016/j.rser.2022.112447
4 Tiefenbeck, V., Wörner, A., Schöb, S., et al. (2019). Real-time feedback reduces energy consumption among the broader public without financial incentives. Nature Energy, 4, 831-
832. https://doi.org/10.1038/s41560-019-0480-5 (nature.com) (https://www.nature.com/articles/s41560-019-0480-5?utm_source=chatgpt.com)

Key Insights (Conclusies)
1. De huidige markt focust op data, niet op gedrag.
De meeste slimme producten informeren, maar motiveren niet. Gebruikers blijven passieve waarnemers.
2. Eenvoudige, visuele feedback ontbreekt.
De markt mist producten die intuïtief communiceren via kleur, vorm of beweging, zonder scherm of app.
3. Er is een kloof tussen high-end en low-end systemen.
Professionele domotica is te duur; goedkopere alternatieven missen diepgang.
4. Renovatiecontext biedt een ideaal instapmoment.
Tijdens renovatie staan bewoners open voor nieuwe technologieën; een slimme feedbackmodule kan hier eenvoudig geïntegreerd worden.
5. Comfort blijft doorslaggevend.
Een oplossing die comfort behoudt of verhoogt, heeft meer kans op langdurig gebruik.
6. Emotionele en fysieke feedback is krachtiger dan numerieke.
Producten die kleur, licht of emotie inzetten, genereren meer betrokkenheid en leiden tot duurzamere gedragsverandering.

Implicaties voor ontwerp
1. Eenvoud en automatisering:
Een product dat automatisch verbruik detecteert en feedback geeft zonder ingewikkelde instellingen.
2. Gebruik ‘ambient’ feedback in plaats van cijfers:
Kleurverandering, lichtintensiteit of subtiele expressies maken besparen voelbaar en begrijpelijk voor iedereen.
3. Emotionele connectie:
Een feedbackvorm die ‘reageert’ met een gezicht of emotie maakt de ervaring menselijker, en motiveert gezinnen en kinderen.
4. Integratie van meerdere bronnen:
Eén centraal, fysiek punt dat energie- en ventilatieverbruik samenbrengt.
5. Directe relevantie tijdens renovaties:
Het product kan geïntegreerd worden in het elektriciteitsnet of op batterijen werken zonder grote installatie.

Bronnen

AquaSave. (z.d.). AquaSave smart shower timer. Geraadpleegd op 9 oktober 2025, van
https://www.aquasave.com

DesignBoom. (2022, 14 mei). Energy Blossom: an ambient feedback concept for sustainable behavior. Geraadpleegd van https://www.designboom.com
Ecobee Inc. (2025). Ecobee Smart Thermostat Premium. Geraadpleegd op 9 oktober 2025, van https://www.ecobee.com
Eve Systems. (2025). Eve Energy – Smart Plug & Power Meter. Geraadpleegd op 9 oktober 2025, van https://www.evehome.com
Google. (2025). Google Nest Hub (2nd Gen). Geraadpleegd op 9 oktober 2025, van https://store.google.com
IKEA. (2025). Dirigera hub + Home Smart system. Geraadpleegd op 9 oktober 2025, van https://www.ikea.com
Netatmo. (2025). Smart Indoor Air Quality Monitor. Geraadpleegd op 9 oktober 2025, van https://www.netatmo.com
NIKO. (2025). NIKO Home Control – Domotica voor woningen. Geraadpleegd op 9 oktober 2025, van https://www.niko.eu
Sense Labs Inc. (2025). Sense Home Energy Monitor. Geraadpleegd op 9 oktober 2025, van https://sense.com
Tado°. (2025). Smart Thermostat – Intelligent heating control. Geraadpleegd op 9 oktober 2025, van https://www.tado.com
Maan, S., Merkus, B., Ham, J., & Midden, C. (2011). Making it not too obvious: the effect of ambient light feedback on space heating energy consumption. Energy Efficiency, 4, 175-183. https://doi.org/10.1007/s12053-010-9102-6 (link.springer.com) (https://link.springer.com/article/10.1007/s12053-010-9102-6?utm_source=chatgpt.com)
Ham, J. R. C., Midden, C. J. H., Maan, S. J., & Merkus, B. (2009). Persuasive lighting: The influence of feedback through lighting on energy conservation behavior. In Y. A. W. de Kort, & X et al. (Eds.), Experiencing Light 2009: International Conference on the Effects of Light on Wellbeing (pp. 122-128). Eindhoven University of Technology. https://research.tue.nl/en/publications/persuasive-lighting-the-influence-of-feedbackthrough-lighting-on (https://research.tue.nl/en/publications/persuasive-lighting-the-influence-of-feedback-through-lighting-on) (research.tue.nl) (https://research.tue.nl/en/publications/persuasive-lighting-the-influence-of-feedback-through-lighting-on)
Tiefenbeck, V., Wörner, A., Schöb, S., et al. (2019). Real-time feedback reduces energy consumption among the broader public without financial incentives. Nature Energy, 4, 831-
832. https://doi.org/10.1038/s41560-019-0480-5 (nature.com) (https://www.nature.com/articles/s41560-019-0480-5?utm_source=chatgpt.com)
Chalal, M. L. (2022). Visualisation in energy eco-feedback systems: A systematic review of good practice. Renewable and Sustainable Energy Reviews, 161, 112447. https://doi.org/10.1016/j.rser.2022.112447

Rodgers, J., & Bartram, L. (2011). Exploring ambient and artistic visualization for residential energy use feedback. IEEE Transactions on Visualization and Computer Graphics, 17(12), 2489–2497. https://doi.org/10.1109/TVCG.2011.196

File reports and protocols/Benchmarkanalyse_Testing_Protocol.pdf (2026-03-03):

# Benchmarkanalyse - Testing protocol

Project informatie
Projectnaam: Slim besparen @ Home
Onderzoekstype: Benchmarkanalyse – oplossingsruimte (markt & technologie) Onderzoeker: Vic Syryn – Student Industrieel Ingenieur Industrieel Ontwerpen, UGent Campus Kortrijk
Datum uitvoering: 25-26 oktober 2025
Aantal onderzochte cases: Minimaal 10 producten of systemen

Research goal & research questions
Doel van het onderzoek:
Het benchmarkonderzoek heeft als doel om bestaande oplossingen, producten en technologieën te analyseren die huishoudens helpen energie en water te besparen. Dit onderzoek situeert zich in de oplossingsruimte en dient om de huidige markt in kaart te brengen, te begrijpen wat er reeds bestaat en waar nog ruimte ligt voor innovatie. Onderzoeksvragen:
1. Welke bestaande slimme producten helpen mensen om thuis te besparen (energie, water, verwarming...)?
2. Welke technologieën of sensoren worden gebruikt om verbruik te meten, te voorspellen of zichtbaar te maken?
3. Hoe kunnen low-cost oplossingen ook toegankelijk zijn voor gezinnen met beperkte middelen?
4. Wat kunnen we leren van best practices in andere sectoren (bijv. mobiliteit, voeding) die duurzaam gedrag stimuleren?
5. Welke ontwerpstrategieën blijken effectief bij gedragsverandering rond duurzaamheid?

Motivatie voor methodekeuze
Benchmarkonderzoek werd gekozen omdat het toelaat om op een gestructureerde manier de bestaande markt en technologieën te analyseren. Waar de interviews inzicht boden in gebruikersnoden, helpt deze methode de oplossingsruimte te verkennen en bestaande technologieën te identificeren. Daarnaast ondersteunt benchmarking het formuleren van concrete ontwerprichtlijnen door trends, technologieën en innovaties in kaart te brengen.

Materials & tools
- computer met internettoegang

Step-by-step description
1. Oriëntatiefase:
Verkennen van bestaande slimme producten en energie-/waterbesparende systemen.
2. Zoekstrategie ontwikkelen:
Opstellen van zoektermen en selectiecriteria.
3. Data verzamelen:
Producten identificeren, specificaties en kenmerken documenteren.
4. Vergelijkende analyse:
Evalueren van functies, gebruikersgerichtheid, technologie en prijs.
5. Synthese:
Samenvatten van trends en opportuniteiten in een overzichtstabel.
6. Conclusie:
Formuleren van conclusies en mogelijke ontwerpcriteria.

Data collection & selection logic
Zoektermen (search queries):
“smart home energy saving device”, “smart thermostat comparison”, “water saving sensor system”, “eco-nudge design”, “energy feedback product”, “low-cost sustainable home technology”, “renovation smart energy solution”
Selectiecriteria:
- Product of technologie richt zich op energie- of waterbesparing.
- Gericht op huishoudelijk gebruik (niet industrieel).
- Bevat slimme of automatische functionaliteit (sensoren, feedback, dataverwerking).

- Ondersteunt bewustwording of gedragsverandering (bijv. feedback, visualisatie, nudging).
- Beschikbaar op de markt of conceptueel goed gedocumenteerd.

Data analysis
De verzamelde cases worden verwerkt in een vergelijkende benchmarktabel met:
- Naam & merk
- Functie
- Technologie / Sensoren
- Doel
- Prijs
- Sterktes
- Zwaktes

De resultaten van dit onderzoek worden opgenomen in een afzonderlijk Benchmarkrapport.

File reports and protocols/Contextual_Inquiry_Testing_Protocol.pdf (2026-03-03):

# Contextual Inquiry protocol

## Project informatie

Projectnaam: Slim besparen @ Home
Dit project onderzoekt hoe slimme, toegankelijke producten mensen kunnen helpen om thuis energie en water te besparen. De focus ligt op oplossingen die zowel financieel voordeel opleveren voor de gebruiker als milieuwinst genereren. De interviews kaderen binnen de Discovery-fase van het ontwerpproces waarin de probleemruimte wordt verkend.

Interviewer: Vic Syryn (vic.syryn@ugent.be), Student Industrieel Ingenieur Industrieel Ontwerpen

## Doelstelling en kadering

Dit onderzoek wil begrijpen waar en waarom verschillende soorten huishoudens moeite hebben om duurzaam te besparen, ondanks hun bereidheid om zowel geld als energie te besparen. Via contextual inquiries van diverse respondenten, waaronder ouderen, technologie-enthousiastelingen en gemiddelde gebruikers, kunnen de dagelijkse routines gedetailleerd bestuurd worden. Op deze manier komen zaken aanbod die via een klassiek interview niet mogelijk zijn. Het doel is om te ontdekken welke gedragsmomenten en contexten het meeste potentieel hebben om duurzame keuzes te beïnvloeden en hoe slimme producten hier ondersteunend kunnen optreden zonder extra belasting voor de gebruiker.

## Respondenten

De studie omvat drie uiteenlopende gebruikersprofielen om een breed spectrum van noden te verkennen:

1. Oudere alleenstaande met beperkte digitale kennis
2. Technologie-enthousiasteling die actief met besparen bezig is
3. Gemiddelde gebruiker (ouder of gezin) met beperkte tijd en wisselende motivatie

Door deze profielen te vergelijken, worden zowel uitersten als overlappende noden zichtbaar, maar wordt het ook duidelijk welke doelgroep de meeste nood heeft aan een oplossing.

Steekproefomschrijving (N = 3)

pseudonym | respondent type | datum | locatie
Christoff | Technologie-enthousiasteling | 18/10/2025 | Appartement
Axl | Projectmanager bij HVAC | 18/10/2025 | Huis
Jeannine | Alleenstaande oudere | 19/10/2025 | Appartement

## Onderzoeksvragen

1. Welke vormen van verbruik vinden mensen moeilijk te verminderen?
2. Wat motiveert mensen om thuis te besparen?
3. Hoe bewust zijn ze van hun dagelijks verbruik?
4. Welke routines hebben de grootste impact?
5. Wat verstaan gebruikers onder een “slim product”?
6. Hoe ervaren ze bestaande besparingshulpmiddelen?
7. Welke emoties of attitudes spelen mee bij besparen?

## Overzicht van de discussiegids en tijdsinschatting

- Deel 1 – Introductie
- Deel 2 – Voorstelling Interviewee
- Deel 3 – Beschrijving van de routine
- Deel 4 – Huidig gedrag & gewoontes
- Deel 5 – Motivatie & barrières
- Deel 6 – Slimme producten & feedback
- Deel 7 – Wrap-up

## Materialen

- Notitieboek voor observaties
- Smartphone voor audio-opnames
- Camera (smartphone) voor foto’s van de context
- Interviewgids (deze vragenlijst)
- Laptop voor transcriptie en analyse

## Discussiegids

Introductie

Bedankt voor je deelname aan dit onderzoek.

Ik zal starten met het project en mezelf kort voor te stellen.

Ik ben Vic Syryn en ik studeer aan de universiteit Gent campus Kortrijk met afstudeerrichting industrieel ingenieur industrieel ontwerpen.

Dit gesprek maakt deel uit van mijn project Sustainability @ Home, waarin we onderzoeken hoe slimme producten mensen kunnen ondersteunen bij het besparen van elektrische energie en water. De bedoeling is jouw dagelijkse ervaringen te begrijpen. Ik ben erg benieuwd naar jouw inzichten en ervaringen. Er zijn geen juiste of foute antwoorden. Ik ben gebaat bij jouw oprechte feedback rond de topics die we zullen behandelen.

Ik wil zeker nog onderstrepen dat alles wat straks in het gesprek aan bod komt in absolute confidentialiteit behandeld wordt. We zijn als studenten aan de Ugent namelijk gebonden aan de Europese privacyrichtlijnen. Voor de synthese met de inzichten en aanbevelingen worden individuele meningen sowieso ook geanonimiseerd. Je naam zal met andere woorden niet gekoppeld worden aan specifieke uitspraken. Een meer gedetailleerde beschrijving van onze intenties, verwerking van gegevens, en algemeen beleid kan je nalezen in de ‘Informed Consent’. Voor we van start kunnen met het interview, heb ik jouw expliciet akkoord nodig met dit document.

Ten slotte, had ik je ook graag gevraagd of ik straks dit gesprek mag opnemen met een voice recorder, om ons gesprek te kunnen herbeluisteren wanneer de analyse wordt gemaakt. Uiteraard wordt deze opname niet gedeeld met derden, en verwijderd na afloop van het project. Als u hiermee akkoord gaat, stel ik voordat we het interview beginnen.

----------------------------[invullen informed consent & start recording] ----------------------------

Contextuele vragen

Voorstelling Interviewee

Alvorens we in de materie duiken, wil ik graag eerst even kennismaken.

- Kan je kort iets over jezelf vertellen en met wie je samenwoont?
- Hoe ziet je huishouden eruit (alleen, met partner, gezin, huisgenoten…)?
- Kan je wat vertellen over je woning?
- Woon je in een huis of appartement? Huur je of ben je eigenaar?

Beschrijvijng van de Routine

In dit gebruikersgericht onderzoek wil ik inzetten op uw dagelijkse routine en waar er mogelijke problemen of opportuniteiten liggen met besparen. Vandaar dat het mij het best lijkt om uw dagelijkse gewoontes na te gaan op het vlak van elektrische energie en water.

- Hoe zou je jouw dagelijkse routine thuis beschrijven?
- Op welke momenten van de dag gebruik je meestal veel energie of water (zoals koken, douchen, verwarmen…)?
- Waar liggen voor jou persoonlijk de grootste uitdagingen als het gaat om besparen thuis?

Topic 1 Huidige gewoontes & bewustzijn

- Wanneer gebruik je volgens jou de meeste energie of water?
- In welke momenten van de dag zou je willen besparen?
- Volg je je gebruik op?
- Indien ja, hoe doe je dit?
- Indien nee, waarom niet?

Topic 2 Motivatie & barrières

- Wat motiveert jou om te besparen?
- Word jij in je dagelijkse leven thuis zelf geconfronteerd met uitdagingen rond energie- of waterbesparing?
- Indien ja:
- In welke situaties merk je dat het moeilijk is om te besparen?
- Hoe vaak doet dit soort situatie zich voor?
- Wie in je huishouden is er het meest bij betrokken of beïnvloed door dit verbruik?
- Indien neen:
- Ken je personen in je omgeving die wel moeilijkheden ervaren om te besparen?
- In welke situaties is dat volgens jou?
- Hoe vaak denk je dat dit voorkomt?
- Bij wie gebeurt dit vooral?
- In het kader van welke omstandigheden merk je dat mensen moeite hebben om bewust met verbruik om te gaan?
- Wat houdt je tegen om duurzamer te leven?
- Heb je eerder pogingen gedaan om je verbruik te verminderen? Hoe ging dat?

Topic 3 Slimme producten & gedrag

- Wat versta jij onder een “slim product”?
- Welke technologie of hulpmiddelen gebruik je al?
- Wat zou een product moeten doen om jou te helpen besparen zonder extra moeite?
- Zijn sommige problemen volgens jou groter of belangrijker dan andere?

Wrap-up

Wenst u zelf nog zaken toe te voegen?

De belangrijkste zaken die ik heb geleerd uit dit interview zijn, … Heb ik het juist begrepen als …?

Wat zijn de belangrijkste elementen waarvan u denkt dat ik die het meest zou moeten onthouden?

Hartelijk bedankt voor uw deelname, dit was erg waardevol voor het verdere onderzoek. Wilt u op de hoogte blijven van verdere resultaten of andere gebruikerstesten?

## Data-analyse

De resultaten van dit onderzoek worden opgenomen in een afzonderlijk rapport, waarin
na afloop de notities en audiofragmenten samengevat werden in korte verslagen per respondent. De analyse gebeurde op basis van herhalende patronen in gedrag, attitudes en motivaties. De belangrijkste inzichten werden vervolgens vertaald naar ontwerpimplicaties.

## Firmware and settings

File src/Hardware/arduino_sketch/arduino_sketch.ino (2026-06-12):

#include <Adafruit_NeoPixel.h>

#define LED_PIN    9
#define LED_COUNT  27

Adafruit_NeoPixel strip = Adafruit_NeoPixel(LED_COUNT, LED_PIN, NEO_GRB + NEO_KHZ800);

// Pins
const int PIN_LDR = A1;

// Tuning
const int SEND_INTERVAL_MS = 100;

const int LDR_DARK       = 822;
const int LDR_BRIGHT     = 972;
const int BRIGHTNESS_MAX     = 255;
const int ALERT_MIN_BRIGHTNESS = 150;  // strip altijd zichtbaar bij alert

// Cap totaal verbruik op ~40% zodat 120 LEDs binnen 5A PSU blijven
const uint8_t MAX_STRIP_BRIGHTNESS = 200;  // ~78% — ruim binnen 5A PSU

// State
bool          energyAlert = false;
bool          testMode    = false;
unsigned long lastSend    = 0;
String        cmdBuffer   = "";

uint32_t currentColor = 0;

// ── Helderheid ────────────────────────────────────────────────────────────────
int computeBrightness(int ldrRaw) {
  int stretched = map(ldrRaw, LDR_DARK, LDR_BRIGHT, 0, BRIGHTNESS_MAX);
  return constrain(stretched, 0, BRIGHTNESS_MAX);
}

// ── Strip helpers (non-blocking) ──────────────────────────────────────────────
void setStripColor(uint32_t color) {
  if (color == currentColor) return;
  currentColor = color;
  for (uint16_t i = 0; i < strip.numPixels(); i++) {
    strip.setPixelColor(i, color);
  }
  strip.show();
}

void clearStrip() {
  setStripColor(0);
}

// ── Setup ─────────────────────────────────────────────────────────────────────
void setup() {
  Serial.begin(115200);
  strip.begin();
  strip.setBrightness(MAX_STRIP_BRIGHTNESS);
  strip.show();
}

// ── Loop ──────────────────────────────────────────────────────────────────────
void loop() {
  unsigned long now = millis();

  // LDR
  int ldrRaw    = analogRead(PIN_LDR);
  int brightness = computeBrightness(ldrRaw);

  // Strip
  if (testMode) {
    setStripColor(strip.Color(255, 0, 0));
  } else if (energyAlert) {
    int alertBrightness = max(brightness, ALERT_MIN_BRIGHTNESS);
    setStripColor(strip.Color(alertBrightness, 0, 0));
  } else {
    clearStrip();
  }

  // Seriële commando's van Pi
  while (Serial.available()) {
    char c = Serial.read();
    if (c == '\n' || c == '\r') {
      if (cmdBuffer.length() > 0) {
        cmdBuffer.trim();
        if      (cmdBuffer == "ALERT:1")    { energyAlert = true; }
        else if (cmdBuffer == "ALERT:0")    { energyAlert = false; clearStrip(); }
        else if (cmdBuffer == "LED_TEST:1") { testMode = true; }
        else if (cmdBuffer == "LED_TEST:0") { testMode = false; clearStrip(); }
        else if (cmdBuffer == "RESET") {
          energyAlert = false;
          testMode    = false;
          cmdBuffer   = "";
          clearStrip();
        }
        cmdBuffer = "";
      }
    } else {
      if (cmdBuffer.length() < 32) cmdBuffer += c;
    }
  }

  // JSON telemetrie versturen
  if (now - lastSend >= SEND_INTERVAL_MS) {
    lastSend = now;
    Serial.print(F("{\"ldr\":"));
    Serial.print(ldrRaw);
    Serial.print(F(",\"brightness\":"));
    Serial.print(brightness);
    Serial.print(F(",\"energy_alert\":"));
    Serial.print(energyAlert ? 1 : 0);
    Serial.println(F("}"));
  }
}

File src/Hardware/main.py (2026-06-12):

from fastapi import FastAPI, HTTPException
from fastapi.middleware.cors import CORSMiddleware
from pydantic import BaseModel
from typing import Optional
import asyncio
import json
import os
from datetime import datetime, timezone
import websockets

app = FastAPI()

app.add_middleware(
    CORSMiddleware,
    allow_origins=["*"],
    allow_methods=["*"],
    allow_headers=["*"],
)

MATTER_SERVER_URL = "ws://localhost:5580/ws"
PLACEMENT_FILE = "/home/ecolux/matter-data/placements.json"
SETTINGS_FILE  = "/home/ecolux/matter-data/settings.json"

# ── Storage helpers ───────────────────────────────────────────────────────────

def _load(path: str) -> dict:
    if os.path.exists(path):
        with open(path) as f:
            try:
                return json.load(f)
            except json.JSONDecodeError:
                return {}
    return {}

def _save(path: str, data: dict):
    os.makedirs(os.path.dirname(path), exist_ok=True)
    with open(path, "w") as f:
        json.dump(data, f)

def load_placements() -> dict:  return _load(PLACEMENT_FILE)
def save_placements(d):          _save(PLACEMENT_FILE, d)
def load_settings() -> dict:    return _load(SETTINGS_FILE)
def save_settings(d):            _save(SETTINGS_FILE, d)

# ── Matter helpers ────────────────────────────────────────────────────────────

async def send_matter_command(command: dict):
    async with websockets.connect(MATTER_SERVER_URL) as ws:
        await ws.recv()
        await ws.send(json.dumps(command))
        return json.loads(await ws.recv())

async def get_nodes():
    async with websockets.connect(MATTER_SERVER_URL) as ws:
        await ws.recv()
        await ws.send(json.dumps({"message_id": "1", "command": "get_nodes", "args": {}}))
        return json.loads(await ws.recv())

# ── Models ────────────────────────────────────────────────────────────────────

class PlacementRequest(BaseModel):
    floor_id: str
    room_id: str
    x: float
    y: float

class SettingsRequest(BaseModel):
    problem_minutes: Optional[int] = None

class CommissionRequest(BaseModel):
    code: str

# ── Endpoints ─────────────────────────────────────────────────────────────────

@app.get("/devices")
async def get_devices():
    placements = load_placements()
    settings   = load_settings()

    try:
        response = await asyncio.wait_for(get_nodes(), timeout=5)
        nodes    = response.get("result", [])
        if not isinstance(nodes, list):
            nodes = []
    except Exception as e:
        return {"devices": [], "matter_error": str(e)}

    devices = []
    for node in nodes:
        node_id    = node.get("node_id")
        attrs      = node.get("attributes", {})
        on_off     = attrs.get("1/6/0", None)
        key        = str(node_id)
        s          = settings.get(key, {})
        prev_state = s.get("last_known_state", None)
        on_since   = s.get("on_since", None)

        if on_off is True and prev_state is not True:
            # Plug just turned on — always start a fresh timer
            on_since              = datetime.now(timezone.utc).isoformat()
            s["on_since"]         = on_since
            s["last_known_state"] = True
            settings[key]         = s
        elif on_off is False and prev_state is not False:
            # Plug just turned off — clear the timer
            on_since              = None
            s["on_since"]         = None
            s["last_known_state"] = False
            settings[key]         = s

        devices.append({
            "id":              node_id,
            "name":            f"Plug {node_id}",
            "type":            "smart_plug",
            "online":          node.get("available", False),
            "state":           on_off,
            "placement":       placements.get(key),
            "problem_minutes": s.get("problem_minutes", None),
            "on_since":        on_since,
        })

    save_settings(settings)
    return {"devices": devices}


@app.post("/devices/{node_id}/on")
async def turn_on(node_id: int):
    try:
        await send_matter_command({
            "message_id": "2", "command": "device_command",
            "args": {"node_id": node_id, "endpoint_id": 1, "cluster_id": 6,
                     "command_name": "On", "payload": {}}
        })
        s = load_settings()
        key = str(node_id)
        s.setdefault(key, {})
        # Set fresh on_since and clear last_known_state so get_devices()
        # always detects a clean on-transition and never reuses a stale timestamp
        s[key]["on_since"]         = datetime.now(timezone.utc).isoformat()
        s[key]["last_known_state"] = None
        save_settings(s)
        return {"status": "ok", "state": True}
    except Exception as e:
        raise HTTPException(status_code=500, detail=str(e))


@app.post("/devices/{node_id}/off")
async def turn_off(node_id: int):
    try:
        await send_matter_command({
            "message_id": "3", "command": "device_command",
            "args": {"node_id": node_id, "endpoint_id": 1, "cluster_id": 6,
                     "command_name": "Off", "payload": {}}
        })
        s = load_settings()
        key = str(node_id)
        s.setdefault(key, {})
        s[key]["on_since"]         = None
        s[key]["last_known_state"] = None
        save_settings(s)
        return {"status": "ok", "state": False}
    except Exception as e:
        raise HTTPException(status_code=500, detail=str(e))


@app.post("/devices/{node_id}/toggle")
async def toggle(node_id: int):
    try:
        await send_matter_command({
            "message_id": "4", "command": "device_command",
            "args": {"node_id": node_id, "endpoint_id": 1, "cluster_id": 6,
                     "command_name": "Toggle", "payload": {}}
        })
        # Clear last_known_state so get_devices() detects the transition
        # and sets a fresh on_since regardless of which way the toggle went
        s = load_settings()
        key = str(node_id)
        s.setdefault(key, {})
        s[key]["on_since"]         = None
        s[key]["last_known_state"] = None
        save_settings(s)
        return {"status": "ok"}
    except Exception as e:
        raise HTTPException(status_code=500, detail=str(e))


@app.post("/devices/{node_id}/placement")
async def set_placement(node_id: int, body: PlacementRequest):
    try:
        p = load_placements()
        p[str(node_id)] = {"floor_id": body.floor_id, "room_id": body.room_id,
                           "x": body.x, "y": body.y}
        save_placements(p)
        return {"status": "ok"}
    except Exception as e:
        raise HTTPException(status_code=500, detail=str(e))


@app.delete("/devices/{node_id}/placement")
async def remove_placement(node_id: int):
    try:
        p = load_placements()
        p.pop(str(node_id), None)
        save_placements(p)
        return {"status": "ok"}
    except Exception as e:
        raise HTTPException(status_code=500, detail=str(e))
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

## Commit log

2025-11-12 Update methodology description with timeline requirement
    Added a note to include a timeline of prototype evolutions.
2026-01-17 Invulling materialen en methoden
2026-01-18 toevoegen 4de prototype
2026-01-18 upload prototype 4
2026-01-19 bill of material
2026-04-08 Toevoegen cad model pootjes in cad
    [Pootjes_Prototype.prt, Pootjes_Prototype.stp, Pootjes_Prototype_1.stp]
2026-04-10 Aanvullen cognitieve en sensoriele ergonomie
2026-05-08 link code en bom
2026-05-08 aanpassingen BOM
2026-05-08 develop 4 circuit
2026-05-08 fix png circuit
2026-05-08 fix circuit ecolux
2026-05-08 fix afbeelding circuit
2026-05-28 toevoegen ledstrip test code
2026-05-28 Aanpassen develop 4 en arduino code
2026-06-12 aanvullen BOM
2026-06-12 Aanvullen BOM en toevoegen circuit
2026-06-12 Aanpassen circuit
2026-06-13 3D print en cad dv4
2026-06-13 Aanvullen BOM en methodologie
2026-06-13 bom typfout
2026-06-13 bom schrijffouten
2026-06-13 BOM toevoeging
2026-06-13 Toevoegen step files
    [Ecolux.3mf, Ecolux_Hoofstation_V2.stp, Onderkant.stp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]
